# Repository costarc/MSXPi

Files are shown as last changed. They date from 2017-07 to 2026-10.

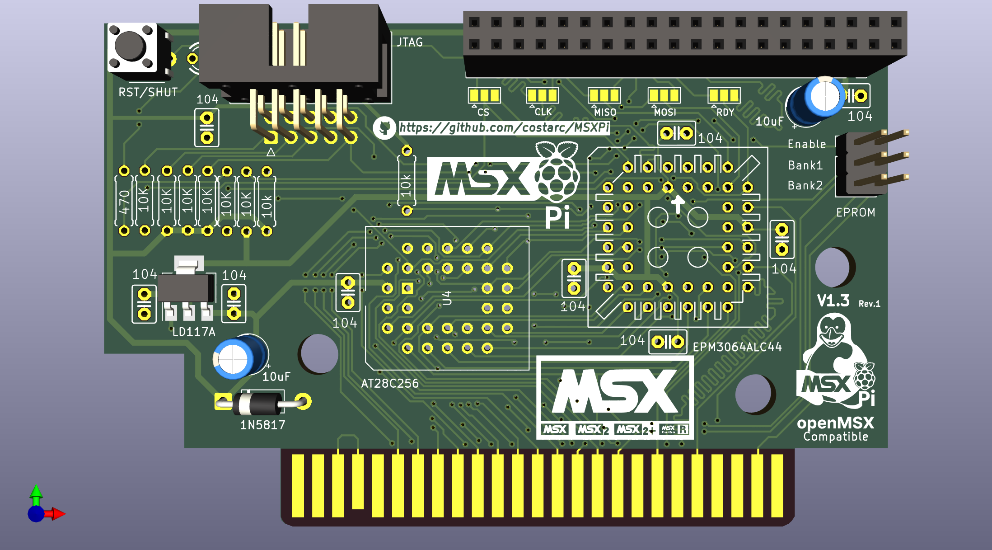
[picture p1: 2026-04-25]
hardware/Schematic/MSXPi.png

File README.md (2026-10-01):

# MSXPi

MSXPi is a hardware interface and software solution that lets MSX computers
control and use Raspberry Pi resources. The interface exposes I/O ports that
the MSX reads and writes, and the data appears on the Raspberry Pi side, where
a Python program (the *msxpi-server*) acts on it. Through it the MSX can reach
network drives, the internet, disk images, ROM archives, ChatGPT, an IRC
server, TCP/IP (via UNAPI) and the Raspberry Pi itself. A Raspberry Pi Zero W
or Zero 2 W is the recommended companion board.

MSXPi also exists as a virtual device for **openMSX**: the emulated MSX gets
the same commands and the same server, with no hardware at all. See
[Quick Start 2 - openMSX](#quick-start-2---openmsx-no-hardware-needed).

Version 1.6 is the current release. What changed is in
[Release_Notes](Release_Notes); how to use everything is in the
[documents](documents) folder.

**Version 1.6 breaks software compatibility with previous ROMs and servers.**
Upgrade the whole set together: ROM, msxpi-server, the client commands (`.COM`
files) and, on real hardware, the CPLD firmware. A v1.6 ROM on older CPLD
firmware still works, using the slower polled transfers. To stay on an older
ROM, use the server from the matching `release/vX.Y` branch.

**About the DOS.** MSXPi's own ROM contains **MSX-DOS 1 (1.03) only**. It does not
contain Nextor or MSX-DOS 2. MSXPi *coexists* with them: Nextor or MSX-DOS 2 come
from another disk interface in the same MSX (for example a MegaFlashROM SCC+ SD),
and MSXPi's commands, BASIC extension and UNAPI work alongside them. The
EEPROM holds two ROMs, picked with the bank jumper: MSX-DOS 1 (**BANK2**) or
the BIOS only - `CALL MSXPI` and UNAPI, no disk system (**BANK1**) - for use
next to Nextor / MSX-DOS 2.

Contents

1. [How the pieces fit together](#how-the-pieces-fit-together)
2. [Quick Start 1 - Real hardware](#quick-start-1---real-hardware-msxpi-interface--raspberry-pi)
3. [Quick Start 2 - openMSX](#quick-start-2---openmsx-no-hardware-needed)
4. [Using MSXPi: the p commands](#using-msxpi-the-p-commands)
5. [Bugs and known limitations](#bugs-and-known-limitations)
6. [Repository structure](#repository-structure)

How the pieces fit together
===========================

    Real hardware:
    MSX  <-- I/O ports $56 $57 $5A -->  MSXPi interface  <-- GPIO -->  Raspberry Pi
    (p.com, pcopy, msxarch,             (CPLD + EEPROM with            (msxpi-server.py,
     BASIC CALL MSXPI, ROM BIOS)         the MSXPi ROM)                 Python 3)

    openMSX:
    MSX  <-- I/O ports $56 $57 $5A -->  MSXPiDevice      <-- TCP :5000 --> msxpi-server.py
                                        (emulated CPLD)                    (on your PC)

* **MSX side** - the ROMs in the interface's 32 KB EEPROM and the `.COM`
  programs that you copy to your MSX disk or SD card. The EEPROM image,
  `msxpi32k.rom`, holds two 16 KB ROMs:
  * `msxpibios.rom` - MSXPi BIOS, MSX-DOS 1 disk driver, `CALL MSXPI` for
    BASIC, Ethernet UNAPI;
  * `msxpibas.rom` - the same without the disk system: `CALL MSXPI` and
    Ethernet UNAPI only.
* **Interface** - a CPLD decodes ports $56/$57/$5A and shifts bytes to and
  from the Pi; since v1.6 it also holds the Z80 /WAIT line while a byte is in
  flight, so the MSX can move data with INIR/OTIR.
* **Server side** - `msxpi-server.py`, which runs on the Pi (GPIO link) or on
  your PC next to openMSX (TCP socket link). Everything it needs lives in one
  folder, the *MSXPi home directory*: `/home/pi/msxpi`.

Quick Start 1 - Real hardware (MSXPi interface + Raspberry Pi)
==============================================================

You will need:

* An MSXPi interface (built from `hardware/`; assembly notes in
  `documents/MSXPi Assembly Instructions.txt`) with an AT28C256 EEPROM.
* A Raspberry Pi Zero W / Zero 2 W (not a Pico - it cannot run Linux), with
  the 40-pin header on the side that matches your PCB, a micro SD card of 8 GB
  or more, and a PC to prepare it.
* An MSX with a disk or SD interface running MSX-DOS 1, MSX-DOS 2 or Nextor
  (MSXPi itself only has MSX-DOS 1 in its ROM; MSX-DOS 2 / Nextor must come
  from that other interface),
  and a way to copy files from your PC onto that disk. A second disk interface
  (Nextor / MSX-DOS 2) next to MSXPi is the best way to use it.
* Only if the CPLD is not programmed yet: an Altera USB-Blaster and Quartus
  13.0 SP1 on Windows.

Do the steps in order. Each ends with a check, so you know where a problem is.

### Step 1 - Program the CPLD (skip if it is already programmed)

1. Connect the USB-Blaster to the JTAG connector of the interface. The
   interface must be in the MSX slot and the MSX switched on.
2. In Quartus: Tools -> Programmer, mode JTAG, *Add File*, pick the `.pof` for
   your board, tick *Program/Configure* and *Verify*, *Start*.

   | Board | File (in `hardware/CPLD_Project`) |
   |---|---|
   | V1.3 Rev.1 (and boards built for v1.3 to v1.5) | `MSXPi_v1.6.pof` |
   | V1.1 Rev.1, V1.2.1b | `v1.1/MSXPi_v1.6_wait.pof` |
   | v0.8.2 / v1.0 (PCB v0.7 Rev.7) | `v0.8.2/MSXPi_v1.6_polled.pof` |

3. **Check:** in MSX BASIC, `PRINT INP(&H57)` must not print 254 or 255 (that
   means no CPLD answered); `pver` shows the same build ID in readable form later. Older boards need a few extra settings - see
   `hardware/CPLD_Project/LEGACY_BOARDS.md` and `documents/Legacy Support.odt`.

### Step 2 - Write the ROM to the EEPROM with AT28C256.COM

The EEPROM (32 KB) holds `msxpi32k.rom`: two 16 KB ROMs, one per bank. It is
written from the MSX itself, so you need a working MSX with a disk drive and
the interface plugged in. The Raspberry Pi does not need to be attached yet.

| Bank jumper (as on the PCB) | EEPROM half | ROM | The MSX gets |
|---|---|---|---|
| **BANK2** (EEPROM A14 = CPU A15) | lower | `msxpibios.rom` | MSX-DOS 1 from the Pi, `CALL MSXPI`, Ethernet UNAPI |
| **BANK1** (EEPROM A14 = CPU A14) | upper | `msxpibas.rom` | `CALL MSXPI` and Ethernet UNAPI, no disk system and no extra drives |

1. Copy `software/target/at28c256.com` and `software/target/msxpi32k.rom` to
   your MSX disk or SD card. (Both are also on the MSXPi boot disk.)
2. Set the bank jumper to **BANK2**. The EEPROM can only be programmed in
   that position: the chip's write-protection commands only reach the right
   addresses when its A14 follows CPU A15.
3. Boot MSX-DOS (from your disk interface) and list the ROMs the tool can see:

        at28c256 /i

   If the interface already holds a bootable ROM, remove its enable jumper
   (`SLTSL`, `CS12` on some boards) first, otherwise the MSX finds it, boots
   from it and the tool cannot write. Note the slot number of the interface.
4. Write the ROM (2 is the slot number here; use yours):

        at28c256 /s 2 msxpi32k.rom

   Always write the whole 32 KB file in one go: the tool erases the entire
   chip before writing, so writing one 16 KB ROM on its own wipes the other
   bank. The tool write-protects the EEPROM (software data protection) when
   it is done. If your chip fails to program, repeat with `/r`, which writes
   slowly.
5. Switch the MSX off and set the jumpers for how you will use it:

   * **Booting MSX-DOS 1 from a disk image on the Pi:** close `SLTSL`, bank
     jumper on **BANK2**. The Pi must finish booting first, so the first cold
     boot takes a few minutes. Press ESC during boot to go straight to BASIC.
   * **With another disk interface (recommended):** close `SLTSL`, bank
     jumper on **BANK1**, and put MSXPi in a higher slot than the disk
     interface. The MSX boots Nextor / MSX-DOS 2 from the other interface;
     MSXPi adds no drives and uses almost no memory, and `CALL MSXPI` in
     BASIC and the Ethernet UNAPI are available.
   * **MSXPi ROM off:** remove `SLTSL`. MSXPi then works only through the
     `.COM` commands - no `CALL MSXPI` and no ROM UNAPI.

   The EEPROM answers in every page of its slot, so the bank that is not
   selected appears at 8000h. The two ROMs are built to tolerate each other
   there; always write them together, from the same `msxpi32k.rom`.
6. **Check:** in BASIC, `CALL MSXPIVER` prints the ROM version; with BANK1 it
   ends in "(no DOS)".

### Step 3 - Prepare the Raspberry Pi

Install a fresh Raspberry Pi OS Lite and run the MSXPi setup script. (The
old ready-made SD card image is no longer offered.)

1. Write *Raspberry Pi OS Lite (32-bit)* to the SD card with Raspberry Pi
   Imager (https://www.raspberrypi.com/software). In its settings choose user
   name `pi`, enable SSH and enter your WiFi details.
2. Boot the Pi, log in (SSH, or keyboard and HDMI) and run:

        wget https://tinyurl.com/MSXPi-Setup
        chmod 755 MSXPi-Setup
        bash ./MSXPi-Setup

   The script checks the Pi, the network and the clock, installs everything
   below, starts the server, checks that it runs, and reboots (a few minutes).
   It asks which board you have; to skip the question add `--board v1.3`,
   `--board v1.1` or `--board old` (see the table below). `--help` lists the
   other options (WiFi, `--no-reboot`, ...). It is safe to run again: it
   updates the server and repairs what is missing, and never overwrites
   `msxpi.ini`.

What the setup gives you (check it, or do it by hand):

* **Python 3** with the modules `requests`, `fs` and `RPi.GPIO`. `fs` needs
  `pkg_resources`, so a `setuptools` older than version 81 must be present
  (`python3 -m pip install fs "setuptools<81" --break-system-packages` if you do it
  by hand). The packages `unar`, `lhasa`, `unzip`, `mpv`, `alsa-utils` and
  `smbclient` are for unpacking archives, playing audio and reading network
  shares; `iptables` gives the MSX its network; `gcc` builds the native GPIO
  engine. PChess also needs the Python package `chess`
  (`requirements-pchess.txt`); the rest of the server works without it.
* **The MSXPi home directory `/home/pi/msxpi`**, owned by user `pi`. The path is
  built into the server (the environment variable `MSXPI_HOME` overrides it).
  It holds:

  | File | Purpose |
  |---|---|
  | `msxpi-server.py` and the `msxpi_*.py` modules (`msxpi_cmd_*.py`, `msxpi_transport.py`, `msxpi_settings.py`, ...), `mapper_detect.py` | the server and its modules |
  | `native/` | the native GPIO library `libmsxpi_gpio.so`, built on the Pi (without it the server falls back to slower Python GPIO and says so in its log) |
  | `msxpi.ini` | your settings, see below |
  | `disks/msxpiboot.dsk`, `disks/tools.dsk` | drives A: and B: for the MSX-DOS 1 boot mode |
  | `msxpi-monitor`, `msxpi-tcpip-setup.sh`, `update.sh` | helpers |

* **A systemd service** (`msxpi-monitor`) that starts the server at boot. To
  watch it work, run it by hand: `cd /home/pi/msxpi && python3 msxpi-server.py`.
* **msxpi.ini**, copied from the template that matches your PCB
  (`software/Server/Python/src`):

  | Board | Template |
  |---|---|
  | V1.3 (and later) | `msxpi-JumperRight.ini` |
  | V1.1 Rev.0 | `msxpi-JumperRight_PCBV1.1Rev.0.ini` |
  | Older boards | `msxpi-JumperLeft.ini` |

  A board **without** the shutdown push-button needs `var RPI_SHUTDOWN=none`.
  Optional keys: `OPENAIKEY` and `OPENAIMODEL` (ChatGPT), `RAPIDAPIKEY`,
  `FINNHUBKEY`, `TWELVEDATAKEY`, `ALPHAVANTAGEKEY` (stock quotes),
  `WIFISSID`, `WIFIPWD`, `WIFICOUNTRY`. From the MSX you can change any of
  them with `p set NAME value`.

Insert the SD card, plug the Pi into the interface **with its component side
facing you**, and switch the MSX on. The interface LED lights when the server
is running.

### Step 4 - Copy the MSX-side programs

Copy the contents of `software/target` (at least `p.com`, `pcopy.com`,
`pver.com`, `msxarch.com`, `msxarch.ini`, `LOADROM.COM`, `INL.CFG` and the
`.BAS` programs) to your MSX disk or SD card.

**Check:** at the MSX-DOS prompt type

        pver

It prints the board (build ID, CPLD, `/WAIT` yes or no) and the server version.
"Connection error" means the Pi is still booting (the first boot may take three
minutes), the interface is not seated, or the ROM and server versions do not
match. Press CTRL+ESC, wait five seconds, and try again.

### Step 5 - Connect to WiFi and the network

        p set WIFISSID Your Wifi Name
        p set WIFIPWD YourWifiPassword
        p wifi set
        p reboot

`p wifi` alone lists the interfaces and addresses. For TCP/IP programs (UNAPI:
InterNestor Lite, telnet, HGET) the Ethernet driver is in the ROM, and the Pi
builds the network behind it with `msxpi-tcpip-setup.sh` when the server
starts. If the Pi had no default route at boot, run `p netreset`. Then:

        MSR I           (MSX-DOS 1 only - do NOT run RAMHELPR)
        INL I
        HOST GOOGLE.COM

`HOST` printing an address means the whole path works. `p wlanreset` resets the
Pi's WiFi. Details: `software/UNAPI/README.md`.

### Step 6 - Try it

        p dir /home/pi/msxpi
        p run uname -a
        pcopy m:pver.com
        msxarch                     (browse and start ROM games from the network)
        LOADROM game.rom /N
        p chatgpt Tell me a fun fact about MSX

### Updating

* MSX disk (the `.COM` files): run `msxpiupd.bat` (network required).
* Server: run the setup script again, from the Pi or from the MSX:

        p run wget https://tinyurl.com/MSXPi-Setup
        p run chmod 755 MSXPi-Setup
        p run sudo ./MSXPi-Setup

* ROM: the updater downloads it but never writes it - repeat Step 2.

Update all three together. Run `p shut` before you switch the MSX off: the Pi is
powered by the MSX, and an SD card can be corrupted by a sudden power cut.

More detail with pictures: `documents/Quick Start.odt` and the "Hard Way" tutorial
(installing Raspberry Pi OS from scratch; Portuguese version available) in the
`documents` folder.

Quick Start 2 - openMSX (no hardware needed)
============================================

The MSXPi device for openMSX emulates the interface, including the CPLD /WAIT
flow control, and talks over a local TCP socket to the same `msxpi-server.py`
that runs on the Pi. The p commands, BASIC, msxarch, ChatGPT and UNAPI
networking all work as on real hardware, and what you write under openMSX runs
unchanged on the real interface.

### Windows: install everything in one step

1. Download
   [`msxpi-openmsx-install.bat`](https://raw.githubusercontent.com/costarc/MSXPi/master/software/Server/Setup/msxpi-openmsx-install.bat)
   (right-click the link, *Save link as*) and double-click it. It needs no
   administrator rights, and downloads everything from this repository and
   from the MSXPi build of openMSX.
2. It installs Python 3 and the packages the server uses, 7-Zip, Stockfish
   and mpv (with winget), then:
   * `C:\home\pi\msxpi` - the server, `msxpi.ini` and the `disks` folder
   * `C:\home\pi\msxpi\openMSX` - openMSX with the MSXPi device, the
     `MSXPi.xml` extension and `msxpibios.rom`
   * `C:\home\pi\msxpi\start-openmsx.bat` and an **MSXPi** desktop shortcut
3. Double-click the **MSXPi** shortcut. It starts the server in its own window,
   then openMSX as a Panasonic FS-A1WSX with the MSXPi and 4 MB RAM
   extensions. The MSX boots MSX-DOS from the MSXPi boot disk
   (`disks\msxpiboot.dsk`); no floppy image is needed.
4. Go on with [Step 4 - Try it](#step-4---try-it).

Notes:

* **Machine ROMs.** openMSX ships only the free C-BIOS ROMs. The FS-A1WSX
  needs its own system ROMs: put them in
  `%USERPROFILE%\Documents\openMSX\share\systemroms` (or in
  `C:\home\pi\msxpi\openMSX\share\systemroms`).
* **Internet on the MSX.** Run the installer with `-Network` (from a command
  prompt: `msxpi-openmsx-install.bat -Network`). It also installs the TAP
  driver, which asks for administrator rights once, and the launcher then sets
  up the MSX network when needed. See
  [Internet from the MSX in openMSX](#internet-from-the-msx-in-openmsx-windows).
* **Updating.** Run the installer again. It refreshes the server, the ROM and
  the extension, and replaces openMSX when a newer MSXPi build is required. It
  keeps `msxpi.ini` and the disk images.

Steps 1 to 3 below are the manual installation, for Linux and macOS or to set
things up by hand on Windows.

### Step 1 - Install openMSX with the MSXPi device

The official openMSX lives at https://github.com/openMSX/openMSX
(binaries and documentation at https://openmsx.org). The MSXPi device is not in
the official build yet, so download openMSX from the MSXPi fork instead:

* **https://github.com/costarc/openMSX/releases** - take the newest release for
  your operating system; the notes of each release say what it contains. Unpack
  it anywhere. It includes the MSXPi extension (`MSXPi.xml`) and the matching
  `msxpibios.rom`.
* Use the fork release, the `msxpibios.rom`, and the server from the same MSXPi
  version - the device, ROM and server share one protocol.
* If you keep your own openMSX, the two data files are also in this repository:
  `software/openMSX/share/extensions/MSXPi.xml` goes to openMSX's
  `share/extensions`, and `software/target/msxpibios.rom` goes to
  `share/systemroms` (the XML checks its sha1). The `MSXPiDevice` itself is only in
  builds of the fork.
* Two more extensions come from the same build (`software/build`, openMSX
  stage): `MSXPiBasic` - the BIOS-only ROM (`msxpibas.rom`), as on a board with
  the jumper on BANK1 - and `MSXPi32K`, the whole 32 KB EEPROM with the board's
  jumpers as openMSX settings, read at reset:
  `set msxpirom_bank BANK2|BANK1` (default BANK2) and
  `set msxpirom_sltsl ON|OFF` (default ON). `MSXPi32K` needs a fork build with
  EEPROM support in `MSXPiDevice` (branch `feature/msxpi-eeprom-jumpers`).

### Step 2 - Python and the MSXPi home directory

* **Python 3** (3.9 or newer; on Windows from python.org or the Microsoft
  Store, with *Add to PATH*).
* **Python modules:** `python -m pip install requests` is all the server needs
  to start. Some commands need more: `certifi` and `chess` for pchess, `Pillow`
  and `playwright` (then `python -m playwright install chromium`) for
  renderpage.
* **7-Zip** (`7z.exe` on the PATH) for zip, lzh, pma and 7z archives, used by
  msxarch and `pcopy /z`. On Linux/macOS install `p7zip`, `lhasa` and `unar`.
* **The MSXPi home directory.** The server has `/home/pi/msxpi` built in
  (set `MSXPI_HOME` to use another folder). On Linux and macOS create that
  folder. On Windows the path resolves on the *current drive*, so create
  `C:\home\pi\msxpi` and start the server from drive C:. Put in it:
  `msxpi-server.py`, `mapper_detect.py` and every `msxpi_*.py` module (all from
  `software/Server/Python/src`; the server imports them from its own folder), `msxpi.ini` (copy `msxpi-JumperLeft.ini`
  and rename it), and a `disks` folder with `msxpiboot.dsk` and `tools.dsk` from
  `software/target/disks`.
* Add the keys you need to `msxpi.ini` (for example `OPENAIKEY` for ChatGPT).
  Commands that only make sense on a Pi (`wifi`, `reboot`, `shut`, `play`) answer
  "Command not supported on this platform".

### Step 3 - Start the server, then openMSX

        cd C:\home\pi\msxpi           (Linux/macOS: cd /home/pi/msxpi)
        python msxpi-server.py

The server listens on TCP port **5000**. Now prepare a folder that openMSX uses
as disk A:. Call it `FloppyA`, copy `MSXDOS.SYS` and `COMMAND.COM` from
`software/target/disks` into it, and add the MSXPi commands from
`software/target`. Then start openMSX with the extension:

        openmsx -machine Panasonic_FS-A1WSX -ext MSXPi -diska FloppyA

Any MSX2 with 64 KB RAM will do, and Nextor on an SD/IDE image works too.
The fork also has an `MSXPiNoROM` extension (the ports without the ROM), for
trying `BLOAD"MSXPIEXT.BIN",R` the way an interface without an EEPROM is used.

**Optional: a different port.** The device takes the TCP port from the openMSX
setting `msxpiserver_port` (default 5000). Change it in the openMSX console
(F10) and the device reconnects at once:

        set msxpiserver_port 5001

Make the server listen on the same port with the environment variable
`MSXPI_PORT` (for example `set MSXPI_PORT=5001` on Windows before starting it). Use this when port 5000 is taken, or to run two
emulators with two servers.

### Step 4 - Try it

At the MSX-DOS prompt:

        pver
        p dir /
        p set
        msxarch
        p chatgpt Tell me a funny fact about MSX

`pver` reports `/WAIT: yes (burst)` when the device emulates the wait flow
control. "Connection error" means the server is not running, the ports differ,
or the ROM and server versions do not match. Read the log window of the server:
it prints every command it receives.

### Internet from the MSX in openMSX (Windows)

The MSXPi extension carries real network traffic, so InterNestor Lite, telnet,
HGET and the other UNAPI clients work in the emulator exactly as they do on
hardware. The emulated MSX gets its own subnet (192.168.99.0/24) and Windows
NATs it out through whichever interface carries your default route - the same
arrangement the Raspberry Pi uses, and for the same reason: bridging cannot
work over WiFi, because an access point will not forward frames whose source
MAC is not the associated station's.

This works best with an openMSX whose MSXPi device implements the v1.6
hardware /WAIT flow control (openMSX/openMSX#2194). An older build still
works: the ROM probes for wait mode, does not find it, and falls back to the
polled transport - the same path MSXPi has always used under emulation. What
you lose is the v1.6 speedup, not the connection.

**With the Windows installer**, run it with `-Network` instead of steps 1 and
2: it installs the TAP driver, and the MSXPi desktop shortcut sets up the
network (asking for administrator rights) whenever it is missing, including
after a reboot. Then go on with step 3.

#### Step 1: Install the OpenVPN TAP driver

Install OpenVPN (https://openvpn.net/community-downloads/) and keep the "TAP
Virtual Ethernet Adapter" component, or install the standalone tap-windows6
driver on its own. Afterwards an adapter named "OpenVPN TAP-Windows6" appears
in Network Connections - nothing else about OpenVPN is used or needs
configuring.

#### Step 2: Run the setup once, as Administrator

From an elevated PowerShell:

          powershell -ExecutionPolicy Bypass -File software/Server/Setup/msxpi-tcpip-setup.ps1

It reports what it did:

          adapter: OpenVPN TAP-Windows6  [TAP-Windows Adapter V9]
          uplink: Wi-Fi
          OpenVPN TAP-Windows6 up: 192.168.99.1/24 mtu 576
          NAT: 192.168.99.0/24 -> Wi-Fi
          dns: 192.168.1.254

and prints the InterNestor Lite settings to match. Note the "dns:" line - that
is the resolver the MSX should use.

This is NOT persistent across reboots; re-run it after a restart. To undo it
and give the adapter back to OpenVPN, add "-Down".

Windows generally allows only one NAT instance, and Docker Desktop, Hyper-V and
WSL each take one. If something already holds it the script names it and stops
rather than half-configuring.

#### Step 3: Start the server

          python msxpi-server.py

No administrator rights are needed for this part. It should print:

          eth: TAP device OpenVPN TAP-Windows6 up

If it says "TAP unavailable ... falling back to MockLink", something else has
the adapter open - a running OpenVPN session will do that. MockLink answers
every UNAPI call correctly and carries no traffic at all, so the MSX will look
configured and reach nothing.

#### Step 4: On the MSX

Start openMSX with the MSXPi extension, then:

          MSR I              (MSX-DOS 1 only - see below)
          INL I
          HOST GOOGLE.COM

`HOST` printing an address means the whole path works. The Ethernet UNAPI
driver is in msxpibios.rom, so nothing needs installing first: ETHUNAPI will
refuse, because the ROM already registers an ETHERNET implementation.

**Do not run RAMHELPR I.** It installs the UNAPI RAM helper on its own, and
MSR.COM installs the mapper support routines AND a helper - so MSR then finds a
helper already present and aborts, leaving INL to fail with "No mapper support
routines found". A cold boot clears it. Under Nextor or MSX-DOS 2, skip MSR
entirely: the mapper routines are already there.

If `HOST` answers "8: DNS not found" but the link is otherwise up, the resolver
is the problem rather than the network - INL.CFG ships with 1.1.1.1, and some
networks block public resolvers. Use the address the setup script printed:

          INL IP P 192.168.1.254

Using MSXPi: the p commands
===========================

Type `p` with no arguments (or `p /help`) to list them. All work under MSX-DOS 1,
MSX-DOS 2 and Nextor. Paths can be on the Pi, on the network (http, https, ftp,
smb) or on one of the virtual drives set with `p set`: `m:` (your local
server), `r1:` and `r2:` (MSX1 and MSX2 ROMs on msxarchive.nl).

| Command | What it does |
|---|---|
| `p ver`, `pver` | server version; `pver` also shows the board, CPLD build and /WAIT support |
| `p cd`, `p dir` | change and list the current path |
| `p run <cmd>` | run a command on the Pi; use `::` for a pipe |
| `p date` | set the MSX date and time from the Pi |
| `p set [NAME value]` | show or change MSXPi variables (saved in `msxpi.ini`) |
| `p wifi`, `p wifi set` | list interfaces / apply WIFISSID and WIFIPWD |
| `p wlanreset [secs]`, `p netreset [secs]` | reset the Pi's WiFi / rebuild its TCP/IP setup for UNAPI |
| `p music`, `p play`, `p vol` | audio playback and volume on the Pi |
| `p reload A:` (or `B:`) | reload a drive's disk image |
| `p reboot`, `p shut`, `p restart` | reboot / shut down the Pi, restart the server |
| `p chatgpt <question>` | ask ChatGPT (needs OPENAIKEY) |
| `p showpage [/4\|/6\|/8] <url>` | render a web page on the MSX screen |
| `pchess` | chess on an MSX2 (128 KB VRAM), local or over IRC (see `software/Client/src/PCHESS.md`) |
| `nitros` | on-demand NitrOS-9 console on the Pi with the MSXPi interface, or in openMSX on Windows/Linux, with file exchange; see [setup](documents/NITROS-Users-Guide.md) |
| `ssh user@host [port]` | interactive SSH terminal through the MSXPi Raspberry Pi; prompts and passwords appear on the MSX |
| `pcopy` | copy Pi/network file to the MSX drive (`/z` unpacks archives) or an MSX file to the Pi |
| `msxarch` | browse ROM repositories (listed in `MSXARCH.INI`) and start a game |
| `LOADROM name /N` | load a plain ROM or MegaROM from the network |
| `at28c256` | write the interface EEPROM |
| `msxpiupd.bat` | update the MSX-side files |

From BASIC use `CALL MSXPI("1,C000,dir /home/pi/msxpi")` (see `target/API.BAS`).
The full reference, with examples, is in `documents/MSXPi Users and Developers Guide.odt`.

Bugs and known limitations
==========================

* **Upgrade as a set.** A v1.6 ROM, server, `.COM` files and CPLD are meant to
  be used together. Mixed versions usually show up as "Connection error", not as
  a clear refusal.
* **/WAIT bursts need a v1.6 CPLD image and a board that wires /WAIT.** Boards
  built for v0.8.2 and v1.0 (PCB v0.7 Rev.7) have no /WAIT connection and run
  the polled transfers only. At the time of writing, disk writes from the MSX
  also use the polled transfer while reads use bursts.
* **Older boards need settings**: `RPI_SHUTDOWN=none` without the push-button,
  and `GPIO_CS_SETUP_NS=1000` on the v0.8.2 board. On that board the EPROM
  /OE jumper must be on CS1, never CS12, or programs that call EXTBIO (`p`,
  `pcopy`, `pver`) hang the MSX. See `hardware/CPLD_Project/LEGACY_BOARDS.md`.
* **MSXPi only carries MSX-DOS 1.** Nextor and MSX-DOS 2 are not in the MSXPi
  ROM; they run from another disk interface that MSXPi coexists with.
* **Booting MSX-DOS 1 from the Pi is slow and fragile.** It needs the Pi to
  finish booting first and depends on the disk images; use another interface
  with Nextor or MSX-DOS 2 for daily work. Do not delete files on drive A: in
  that mode.
* **A stuck transfer needs CTRL+ESC.** Hold CTRL and press ESC to abort, wait
  about five seconds while the server resynchronises, and retry. ESC alone is
  an ordinary key and never aborts a transfer. If commands keep failing, restart
  the server (`p restart`) or reboot the Pi.
* **msxarch and MegaROMs.** Mappers detected: plain, Konami, Konami SCC, ASCII8
  and ASCII16. Other mappers, ROMs that need more RAM than the MSX has, and some
  titles that rewrite their own bank switching are rejected with a reason or may
  not run. Bank-switch writes are patched by the server, so what runs is not byte-for-byte the original ROM.
* **UNAPI/TCP/IP.** Do not run `RAMHELPR` before `MSR` under MSX-DOS 1 (INL then
  fails with "No mapper support routines found"; a cold boot clears it). If
  `HOST` answers "8: DNS not found" the resolver, not the link, is the problem:
  use `INL IP P <address>`. Under openMSX on Windows the TAP setup script must be
  run again after every reboot, only one Windows NAT instance can exist (Docker
  Desktop, Hyper-V and WSL each take one), and if the server prints "falling back
  to MockLink" the MSX looks configured but reaches nothing.
* **The server on Windows and macOS** runs the commands that make sense there;
  `wifi`, `reboot`, `shut`, `play`/`music` and `vol` are Raspberry Pi only.
* **Hardware compatibility.** Some MSX models have unusual slot or bus
  implementations and may not work; MSX-DOS needs 64 KB RAM. The Pi header must
  face the correct way for your PCB (a Zero WH has its header on the wrong side
  for the standard PCB).
* **ChatGPT and stock commands** need your own API keys in `msxpi.ini`; no key
  ships with MSXPi.
* **Tests.** Server unit tests are in `software/Server/Python/tests`; the
  UNAPI harness is in `software/UNAPI/harness`.
* The PDF copies of the documents in `documents` may be older than the `.odt`
  files.

Report problems at https://github.com/costarc/MSXPi/issues.

Repository structure
====================

Branches:

    master          the most recent code; may change within minutes - expect bugs,
                    and fixes just as fast
    release/vX.Y    one branch per release (v0.8.2, v1.0, v1.1, v1.2.1b, v1.3,
                    v1.4, v1.5, v1.6); use these for a known-good state
    feature/*, fix/*, docs_*
                    short-lived working branches; they appear and disappear, and
                    I recommend you do not use them

Directories:

    MSXPi
    |-- software
    |   |-- asm-common
    |   |   |-- include          BIOS routines for assembly (msxpi_bios.asm, include.asm, ...)
    |   |   `-- transport        generator for the /WAIT burst transfer code
    |   |-- C-common
    |   |   |-- header           msxpi.h - the C BIOS API
    |   |   `-- lib              msxpi-bios.c
    |   |-- ROM/src
    |   |   |-- BIOS             BIOS-only ROM bank (msxpibios.asm); BASIC extension (msxpiext.asm)
    |   |   `-- MSX-DOS          disk driver and MSX-DOS 1 kernel sources
    |   |-- Client/src           p, pcopy, pver, msxarch, pchess, showpage, templates, at28c256
    |   |   `-- loadrom          the LOADROM.COM network patch
    |   |-- ROM-Patcher          ROM patch profiles used by msxarch
    |   |-- Server
    |   |   |-- Python/src       msxpi-server.py and its msxpi_*.py modules, mapper_detect.py,
    |   |   |                    ini templates, native GPIO engine (native/)
    |   |   |-- Python/tests     server unit tests
    |   |   `-- Setup            setup scripts (Pi and Windows), update.sh, msxpi-monitor
    |   |                        and its systemd unit
    |   |-- UNAPI                Ethernet UNAPI: sources, tools, INL, test harness, documentation
    |   |-- openMSX              MSXPiDevice source, extension XML, build files
    |   |-- target               everything you copy to the MSX (.COM, .BAS, ROM, disks)
    |   |-- docs                 mapper, ROM and PChess IRC design notes
    |   `-- make.bat, make.sh    build scripts for the MSX-side programs
    |-- hardware
    |   |-- CPLD_Project         VHDL, Quartus project, .pof images for every board
    |   `-- Schematic            KiCad schematic and PCB, Fabrication, BOM
    `-- documents                Users and Developers Guide, C BIOS Developers Guide,
                                 Quick Start, Legacy Support, tutorials

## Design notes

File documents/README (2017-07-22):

 |===========================================================================|
 |                                                                           |
 | MSXPi Interface                                                           |
 |                                                                           |
 | Version : 0.8.1                                                           |
 |                                                                           |
 | Copyright (c) 2015-2016 Ronivon Candido Costa (ronivon@outlook.com)       |
 |                                                                           |
 | All rights reserved                                                       |
 |                                                                           |
 | Redistribution and use in source and compiled forms, with or without      |
 | modification, are permitted under GPL license.                            |
 |                                                                           |
 |===========================================================================|
 |                                                                           |
 | This file is part of MSXPi Interface project.                             |
 |                                                                           |
 | MSX PI Interface is free software: you can redistribute it and/or modify  |
 | it under the terms of the GNU General Public License as published by      |
 | the Free Software Foundation, either version 3 of the License, or         |
 | (at your option) any later version.                                       |
 |                                                                           |
 | MSX PI Interface is distributed in the hope that it will be useful,       |
 | but WITHOUT ANY WARRANTY; without even the implied warranty of            |
 | MERCHANTABILITY or FITNESS FOR A PARTICULAR PURPOSE.  See the             |
 | GNU General Public License for more details.                              |
 |                                                                           |
 | You should have received a copy of the GNU General Public License         |
 | along with MSX PI Interface.  If not, see <http://www.gnu.org/licenses/>. |
 |===========================================================================|

Raspberry Pi setup

This is the process to setup MSXPi using the custom Raspbian Image
==================================================================

1. Download MSXPi ready-to-go Raspbian Jessie Lite minimal image zip file from:
https://www.dropbox.com/home/MSXPi/msxpi_raspbian.zip

2. Unzip the file.
Under Mac OS or Linux:
unzip msxpi_raspbian.zip

3. Insert / connect a micro-SD Card into the computer (8GB minimum)

4. Identify the device corresponding to the SD card. On Linux it should be /dev/sdb for example.
Make sure you do not use the device corresponding to your computer disk, or you will overwrite it, and loose all your data - for example, your SD card on Linux should never be /dev/sda, and on Mac OS should never be /dev/disk0 or /dev/disk1.

5. Transfer the raspbian image to the SD card.
For example, on Linux:
sudo dd if=msxpi_raspbian.zip of=/dev/sdb

On Mac OS:
sudo dd if=msxpi_raspbian.zip of=/dev/disk2

6. Insert the card on Raspberry Pi and switch it on. MSXPi server process will start automatically during boot.

This is the process to setup MSXPi using the official Raspbian Jessie Lite image
================================================================================

1. Download Raspbian Jessie Lite minimal image zip file from:
https://downloads.raspberrypi.org/raspbian_lite_latest
On this guide, the file downloaded was 2017-07-05-raspbian-jessie-lite.zip

2. Unzip the file.
Under Mac Os or Linux:
unzip 2017-07-05-raspbian-jessie-lite.zip

3. Insert / connect a micro-SD Card into the computer (2GB minimum)

4. Identify the device corresponding to the SD card. On Linux it should be /dev/sdb for example.
Make sure you do not use the device corresponding to your computer disk, or you will overwrite it, and loose all your data - for example, your SD card on Linux should never be /dev/sda, and on Mac OS should never be /dev/disk0 or /dev/disk1.

5. Transfer the raspbian image to the SD card.
For example, on Linux:
sudo dd if=2017-07-05-raspbian-jessie-lite.img of=/dev/sdb

On Mac OS:
sudo dd if=2017-07-05-raspbian-jessie-lite.img of=/dev/disk2

Recommended Raspberry distribution: Raspbian Lite
Do no enable Windows (graphical user interface) for better performance.

6. Insert the card on Raspberry Pi and switch it on. Logon using the default Raspbian credentials:
User: pi
Password: raspberry

7. Edit file /home/pi/msxpi-setup.sh
Change the “said” and “ask” to your wifi network name, and wifi password respectively.

8. run msxpi-setup.sh
sudo /home/pi/msxpi-setup.sh

9. Reboot Raspberry Pi. 
MSXPi server process will start automatically during boot.

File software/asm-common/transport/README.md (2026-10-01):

# Shared MSX payload engine

`payload.z80` is the source of truth for the C and ASM file/disk payload loops.
Run `python3 software/asm-common/transport/generate.py` after editing it. Generated files
are checked in; `--check` and both client build scripts reject stale output.
The C build uses an SDCC ABI-0 stack adapter, while ASM callers pass DE=buffer,
BC=count and HL=running 16-bit checksum. IX/IY and alternate registers survive.
Zero bytes perform no I/O. Carry on return reports cancellation; successful
bytes alone update the pointer/count/checksum. Public BIOS APIs are unchanged.

There is one receive loop: request a transfer, then wait for status zero. openMSX
emulates the CPLD at port level, so the MSX side has no emulator path. Checksum
folding, headers, index checking, retries and disk commit decisions remain in
the protocol layer. The disk driver stages each sector in a private 512-byte driver buffer,
then uses LDIR or the DOS XFER helper to copy the entire sector across RAM slot
boundaries. The kernel's shared SECBUF is never used as scratch, since another
disk kernel may retain filesystem metadata there. BASIC/early boot retain RDSLT/WRSLT when XFER is unavailable. Failed
receive sectors are never copied to the caller. The old SEND_P1 workarea byte
is reserved; its offset is unchanged. PCOPY uses 8192-byte blocks in both
directions, so comparisons no longer mix block size with transfer direction.

Polling is intentionally still used for file/disk payloads. UNAPI ETH_END
leaves /WAIT off, and the existing link claim/disk busy guard prevents network
transactions from interleaving. The payload kernel does not acquire the link
itself: callers must hold it over the entire command/response, not each block.
The abort key is CTRL+ESC, read straight from the key matrix (ESC row 7 bit 2,
CTRL row 6 bit 1). ESC alone is an ordinary key, so programs such as vi over
SSH can use it, and the BIOS key buffer is never touched. CTRL+STOP is not used
because the BIOS already acts on it. The key is sampled at most 256 completed
bytes apart and during busy polling. The shared helper preserves PPI upper
bits, keyboard row selection and IFF state.
The existing C header-byte primitives are unchanged.

The DOS ROM uses three pre-existing alignment holes for generated TX, wait,
and CTRL+ESC code. Their DEFS expressions enforce capacity; GETSLT/GETWRK and the
UNAPI placement assertions remain active. The full ROM fits without moving
these entry points or removing features. Standalone ASM clients include the
same code contiguously. Assembly was checked with zmac and sjasmplus.

Networking has a specialized bounded, keyboard-free TX checksum loop. It
keeps the sum in E and calls readiness directly instead of the single-byte
wrapper. Its protocol/checksum differs from the file protocol, so it does not
call the foreground payload kernel. Existing UNAPI /WAIT receive bursts now
use the native Pi engine when enabled; READY stays high for the entire burst,
including across the 256-byte boundaries used by ordinary payload calls. A
GPIO backend unable to hold READY now fails instead of silently substituting
unsafe per-byte transfers.

No CPLD register, wire protocol, or openMSX device change is introduced. A fresh
Quartus 13.0sp1 build of the current CPLD used 46/64 macrocells. Its timing
constraints are incomplete; a successful fit is not proof of a new timing
margin. General file/disk INIR/OTIR bursts and CPLD prefetch/mailbox changes are
not enabled by this revision. Their need should be decided from hardware
measurements of this common software bottleneck removal.

## Verification

The tests below live in `software/Tests/`, which is **not part of the release
branch** - it is carried on the development branches (`performance` and the
feature branches cut from it). Check one of those out to run them.

- `python3 software/Tests/test_payload_z80.py`: executes assembled SDCC output
  with libz80ex. RX/TX and ABI checks cover hardware/TCP status, lengths
  0/1/255/256/257/512/8192, checksum overflow, register preservation, IFF on/off,
  delayed readiness and CTRL+ESC both busy and ready (ESC alone must not abort). Network TX tests cover frame
  sizes through 1514, checksum, bounded timeout and absence of keyboard scans.
- `python3 software/Tests/test_native_gpio.py`: protocol framing/retries,
  native failure behavior, burst selection and wrapper boundaries.
- `cc -std=c11 -O2 -Wall -Wextra -Werror -fsanitize=undefined software/Tests/native_gpio_test.c -o /tmp/msxpi-native-test`
  followed by `/tmp/msxpi-native-test`: GPIO edge/byte model including continuous
  READY bursts and a timeout after partial completion.
- `python3 software/Tests/test_pcopy_receive.py`: rejects failed receive data
  before a disk write.
- `python3 software/Server/Python/src/test_msxpi_eth.py`: shuttle regression suite.
- `software/Tests/pcopy_emulator.py`: full copy/upload against isolated served
  disks. See its `--direction` and `--fault` options; use an MSXPi-enabled openMSX.

The Linux pcopy, p and templatc clients build. The unchanged msxarch.c source
has malformed literals and triggers an SDCC internal compiler error; this
revision does not repair that separate application. Windows SDCC 4.0 and Linux
SDCC 4.2 ABI-0 PCOPY builds were both exercised in openMSX.

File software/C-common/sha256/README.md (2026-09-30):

# SHA-256 for MSX (Z80)

Standalone SHA-256 for SDCC / Fusion-C programs on MSX. The block function
is hand-written Z80 assembly; it is the one PChess uses for its IRC position
digests (`Client/src/pchess_sha.c`), about 7x faster than SDCC's C.

| file | |
|---|---|
| `sha256.h` | API: `sha256_init/update/final`, one-shot `sha256()`, `sha256_hex()` |
| `sha256.c` | implementation; Z80 assembly under SDCC, portable C elsewhere |
| `sha256t.c` | test program: FIPS 180-2 vectors, a streamed message, timing |

```c
#include "sha256.h"
uint8_t d[32]; char hex[65];
sha256("abc", 3, d);
sha256_hex(d, hex);          /* ba7816bf... */
```

Messages of any length (the length counter is 64-bit); `sha256_update()`
takes up to 65535 bytes per call and can be called any number of times.
Not reentrant: one hash at a time, never from an interrupt handler.

On a 3.58 MHz Z80 a 64-byte block takes about 0.2 s (a message under 56
bytes is one block). Size: about 1 KB of code plus 300 bytes of tables and
work areas.

## Build the test

From `software`, as for any client program, but with this directory:

```bat
sdcc --code-loc 0x106 --data-loc 0 -mz80 --no-std-crt0 --opt-code-size fusion.lib ^
  -L ..\..\..\MSX\MSX-C\WorkingFolder\fusion-c\lib ^
  ..\..\..\MSX\MSX-C\WorkingFolder\fusion-c\include\crt0_msxdos.rel C-common\sha256\sha256t.c
hex2bin -e com sha256t.ihx
```

`SHA256T` prints PASS for each vector and the time for ten one-block
hashes. On a PC, `gcc sha256t.c -o sha256t` runs the same checks against
the C version.

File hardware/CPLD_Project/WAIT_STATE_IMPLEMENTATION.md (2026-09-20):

# MSXPi CPLD v1.6 — /WAIT flow control: implementation report

Implements `WAIT_STATE_SPEC.md`. Date: 2026-08-30.
Toolchain: Quartus II 13.0sp1 (`EPM3064ALC44-10`), GHDL for simulation.

**Status: VALIDATED ON REAL HARDWARE in legacy mode.** An earlier revision of
this work failed on hardware; the cause and fix are recorded below because the
lesson generalises.

> ### The bug that cost a hardware cycle - root cause
> `wait_mode` was written as a plain asynchronous set/reset pair, which Quartus
> infers as a **latch with its enable tied to GND**. That cell has no guaranteed
> power-up state on MAX3000A, and a VHDL `:= '0'` initialiser does nothing about
> it - it only fools the simulator. The device powered up **already in WAIT
> mode**, so every `IN ($5A)` fired an extra transfer carrying `$00`, the byte
> stream desynchronised permanently, and `/WAIT` could stall the Z80 during boot.
>
> The differential testbench passed because GHDL honours the initialiser. Zero-
> delay RTL simulation cannot model the power-up state of an unclocked cell, so
> equivalence proved from an assumed initial state proved nothing about silicon.
>
> **Fix:** the mode bit is clocked by the port-write strobe, so it is an
> ordinary register and the device's power-on reset clears it. The check is
> mechanical: `wait_mode` must NOT appear in the *User-Specified and Inferred
> Latches* table of `MSXPi.map.rpt`. `started` uses the same construct but is
> self-correcting - its clear is `spi_en = '0'`, true whenever the bus is idle.

### Hardware result (2026-08-30)

Both v1.6 images were flashed to the real interface and exercised against
`msxpi-server.py` on the Pi:

| Image | Result |
|---|---|
| `alternative/MSXPi_v16_shifter_only.pof` | **PASS** — `p run cat msxpi-server.py`, **142 KB transferred, no errors** |
| `MSXPi_v16.pof` | **PASS** — same test, no errors |

That closes **spec acceptance criterion 3** (backward compatibility: every
existing binary works unchanged with the mode register never written) and proves
the sentinel shift register matches `SPI_ByteTransfer()` on silicon.

**Still open: criteria 4 and 5.** WAIT mode itself has never been enabled on
hardware — nothing has written `$57`. Do not enable it until the Pi-side SPI is
rewritten; see §6, which is a correctness constraint, not a performance one.

---

## 1. Answers to the three questions

**Does it fit?** Yes, comfortably. The /WAIT feature costs **+1 macrocell** when
bolted onto the untouched v1.3 SPI engine (47 → 48 of 64).

**Can the engine be re-written more cheaply, e.g. as a bit shifter?** Yes, and
it is worth doing. Replacing the three-state FSM and the 3-bit `bitcount` with a
single *sentinel shift register* makes the whole design — /WAIT included —
**smaller than v1.3 was**: 45 macrocells against 47, with registers down from 24
to 20 and shareable expanders down from 33 to 13. That is the version shipped as
`MSXPi.vhd`.

**What does it take without redesigning the interface?** Nothing on the PCB, no
new pins, no change to the Pi-side protocol, and no change to any existing MSX
binary. `WAIT_n` is already on PIN_37 and routed to J1 pin 7. The one thing that
changed outside the VHDL is a single Quartus setting (see §3).

---

## 2. Fitter resource report (spec deliverable RC-1)

All rows are real `quartus_sh --flow compile` runs on `EPM3064ALC44-10`.

| Build | Macrocells | Registers | P-terms | Shareable exp. | Fitter |
|---|---|---|---|---|---|
| v1.3 baseline | 47 / 64 (73 %) | 24 | 190 | 33 / 64 | OK |
| v1.6 shipped — shifter + /WAIT, mode bit registered | 46 / 64 (72 %) | 21 | — | — | OK |
| v1.6 shifter only, /WAIT removed (diagnostic) | 44 / 64 (69 %) | 20 | — | — | OK |
| the earlier revision shifter engine + /WAIT (latched mode bit — BROKEN) | 45 / 64 (70 %) | 20 | 157 | 13 / 64 | OK |
| v1.6 shipped + BUSDIR fix for `$57` (§7) | 44 / 64 (69 %) | 20 | — | — | OK |

Pins are unchanged at 30 / 34 in every build. So the shipped v1.6 leaves **19
free macrocells**, against 17 for v1.3 — there is *more* headroom after this
change than before it, which is what pays for the timeout counter in §6 should
you decide to fit the clock wire.

### Where the saving comes from

v1.3 tracks transfer progress with three separate things: a one-hot
`spi_state` (3 registers), a `bitcount` up-counter (3 registers plus an adder
and its expander chain), and the `D_buff_pi` receive register (8).

v1.6 folds all three into one 10-bit register. It is loaded with a single `'1'`
at bit 0 when a transfer starts, and MISO shifts in underneath it. Because every
received bit stays *below* the sentinel and every bit above it is still zero,
the sentinel is always the highest set bit — so both phase tests are free of any
counter:

```
pi_sr(9 downto 1) = 0   ->  nothing received yet, this edge is E1 (the load)
pi_sr(9)          = '1' ->  all eight bits are in, byte complete
pi_sr(7 downto 0)       ->  the received byte
```

14 storage elements become 10, the adder and its expanders disappear, and the
edge map seen by `msxpi-server.py` is bit-for-bit the same.

---

## 3. The one non-VHDL change: `MAX7000_OPTIMIZATION_TECHNIQUE`

`MSXPi.qsf` moves from `BALANCED` to `AREA`.

This is not cosmetic — without it the shifter design **fails to place**, with
`Error (163103): Can't pack LABs`. It is not a capacity problem: the failing run
still reports only 43 of 64 macrocells. It is LAB fan-in. `EPM3064A` has 4 LABs
sharing a limited PIA, and the shifter concentrates a wide decode cone into
fewer, busier cells. `AREA` costs 2 macrocells (43 attempted → 45 placed) and
places cleanly.

Checked and rejected: `AUTO FIT` (still fails), removing the stale `MAX_LABS 20`
assignment (still fails), narrowing the `started` clear term (still fails). The
v1.3 baseline fits at 47 under `AREA` just as it does under `BALANCED`, so the
setting change costs nothing if you ever rebuild v1.3 from this .qsf.

---

## 4. Software-side note: the `$57` mode register (spec deliverable)

| Operation | Effect |
|---|---|
| `OUT ($57),$01` | /WAIT flow control **ON** |
| `OUT ($57),$00` | /WAIT flow control **OFF** |
| `OUT ($57),`anything else | ignored (reserved) |
| `OUT ($56),$FF` | existing reset — **also forces the mode OFF** (FR-5) |
| `IN ($57)` | `$0E` when off, `$8E` when on |

**Version numbering.** The CPLD firmware jumps 1.3 -> 1.6, skipping 1.4 and 1.5,
so that it tracks the BIOS/release version rather than running on its own
sequence. Neither 1.4 nor 1.5 was released. `MSXPIVer` is unaffected: it stays
`"1110"` because it identifies the hardware generation, not the release.

`$57` bit layout:

| Bits | Meaning |
|---|---|
| 7 | `wait_mode` read-back (not required by the spec; lets the driver confirm the write landed) |
| 6 | **RESERVED — must stay `0`.** BC-2 guard, see below |
| 5–4 | free for future use |
| 3–0 | `MSXPIVer`, now `1110` (was `1101`) |

**Why bit 6 is a guard and not spare space.** `msxpi_bios.asm:97` detects openMSX
by testing `$57` against `$FE`, so the port must never read `$FE` or `$FF`
(**BC-2**). `MSXPIVer` is already `1110`, so with the mode bit at 7, allocating
bits 6..4 and setting them all would produce exactly `1111_1110` = `$FE` and
break interface detection in the field. Holding bit 6 at `0` caps the port at
`$BF` for ever, whatever bits 5..0 are later used for.

**`pver.com` needs a one-line change.** `DESCHWVER` uses the *whole* byte as an
index into `iftable`, so any high bit set walks off the end of the table. It
should mask the version field first (`and $0F`) before indexing. Note it is
already imperfect at `$0E`: `iftable` has 15 entries (0–14) and index 14 is
`ifukn`, so v1.6 currently prints *"Could not identify"* — a v1.6 string wants
adding at the same time.

Power-up state is OFF, and the mode is cleared by the existing reset, so the
driver must re-enable it after every `resetMSXPI`.

With the mode ON, a plain `IN ($5A)` *both* starts the SPI transfer and stalls
the Z80 until the byte has landed, so a block read becomes:

```
        ld      a,$01
        out     ($57),a         ; enable hardware flow control
        ld      hl,buffer
        ld      bc,$0000 + DATA_PORT1   ; B = count, C = $5A
        inir                    ; 21 T-states/byte, no polling at all
        xor     a
        out     ($57),a         ; back to legacy behaviour
```

`OTIR` works the same way on the write side. Note that `INIR` uses `B` as the
counter, so a block is at most 256 bytes per instruction.

Two behaviours worth knowing about:

- A read of `$5A` in WAIT mode when the Pi is **not** ready (`SPI_RDY` low)
  neither stalls nor starts a transfer. It returns the stale buffer, exactly as
  a legacy read would, and the existing checksum/retry layer catches it. This
  is deliberate — see §5.
- A read-started transfer sends `$00` on MOSI (the shift register is empty after
  the previous byte), which matches what `PIREADBYTE` already does with its
  `xor a / out ($56),a`. The server discards that byte anyway.

---

## 5. Safety — and one place the spec is self-contradictory

The spec is right that §5 is the critical risk, but **SR-1 as written cannot be
implemented.** It asks for release "after a bounded number of `SPI_SCLK` edges
… regardless of Pi state". A counter clocked by `SPI_SCLK` cannot count when
`SPI_SCLK` stops, and the Pi stopping is the only failure that matters. An
edge-counted timeout would protect against nothing, and it cannot satisfy
acceptance criterion 5.

What was implemented instead is a **clock-free release**, which came out of
reading the PCB rather than the RTL:

> `SPI_RDY` (U2 pin 39) has **R8, 10K to GND** — a pull-*down*.

So `SPI_RDY` is a term in the `/WAIT` equation itself:

```vhdl
wait_assert <= wait_mode and SPI_RDY and spi_en and (SPI_en_s or (not started));
WAIT_n      <= '0' when wait_assert = '1' else 'Z';
```

The moment the Pi stops driving `RPI_READY`, R8 takes the line low and `/WAIT`
releases combinationally in ~24 ns, with no clock involved at all. That covers
every case where the GPIO is released:

| Failure | Covered? | Why |
|---|---|---|
| Ctrl-C on `msxpi-server.py` | **Yes** | `except KeyboardInterrupt: GPIO.cleanup()` at line 4055 releases the pad |
| Clean exit / restart | **Yes** | same cleanup path |
| Pi rebooted, powered off, unplugged, never booted | **Yes** | pad is an input, R8 wins |
| Pi alive but slow | **Yes** — no hang | stall is bounded by the Pi's byte time, see §6 |
| **`kill -9`** | **No** | no cleanup runs, the pad keeps its last level, `SPI_RDY` stays high and `SCLK` never ticks again |

That last row is demonstrated, not assumed — phase 6 of the testbench models it
and confirms `/WAIT` is still asserted 200 µs later. On hardware that is a hung
MSX needing a power cycle.

Closing it needs a real clock, and the board is one wire away from having one:

> `CLOCK` (the 3.58 MHz bus clock) is present on **J1 pin 42** and is currently
> routed nowhere — it is a single-pad net. CPLD pins **1, 2, 43 and 44**
> (`GCLR/`, `OE2/GCLK2`, `GCLK1`, `OE1`) are all unconnected.

A bodge from **J1.42 → U2.43 (GCLK1)** gives a free-running global clock. A
6-bit counter on it is 64 × 279 ns = **17.9 µs**, which lands just under SR-3's
20 µs ceiling, and the 19 spare macrocells cover it. That is the only way to
satisfy SR-1's intent and acceptance criterion 5 in full. It is a PCB change, so
it is flagged here rather than done — **BC-5** says not to.

For SR-4's bench escape hatch, `/WAIT` runs U2.37 → J1.7 with nothing else on
the net, so cutting that trace (or fitting a 0 Ω link in it) isolates the signal
without touching anything else.

---

## 6. The thing that decides whether this is worth enabling

§1 of the spec already says the Pi-side SPI is the real bottleneck. Now that
`/WAIT` exists, that stops being a performance argument and becomes a
**correctness** one, because the stall length *is* the Pi's byte time:

| Pi-side SPI | Stall per byte | vs SR-3's ~20 µs |
|---|---|---|
| current `SPI_ByteTransfer()` (Python bit-bang, `sleep(10 µs)` per tick) | 200–600 µs | **10–30× over** |
| rewritten in C / hardware SPI peripheral | ~10–20 µs | within budget |

A 200–600 µs stall freezes the Z80 completely — no interrupt service, and no
`/RFSH` cycles for machines whose DRAM refresh depends on them. That is what
SR-3 is protecting, and it is why **the Pi-side rewrite is a prerequisite for
enabling this mode, not a follow-up to it.** The CPLD half is done and costs
nothing while the mode register stays off.

---

## 7. The spec's open questions

**Q1 — is 8 `SPI_SCLK` edges the right timeout?** Neither 8 edges nor an
FSM-state timeout works, for the reason in §5: no `SCLK`, no count. Replaced by
the `SPI_RDY` gate, which needs no clock, plus the clock-wire recommendation for
the one case it cannot cover.

**Q2 — should `BUSDIR_n` be asserted for reads of `$57`?** Yes, it is a real
latent bug on expanded slots, and it is free — 44 macrocells with the fix
against 45 without, because "A is one of `$56`/`$57`/`$5A`" decodes more cheaply
than the same set with `$57` carved out. Left **off by default** so BC-1 holds
literally; the one-line change is in `MSXPi.vhd`, commented, next to the current
assignment. It needs its own hardware regression pass because it changes legacy
behaviour.

**Q3 — is the `D_buff_msx` latch intentional?** Intentional and necessary; keep
it. `D` is only valid while the write cycle is on the bus, and there is no clock
at that instant to register it with — the CPLD's only clock arrives later, from
the Pi. It is also what makes a `/WAIT`-stretched `OTIR` write safe: the Z80
holds `D` for the whole stretched cycle, so the E1 edge samples a stable value
no matter how long the stall ran. Converting it to a registered capture would
mean clocking it on `SPI_SCLK`, which is exactly what the E1 edge already does.

---

## 8. Verification performed

`./sim.sh` elaborates v1.6 and `MSXPi_v13_reference.vhd` **side by side** off one
set of stimulus, with a Pi model that reproduces `SPI_ByteTransfer()` exactly
(RDY high → spin on CS → tick → 8 bit clocks → tick → RDY low).

```
PHASE 1  legacy mode is cycle-identical to v1.3      9662 samples of
         D, BUSDIR_n, SPI_CS, WAIT_n compared        0 mismatches
         4 bytes received + 4 sent, both engines agree
         read of $5A does not start a transfer (BC-1)
PHASE 2  WAIT mode: $57 reads $1E; 4 INIR-style reads return correct
         data after a real stall; OTIR write reaches the Pi
PHASE 3  FR-5: reset clears the mode, $57 back to $0E, legacy restored
PHASE 4  SR-2: Pi gone -> /WAIT never asserts and no stale transfer armed
PHASE 5  soak: 32 INIR reads + 32 OTIR writes, all verified
PHASE 6  residual risk: kill -9 -> confirms /WAIT stays stuck (see §5)
ALL TESTS PASSED
```

Timing, from the fitted design (`EPM3064ALC44-10`, -10 speed grade):

| Path | Delay |
|---|---|
| `IORQ_n` → `WAIT_n` | 35.0 ns |
| `RD_n` → `WAIT_n` | 24.0 ns |
| `A[]` → `WAIT_n` | 35.1 ns |
| `SPI_SCLK` → `WAIT_n` (release) | 23.9 ns |

**SR-5**: the Z80 samples `/WAIT` on the falling edge of TW, ~1.5 T-states
(≈419 ns at 3.58 MHz) after `/IORQ` falls. 35 ns against 419 ns is better than
10× margin even after bus-buffer delay. The negative slacks in
`MSXPi.sta.summary` are against TimeQuest's default fictitious clock — there is
no `.sdc` in this project and the v1.3 baseline reports the same (−13.2 ns
against −16.2 ns), so it is not a regression.

### Two real bugs the differential test caught

Both would have shipped without it, and neither shows up in a single-DUT
testbench.

1. **A race between `RESET` and `spi_en`.** Adding any logic to the `spi_en`
   path made it settle one gate later than `RESET`. At the end of a reset write
   `RESET` falls first, which opens the FSM's async-set guard for a few
   nanoseconds and fires a spurious transfer. Fixed by keeping `spi_en` as one
   flat expression at the same depth as `RESET` and moving the anti-retrigger
   guard into the FSM condition. The comment in `MSXPi.vhd` says so, because the
   constraint is invisible otherwise and the next edit will re-break it.

2. **A desynchronising stale transfer.** A WAIT-mode read issued while the Pi
   was absent still armed a transfer nobody clocked; when the server came back
   it serviced that stale transfer and the byte stream was permanently one byte
   out of step. Fixed by gating the read-trigger on `SPI_RDY` (SR-2 applied to
   the transfer start, not just to the stall).

---

## 9. Files

| File | What it is |
|---|---|
| `MSXPi.vhd` | v1.6 — shifter engine + /WAIT. **The one in `MSXPi.qsf`.** |
| `MSXPi_package.vhd` | `MSXPIVer = "1110"`, plus `WAITMODE_ON`/`WAITMODE_OFF` |
| `MSXPi.qsf` | unchanged except `MAX7000_OPTIMIZATION_TECHNIQUE AREA` (§3) |
| `MSXPi_v16.pof` | new programming file, from the verified build |
| `MSXPi.pof` | **untouched v1.3 image**, deliberately left in place |
| `tb_MSXPi.vhd` | differential testbench, 6 phases |
| `MSXPi_v13_reference.vhd` | v1.3 frozen as the equivalence reference (sim only, not in the .qsf) |
| `sim.sh` | runs the whole suite; `--wave` also opens gtkwave |
| `alternative/MSXPi_v16_shifter_only.vhd` + `.pof` | shifter engine with **all** /WAIT logic removed - the diagnostic build, 44/64 |

`MSXPi.pof` was **not** overwritten. Flash `MSXPi_v16.pof` when you want v1.6;
the known-good v1.3 image stays available under its original name so the two
cannot be confused at the programmer.

### Which variant to flash

`MSXPi_v16.pof` is the deliverable. `alternative/MSXPi_v16_shifter_only.pof` is
kept because it is the build that isolated the power-up bug: same SPI engine,
**all** /WAIT logic physically removed, so it can never drive `/WAIT`. If a
future change to the /WAIT path misbehaves, flashing it splits the problem in
one step. Both are validated on real hardware.

A third variant existed during development - /WAIT bolted onto the untouched
v1.3 SPI engine - and has been removed. Once the mode bit became a proper
register it no longer placed on EPM3064A under any fitter setting, and the
shifter engine is now hardware-proven, so it had no remaining purpose.

---

## 10. Suggested hardware bring-up order

1. Flash `MSXPi_v16.pof`, **write nothing to `$57`**, and confirm `pdir`,
   `ploadr`, MSX-DOS boot and the Nextor driver all behave exactly as before
   (spec acceptance 3). This is the whole backward-compatibility claim, and it
   is the test that matters most — the mode register being off means nothing
   else in this change can be reached.
2. Confirm `IN ($57)` returns `$0E`.
3. Only then a small `.COM` that enables the mode, does one short `INIR`, and
   disables it again. Expect it to be *slower* than polling until the Pi-side
   SPI is rewritten, and expect the machine to feel unresponsive during the
   burst — that is §6, not a bug.
4. Do not run acceptance test 5 (`kill` the server mid-transfer) as `kill -9`
   until the clock wire in §5 is fitted; it will hang the MSX. `Ctrl-C` is the
   case that is covered, and is the one worth testing.

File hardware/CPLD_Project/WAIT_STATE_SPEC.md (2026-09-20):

# MSXPi CPLD — Hardware Flow Control via /WAIT

**Specification for a separate work stream.**
Target firmware: MSXPi CPLD v1.6 (`MSXPIVer = "1110"`)
Baseline: v1.3 (`MSXPIVer = "1101"`), `hardware/CPLD_Project/MSXPi.vhd`
Date: 2026-08-30

---

## 1. Purpose

Today every byte moved between the MSX and the Raspberry Pi costs the Z80 a
**software** handshake: `CHKPIRDY` polls `CONTROL_PORT1` bit 0 in a loop before
each byte. Measured from the source, that is **~330 T-states (~92 µs at
3.58 MHz) per byte**, on top of whatever the Pi itself takes.

This change makes the CPLD assert the MSX bus `/WAIT` signal so the **hardware**
performs the handshake. The Z80 then transfers bytes with block I/O
(`inir` / `otir`, 21 T-states/byte) and the CPU is stalled by hardware exactly
as long as the Pi needs, with no polling instructions at all.

### Why this is needed

The consumer is a new UNAPI networking driver (Ethernet UNAPI + InterNestor
Lite). InterNestor Lite runs **from the 50/60 Hz timer interrupt hook** and
calls the Ethernet driver on every interrupt. Two hard consequences:

1. The transfer loop must be short and bounded — there is ~59,600 T-states per
   interrupt slot, shared with the BIOS ISR.
2. `CHKPIRDY` currently scans the **ESC key on every byte** (`out ($AA),a` /
   `in a,($A9)` — the PPI keyboard row-select register). Doing that 60×/second
   from inside an ISR corrupts the BIOS keyboard scan. The new driver cannot
   use the existing primitives, and hardware /WAIT is what lets it stop needing
   them.

### What this change does NOT fix — read before starting

The Z80's 92 µs/byte is **not currently the dominant cost**. The Pi-side
bit-banged SPI in `msxpi-server.py` (`SPI_ByteTransfer`) is a Python loop with a
`time.sleep(0.00001)` per clock tick and a `while GPIO.input(SPI_CS): pass`
spin — realistically **200–600 µs per byte**.

So /WAIT alone yields perhaps **10–30 %**. Its full value is only realised once
the Pi-side SPI is rewritten in C or moved to the hardware SPI peripheral. The
two changes are complementary and the Pi-side one should be scheduled first or
in parallel. **Do not benchmark this change against the current Python
server and conclude it failed.**

---

## 2. Current design (baseline v1.3)

| Item | Value |
|---|---|
| Device | `EPM3064ALC44-10` (MAX3000A, **64 macrocells**, PLCC44) |
| I/O ports | `CTRLPORT1` = `$56`, `CTRLPORT2` = `$57`, `DATAPORT1` = `$5A` |
| `WAIT_n` | **PIN_37, routed, currently `'Z'` (never driven)** |
| Clocking | FSM clocked on `rising_edge(SPI_SCLK)` — SCLK is an **input from the Pi** |

Behaviour:
- Read `$56` → `"0000000" & SPI_RDY_s` (bit 0 = busy/ready)
- Read `$57` → `"0000" & MSXPIVer` (`$0D` today). Write to `$57` is **ignored**
- Read/write `$5A` → data byte; a write to `$56` or `$5A` starts an SPI transfer
- Write `$FF` to `$56` → asynchronous `RESET`
- `BUSDIR_n` asserted only for reads of `$56`/`$5A`

---

## 3. Functional requirements

**FR-1 — /WAIT assertion.** When the MSX performs an I/O read of `$5A` (or a
write to `$5A`/`$56` that starts a transfer) while the interface is not ready to
complete it, the CPLD shall drive `WAIT_n` low, and release it (return to `'Z'`)
as soon as the data is available / the transfer has been accepted.

**FR-2 — Tri-state when inactive.** `WAIT_n` shall be driven low only while
actively stalling, and be high-impedance at all other times. It must never be
driven high — `/WAIT` is an open-collector-style shared bus signal.

**FR-3 — Mode bit, default OFF.** /WAIT assertion shall be **disabled at
power-up** and enabled only by an explicit host action (see FR-4). In the
disabled state the device shall be **bit-for-bit behaviourally identical to
v1.3**.

**FR-4 — Enable/disable interface.** A write to `CTRLPORT2` (`$57`) shall set
the mode register:
- `D = $01` → /WAIT mode ON
- `D = $00` → /WAIT mode OFF
- other values → reserved, treat as no-op

Port `$57` is currently write-ignored by the CPLD and **no existing software
writes to it** (verified across the whole `software/` tree — every reference is
an `IN`/read for version detection). This makes it the safe choice.

**FR-5 — Reset clears the mode.** The existing `RESET` condition (write `$FF` to
`$56`) shall clear the mode register to OFF. This is deliberate: it gives any
legacy program a way to restore known-good behaviour, and gives the new driver a
fail-safe. The driver is expected to re-enable after each reset.

**FR-6 — Version bump.** `MSXPIVer` shall change from `"1101"` to `"1110"`, so
software can feature-detect /WAIT support by reading `$57`.

---

## 4. Backward-compatibility requirements — MANDATORY

Existing binaries in the field must keep working with no recompilation:
the ROM BIOS (`msxpibios.rom`), the MSX-DOS driver (`msxpidos.rom`), the Nextor
driver, and all `.COM` tools.

**BC-1 — Default-off is absolute.** With the mode register OFF the device must
behave exactly as v1.3: same port decode, same `SPI_RDY_s` semantics, same
reset, same `BUSDIR_n`, `WAIT_n` never driven.

**BC-2 — `$57` must stay readable and below `$FE`.** `msxpi_bios.asm:97` reads
`$57` and compares against `$FE` to distinguish real hardware from openMSX
(which returns `$FE`). The new value `"1110"` reads as `$0E` — compliant. Never
let `$57` return `$FE` or `$FF`.

**BC-3 — `CTRLPORT1` bit 0 semantics unchanged.** Legacy software polls it. It
must keep meaning the same thing in both modes, so a program that polls *and*
has /WAIT enabled simply finds the flag already settled.

**BC-4 — Reset behaviour unchanged.** Write `$FF` to `$56` must continue to
reset the SPI FSM and clear the data buffer, in both modes.

**BC-5 — No new pins, no PCB change.** `WAIT_n` is already on PIN_37 and routed.
The change must fit the existing PCB v1.1/v1.2 hardware.

---

## 5. Safety requirements — the critical risk

**There is no free-running clock on this CPLD.** The only clock is `SPI_SCLK`,
an input driven by the Pi. If the CPLD asserts `WAIT_n` and the Pi then stops
clocking — crash, process kill, SD-card stall, `Ctrl-C` on the server — there is
**no clock edge left to time out on, and the MSX hangs permanently** with no
recovery short of a power cycle.

This is the single most important thing to get right.

**SR-1 — Bounded assertion.** `WAIT_n` shall be released after a bounded number
of `SPI_SCLK` edges (suggest 8–16, i.e. one byte period) regardless of Pi state.
On timeout, release `/WAIT` and let the read return whatever is in the buffer;
the software layer's existing checksum/retry logic will catch the bad byte.

**SR-2 — Assert only during a Pi-active window.** Only assert `/WAIT` when a
transfer has actually been started and `SPI_CS` is active, i.e. when the Pi is
committed to clocking. Never assert while merely idle-waiting for the Pi to
become ready — that is the unbounded case.

**SR-3 — Maximum stall duration.** Total `/WAIT` assertion for any single I/O
cycle must stay under **~20 µs**. Longer stalls disturb VDP access timing and
interrupt latency. Note this interacts with §1: if the Pi needs 200–600 µs per
byte, /WAIT **cannot** cover the whole wait, which is another reason the
Pi-side SPI speed-up is a prerequisite for the full benefit.

**SR-4 — Independent escape hatch.** Provide at least one recovery path that
does not depend on the Pi: the FR-5 reset, and ideally a hardware option
(depopulated resistor or jumper on the PIN_37 net) so a bricked bus can be
recovered on the bench.

**SR-5 — Z80 /WAIT timing.** `WAIT_n` must be valid before the falling edge of
T2 of the I/O machine cycle to be sampled. Note the Z80 already inserts one
automatic wait state in I/O cycles. Verify against the MSX bus timing spec, not
just simulation.

---

## 6. Resource constraints

**RC-1 — Must fit `EPM3064ALC44-10`: 64 macrocells.** This is the binding
constraint and the main reason this is a separate work stream. The v1.3 design
already uses a meaningful share. Adding an FSM, a mode register, and a timeout
counter may not fit. **Report actual pre- and post-change macrocell utilisation
from the Quartus fitter as part of the deliverable.**

**RC-2 — If it does not fit**, options in order of preference:
1. Shrink the timeout counter (3 bits is enough for an 8-edge timeout)
2. Share/reuse the existing `bitcount` counter for timeout duty
3. Migrate to `EPM7128` (used in earlier revisions per the project history) —
   but this is a PCB/BOM change and needs your approval first

**RC-3 — Toolchain.** Quartus II (same version used for v1.3). Existing files:
`MSXPi.qpf`, `MSXPi.qsf`, `MSXPi.vhd`, `MSXPi_package.vhd`, plus the testbench
`tb_MSXPi.vhd` and `sim.sh` (GHDL).

---

## 7. Acceptance criteria

1. **Fitter**: compiles clean for `EPM3064ALC44-10`, 0 errors; macrocell usage
   reported.
2. **Simulation**: `tb_MSXPi.vhd` extended to cover — legacy mode is
   cycle-identical to v1.3; /WAIT asserts and releases correctly in WAIT mode;
   the SR-1 timeout fires when `SPI_SCLK` stops; reset clears the mode.
3. **Regression on real hardware**: with the mode register never written (i.e.
   every existing binary), the MSX boots and all current MSXPi software works
   unchanged — `pdir`, `ploadr`, MSX-DOS boot, Nextor driver.
4. **New path on real hardware**: a small test program enables WAIT mode, runs
   an `inir` burst read, and gets correct data; timing measured against the
   legacy polled loop.
5. **Recovery verified**: kill `msxpi-server.py` mid-transfer with WAIT mode
   enabled — the MSX must not hang.

---

## 8. Deliverables

- Updated `MSXPi.vhd` / `MSXPi_package.vhd`
- Updated `tb_MSXPi.vhd` with the new cases
- New `.pof`
- Fitter resource report (before/after)
- Short note documenting the `$57` mode register for the software side

---

## 9. Open questions for the implementer

1. Is 8 `SPI_SCLK` edges the right timeout, or should it be tied to the FSM
   state instead of an edge count?
2. `BUSDIR_n` is currently **not** asserted for reads of `$57`
   (`is_ctrl_or_data` excludes `CTRLPORT2`) — a latent bug on expanded slots.
   Worth fixing in the same pass?
3. `D_buff_msx <= D when (...)` infers a latch. Intentional, or should it become
   a proper registered capture while the design is being touched?

---

## 10. Context

Consumer of this change: MSXPi UNAPI networking (Ethernet UNAPI + InterNestor
Lite). Test machine: **Canon V-25 (MSX2)** with MegaFlashROM SCC+SD 512 KB
mapper. This CPLD work is a **prerequisite for good performance but not for
first function** — the UNAPI work proceeds in parallel against the legacy
polled transport.

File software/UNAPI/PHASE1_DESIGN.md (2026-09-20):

# MSXPi Ethernet UNAPI — Phase 1 Design

Branch: `unapi-ethernet` (off `MSXPiv1.6`)
Date: 2026-08-30
Baseline: CPLD v1.6 (`MSXPIVer "1110"`), BIOS v1.6, post-`498316e`

**Goal:** implement the 12-routine **Ethernet UNAPI** on MSXPi, and run
**InterNestor Lite** on top of it to supply the full 30-routine TCP/IP UNAPI —
so that stock UNAPI applications (telnet, HGET, SNTP, MSXHUB) work on a
Canon V-25 with an MSXPi.

---

## 1. Transport baseline — what v1.6 actually gives us

### 1.1 CPLD semantics (read from `MSXPi.vhd`, not assumed)

| Condition | Behaviour |
|---|---|
| `OUT ($57),$01` | `wait_mode` = 1 |
| `OUT ($57),$00`, or `OUT ($56),$FF` (reset) | `wait_mode` = 0 |
| `IN ($57)` | `$0E` mode off, **`$8E` mode on** (bit 7 = mode read-back) |
| `wait_mode=0` | identical to v1.3 — `WAIT_n` never driven |
| `wait_mode=1`, `IN ($5A)`, `SPI_RDY=1` | **starts a transfer AND stalls the Z80** until the byte completes |
| `wait_mode=1`, `IN ($5A)`, `SPI_RDY=0` | no transfer, no stall — returns the stale buffer |

`spi_en <= ... or (wait_mode='1' and readoper='1' and is_data='1' and SPI_RDY='1')`

The `SPI_RDY` gate is the safety property that makes this usable: with no Pi
present, a burst read degrades to reading stale bytes instead of hanging the bus.

### 1.2 The fast path exists and is unused

`grep` across the whole `software/` tree: **nothing writes `$57`, and there is
no `INIR`/`OTIR` anywhere.** The v1.6 speed-up (~80%) came from tightening
`CHKPIRDY`'s poll loop and the Pi-side `/dev/gpiomem` fast GPIO path — all in
**legacy mode**.

So the hardware `/WAIT` burst path has **no consumer yet**. This driver will be
the first, and it inherits the fast path with no legacy-compatibility burden.

### 1.3 Per-byte cost

| Path | Z80 cost/byte |
|---|---|
| `PIREADBYTE` (legacy, current) | ~240 T-states (~67 µs) — was ~330 T |
| `INIR` with hardware `/WAIT` | 21 T-states + however long the Pi stalls us |

**The Pi is still the dominant term and its current value is unmeasured.** The
profiler added in v1.6 (`MSXPI_PROFILE=1`) exists precisely to answer this.
See §6 — this number gates the MTU decision and nothing else in this document
depends on it.

### 1.4 Doc nit found while reading

`MSXPi.vhd` D_out process: one comment line says *"$0E disabled, $1E enabled"*,
the later block correctly says *"Reads $0E with the mode off, $8E with it on."*
The code (`wait_mode & '0' & "00" & MSXPIVer`) gives **$8E**. The `$1E` line is
stale. Harmless, but it will mislead whoever writes the detection code.

---

## 2. BLOCKING ISSUE — MSXPi is a single shared channel

**This is the one thing that must be decided before any code is written.**

InterNestor Lite runs from the **50/60 Hz timer interrupt hook** and calls
`ETH_IN_STATUS` (and often `ETH_GET_FRAME`) on *every* interrupt.

Meanwhile, on this setup MSXPi is also the **disk**: the boot disk and Drive A:
are served by `msxpi-server.py` over the same ports `$56`/`$57`/`$5A`.

So the moment INL is resident:

> A foreground MSX-DOS/Nextor disk read is part-way through a `SENDDATA` /
> `RECVDATA_ONEBLOCK` block transfer. The timer interrupt fires. Our ISR issues
> its own `IN ($5A)`. **Both streams desynchronise permanently.**

Verified: there is **no guard of any kind** in `msxpi_bios.asm` or
`msxpi-driver.mac` — no semaphore, no in-use flag, no `DI` around block
transfers. Nothing today needs one, because nothing else ever touched the port.

It gets worse in WAIT mode: our ISR would also flip `$57`, changing the transfer
semantics underneath a foreground routine that assumes legacy polling.

### 2.0.1 A second, independent failure: the per-byte device check

`PIREADBYTE` decides *what kind of device it is talking to* on *every byte*:

```
in   a,(CONTROL_PORT2)   ; $57
cp   $FE                 ; openMSX returns $FE
jr   c,PIREADBYTE_SUCC   ; below $FE -> physical MSXPi
```

While our driver holds wait mode on, `$57` reads `$8E`. Trace both devices:

| device | `$57`, wait mode on | stock code concludes | result |
|---|---|---|---|
| real MSXPi v1.6 | `$8E` | `$8E < $FE` -> physical | **correct** - same branch as `$0E` |
| openMSX | `$8E` | `$8E < $FE` -> physical | **wrong** - skips the "wait for state 2" loop |

So a leaked wait mode is harmless to legacy code on real hardware, because
`$0E` and `$8E` both select the same branch - but in emulation it makes stock
routines read stale bytes. That is the same class of bug as the `ETH_WAIT_DATA`
defect fixed in Phase 5b, where accepting `$56 = 0` from openMSX returned the
`$FF` "no data ready" filler as if it were real data.

Two consequences:

1. Wait mode being per-transaction is not just tidiness, it is load-bearing -
   and `ETH_END` must be on every exit path, including error paths.
2. It is a second, independent reason Option A matters: even with a correct
   driver, disk I/O running *during* one of our transactions would misdetect
   the device in emulation. The byte-stream desync above and this device
   misdetection are separate failures with the same root cause.

### 2.1 Options

**Option A — shared in-use flag (recommended).**
A single byte in a fixed RAM location. The existing block routines
(`SENDDATA`, `RECVDATA_ONEBLOCK`, `PerformHandshake`, `SendCommandToMSXPi`) set
it on entry and clear it on exit. Our ISR does a `DI`-protected
test-and-set; if the flag is already set it **returns "no frames available"
immediately and tries again on the next interrupt.**

- Cost: a small, surgical change to shared BIOS code, and a coordinated release
  (ROM and driver must ship together — see the existing rule that ROM and
  bitstream are flashed separately).
- Missing a poll for one or two 60 Hz ticks is harmless: TCP retransmits, and
  frames sit in the Pi's buffer meanwhile.
- Cheap, correct, and the ISR never blocks the foreground.

**Option B — ISR skips while any I/O is in flight**, detected by reading
`$56`/`SPI_RDY` state. Rejected: not atomic, and it cannot distinguish "Pi busy
with someone else's byte" from "Pi busy with mine".

**Option C — foreground `DI` around block transfers.** Rejected: a 512-byte
block with interrupts off is ~34 ms at the current rate, which would break the
50/60 Hz clock, key repeat, and INL's own timers.

**Option D — do not use MSXPi as the disk while networking.** Boot and run from
the MegaFlashROM SCC+SD instead, leaving MSXPi exclusively for the network. No
code change at all. Viable as a **first-milestone workaround**, and it makes the
early phases much simpler, but it is not a shippable end state.

### 2.2 Decision — AGREED 2026-08-30

**Build against Option D, ship Option A.** Phases 2–6 run with the disk on the
MegaFlashROM SCC+SD so no shared-channel work blocks the UNAPI development;
Option A (the shared in-use flag in the block routines, plus the `DI`-protected
test-and-set in the ISR) is added as a discrete task before release. The openMSX
harness must be able to model both configurations.

Consequences for the phases that follow:

- **Phase 2 harness** builds the openMSX config as `Canon_V-25` +
  `MegaFlashROM_SCC+_SD` (disk/mapper) + `MSXPi` (network only). Item O4 is
  therefore on the critical path for Phase 2, not a nice-to-have.
- **Phase 5a** still implements the re-entrancy flag and `DI`-guarded critical
  sections — those protect the driver against *itself* (a client-initiated
  `ETH_SEND_FRAME` interleaving with the ISR's `ETH_IN_STATUS`) and are needed
  regardless of Option D.
- **Option A becomes a Phase 8**, after hardware acceptance: touch `SENDDATA`,
  `RECVDATA_ONEBLOCK`, `PerformHandshake` and `SendCommandToMSXPi` to set/clear
  the flag, then ship ROM and driver together as one coordinated release.
- Until Phase 8 lands, **running the disk over MSXPi while INL is resident is
  unsupported** and must be called out in the installer and the docs.

---

## 3. Wire protocol

### 3.1 Two tiers

The existing block protocol (`READY`/`READY_ACK` handshake, 4-byte header,
checksum, status handshake) costs **13 overhead bytes per block**. That is fine
for a 1514-byte frame and absurd for a 1-byte "any frames?" poll that INL issues
60 times a second.

**Tier 1 — fast ops.** No handshake, no checksum. One command byte out, a fixed
short reply in. Used for `ETH_IN_STATUS` and all the trivial routines.

**Tier 2 — bulk ops.** Frame in/out. Uses the burst path (§3.3) with a checksum,
because a corrupted frame is worse than a slow one.

### 3.2 Fast-op envelope

```
MSX -> Pi : [OP:1] [ARG:1]
Pi  -> MSX: [RC:1] [B0:1] [B1:1] [B2:1] [B3:1]      ; fixed 5 bytes, always
```

Fixed-length replies mean no length negotiation and no framing ambiguity after
an aborted transfer. Opcodes live in a private range that cannot collide with
the existing ASCII command set (which is 9 printable bytes — see `CMDSIZE`), so
the server can dispatch on the first byte being non-printable.

`ETH_IN_STATUS` maps to exactly one fast op:

```
RC = 0 -> no frame            RC = 1 -> frame available
B0,B1  = frame length (LE)    B2,B3  = bytes 12-13 of the frame (ether-type)
```

which is precisely the register set Ethernet UNAPI's `ETH_IN_STATUS` must
return in `A`, `BC`, `HL`. One round trip, ~6 byte times.

### 3.3 Bulk-op envelope, and the RaSCSI trick

`ETH_GET_FRAME` returns the frame **prefixed by the status of the next one**:

```
MSX -> Pi : [OP_GET_FRAME] [MAXLEN_LO] [MAXLEN_HI]
Pi  -> MSX: [LEN_LO] [LEN_HI] [FLAGS] [ ...frame... ] [CHKSUM]
                                  ^ bit 0: another frame is already queued
```

This is lifted directly from PiSCSI's `SCSIDaynaPort::Read` (`[len:2][flags:4]`,
flag `0x10` = more data pending). It means INL's *next* `ETH_IN_STATUS` is
answerable from a value we already hold — no round trip at all. Given INL polls
every interrupt, this is the single highest-value optimisation in the design.

### 3.4 Burst mode — a Pi-side requirement

`WAIT_n` is gated on `SPI_RDY`, and `SPI_RDY` is the Pi's `RPI_READY` GPIO,
which `SPI_ByteTransfer()` currently raises **per byte** and drops again at the
end of each byte.

> During that inter-byte gap `SPI_RDY=0`, so an `INIR` read would **not** start
> a transfer, would **not** stall, and would silently return a stale byte.

Therefore: **the Pi must hold `RPI_READY` high for the duration of a burst.**
Phase 3 must add a burst-aware transfer function that raises RDY once, clocks N
bytes, then drops it. Without this, `INIR` cannot be used at all — this is a
hard dependency, not an optimisation.

---

## 4. Driver structure

### 4.1 RAM implementation, not ROM

`msxpibios.rom`'s page-1 half has ~1.1 KB free. The driver is ~2–3 KB. So it
ships as a **`.COM` installer** that allocates a mapper segment, copies the
driver in, hooks `EXTBIO`, and installs the RAM helper — the `unapi-ram.asm`
model from the UNAPI spec repo.

The mapper comes from the MegaFlashROM SCC+SD (512 KB) on real hardware and from
`Ram2Mb` in openMSX.

### 4.2 ISR-safe transport primitives (Phase 5a)

The driver must **not** call `CHKPIRDY`/`PIREADBYTE`/`PIWRITEBYTE`. Even after
the v1.6 tightening, `CHKPIRDY` still does `ld a,7 / out ($AA),a / in a,($A9)`
— it writes the **PPI keyboard row-select register** — and it is called twice
per byte. Doing that 60 times a second from inside the timer ISR corrupts the
BIOS keyboard scan, which is exactly what a telnet client depends on.

New primitives, private to the driver:

- **No keyboard access.** Ever.
- **Bounded.** A spin counter, not an infinite poll. On timeout: return
  "no frames"; never hang.
- **`DI`-guarded critical sections** around any multi-byte exchange.
- **Re-entrancy flag** so a client-initiated `ETH_SEND_FRAME` and the ISR's
  `ETH_IN_STATUS` cannot interleave.
- **Wait mode is set and cleared inside the critical section**, never left on
  across a return — so the foreground world always finds the device in legacy
  mode. (Also makes Option A in §2 cheaper.)

### 4.3 Buffers

Ethernet UNAPI forbids implementations from *requiring* page-1 (`$4000-$7FFF`)
buffers, and permits refusing them. Our driver lives in a mapper segment, so
this is satisfied naturally. `ETH_GET_FRAME` with `HL=0` must discard the frame
without copying — used by INL to drop frames it doesn't want.

---

## 5. Frame policy

**MTU clamp.** Set the Pi-side TAP interface MTU low (start at **576**) so TCP
negotiates a small MSS and typical frames stay short. Revisit once §6 is
measured. Ethernet UNAPI requires accepting sends of 16–1514 bytes; we honour
that, we just arrange for the network not to produce large ones.

**Filters.** `ETH_FILTERS` configured for **unicast + broadcast only**. No
promiscuous, no multicast. Broadcast noise is the main risk to a thin link;
PiSCSI's proxy-ARP / isolated-subnet modes (`os_integration/proxyarp`) are the
fallback if a busy LAN proves too chatty.

**Padding.** Pad short frames to **128 bytes**, not the spec's 64. PiSCSI found
several real drivers break below 128 (their issues #619, #1098) and accepted a
broken checksum to do it. We generate the CRC in software anyway (TAP hands up
frames without FCS — see `CTapDriver::Crc32`), so we can pad and checksum
correctly.

---

## 6. What must be measured before Phase 5

One number, from hardware, ~5 minutes:

```
MSXPI_PROFILE=1 python3 msxpi-server.py
```

then a transfer, and read the `[prof]` line: **µs/byte**, and the
`spinning on CS` share.

It decides:
- whether `/WAIT` stalls fit the ~20 µs SR-3 budget, or whether the Pi must get
  faster before burst mode is safe to enable;
- the MTU clamp value;
- whether a full frame fits inside one 60 Hz interrupt slot (~59,600 T-states).

Nothing in Phases 2–4 depends on it.

---

## 7. Decisions taken

| # | Decision |
|---|---|
| D1 | Ethernet UNAPI (12 routines) + InterNestor Lite, not a TCP/IP UNAPI offload |
| D2 | RAM implementation via `.COM` installer, not ROM-resident |
| D3 | Two-tier wire protocol: fixed-length fast ops, checksummed bulk ops |
| D4 | Next-frame status folded into the current frame read (PiSCSI pattern) |
| D5 | Driver gets private ISR-safe primitives; stock `CHKPIRDY` is off-limits |
| D6 | Wait mode enabled per-transaction, never left on |
| D7 | MTU clamped at 576 initially; unicast+broadcast filters only |

## 8. Open items

| # | Item | Owner |
|---|---|---|
| O1 | §2 shared-channel decision — RESOLVED: Option D now, Option A as Phase 8 | done |
| O2 | Profiler µs/byte measurement | you, 5 min |
| O3 | Canon V-25 cartridge-slot mapper routing check (V-8/V-9 only routed page 2) | you, 5 min |
| O4 | openMSX config with `MSXPi` **and** `MegaFlashROM_SCC+_SD` together | Phase 2 |
| O5 | Stale `$1E` comment in `MSXPi.vhd` | trivial |

---

## 9. Interrupts are disabled on return from every UNAPI call

Not a defect in this driver, in RAMHELPR, or in UNAPI - it is the MSX platform
contract, and it is worth writing down because it is invisible until it bites.

The RAM helper's inter-segment call reaches a segment-resident implementation
through the BIOS:

```
CALLRAM__1:
        call    GET_P1__1
        ld      a,iyl
        call    PUT_P1__1
        call    CALSLT          ; <-- BIOS $001C
        pop     af
        call    PUT_P1__1
        ret
```

`CALSLT` (like `RDSLT` and `WRSLT`) disables interrupts and does not re-enable
them. So **every call into a RAM-segment UNAPI implementation returns with
interrupts disabled**, on every MSX, for every implementation - Konamiman's
examples included. Re-enabling is the caller's job.

Observed as: ETHBENCH reported zero elapsed jiffies for thousands of
transactions that were demonstrably working, because JIFFY had stopped being
updated. A control delay loop in the same program, run moments earlier, read
~37 jiffies. Adding an `ei` after each call made the timings appear.

### Why it matters for InterNestor Lite

INL runs from the timer interrupt. A foreground client that leaves interrupts
off between UNAPI calls stops that interrupt firing, so:

1. INL never processes incoming frames,
2. so `TCP_RCV` never returns data,
3. so the client keeps polling,
4. so interrupts stay off.

A deadlock, presenting as "the network hangs", with neither component looking
broken. Stock clients avoid it by re-enabling interrupts, which is why they work
in the field - but it must be verified rather than assumed, with a real client,
early in Phase 6.

### What this driver does about it

Nothing, deliberately. It has no interrupt dependence: every spin is bounded,
there are no timers, and `ETH_LOCK` no longer uses `di` (see the note there for
why the obvious `ld a,i` idiom is worse than useless). It behaves identically
whether interrupts are on or off, so the only correct place to fix this is the
caller.

Our own test programs do re-enable interrupts around their loops - see
ETHBENCH's `RUN_PASS` - which is what a well-behaved foreground client has to
do anyway.

---

# The driver moves into the ROM (2026-08-31)

## Why

InterNestor Lite's RAM-segment path is a dead end. Four defects turned up on
real hardware in code no field implementation exercises: `_UN_RAMCALL` fetched
only when the segment IS `$FF`, the implementation name read through `CALL_MAP`
instead of `RD_MAP`, `INL S` reporting "not installed" while `UCOUNT` proves
TCP/IP registers, and `INL I` hanging outright. Two are patched in `inl/`; the
other two are not understood. Forcing our transport to the bounded polled path
with `ETHUNAPI P` changed nothing, so the transport was exonerated and the
fault is entirely in INL.

A ROM implementation reports **segment `$FF`**, which puts every stock client -
InterNestor Lite included - on the `CALSLT` path that ObsoNET and every other
field implementation use. No INL patches, no RAM helper dependency, and no
installer to run.

The `.COM` installer stays as the option for people who cannot reflash.

## Where it lives

`target/msxpibios.rom` is built from `ROM/src/MSX-DOS/msxpi-driver.mac`, **not**
from `ROM/src/BIOS/msxpibios.asm` - that trap has cost time before. The driver
is assembled separately by sjasm and `INCBIN`'d into the free tail at a fixed
`UNAPI_ORG`, with `ASSERT`s on both sides: MSXPi code must not reach
`UNAPI_ORG`, and the image must end below `8000H`. Growth in either direction
is a build error rather than a corrupt ROM.

Two assemblers, because neither can do the whole job: zmac builds the ROM, and
sjasm builds the driver - the same sources also produce the RAM variant, and
they are sjasm syntax throughout. The driver calls the kernel's `GETSLT` and
`GETWRK` by hardcoded address (the two assemblers cannot share a symbol table);
`msxpi-driver.mac` `ASSERT`s both against the real labels.

## Fitting it

The free tail was 1,100 bytes and the driver was 1,240. What closed the gap:

| | bytes |
|---|---|
| a dead `DS 128` in `msxpi_bios.asm` (`heap_top`, never referenced) | 128 |
| `ChoiceStr` - "1 - Choice A" etc., and `CHOICE` returns HL=0 | 47 |
| `DSKIORDMSG` - "DSKIO READ ERROR", never printed | 19 |
| `DOS_INI`/`DOS_DRV`/`DOS_FMT` - protocol strings never sent | 36 |
| `ETH_TX_BLOCK` - dead: every send goes through `ETH_TX_SUM` | 58 |
| `ETH_TX`'s mode branch - both arms were literally identical | 17 |
| `ETH_RX`'s two arms merged; they differ only in the middle step | 13 |
| `ETH_WAIT_DATA`'s two polled loops merged into one | 23 |

That is 341 bytes against a 158-byte shortfall, and the diagnostic routine 128
survived. 38 bytes are still free below `8000H`.

## State

The ROM cannot write to itself, so every mutable byte moved into the disk
driver work area - `MYSIZE` grew from 9 to 45 and `GETWRK` hands out the
pointer. Offsets 0..7 stay with the disk driver (`DSKIO_SECTINFO` 0..4,
`MSXPI_GETSTASH` 5..7); ours start at 8. `asm-common/include/unapi_wrk.inc`
holds the layout and is included by **both** assemblers.

**Both builds use it**, reached through `IX`. The RAM build could have kept
absolute addresses, but then `ethtrans.asm` and `ethops.asm` would have needed
two versions of every state access, and they would have drifted. MSX-UNAPI 2.3
makes this legal: `IX`/`IY` "must not be used for input parameters" and are
corrupted on return, precisely so inter-slot and inter-segment calls can use
them. `UNAPI_ENTRY` sets `IX` once and every routine reads through it.

## Initialisation

From `INIENV`, not `INIHRD`. By the time the kernel calls `INIENV` it has
allocated the `MYSIZE` work area and stored it in `SLTWRK` (so `GETWRK` works)
and initialised the EXTBIO hook - either in this diskrom or in whichever one
started the disk system first, so `HOKVLD` needs no checking. The hook becomes
`RST 30h` + slot + address + `RET`, exactly five bytes, and the hook it
displaces is kept in the work area. Installing twice would chain the hook to
itself, so `INIENV` recognises its own handler and returns.

## The transport is probed lazily, and that matters

The `.COM` installer probes at install time. The ROM **cannot**: `INIENV` runs
during disk-system initialisation, when on real hardware the Pi is usually
still booting. A probe there would fail and pin the driver to the slow polled
backend for the rest of the session. So `INIENV` writes `MODE_UNKNOWN` and the
first UNAPI call runs `ETH_DETECT` - by which time the machine has booted off
the Pi and the link is known good.

That first transaction is still slower than every later one, because the other
end builds its Ethernet shuttle lazily when the first opcode arrives. With the
fixed 17 ms per-byte budget it **timed out**, and then the reply landed in a
queue nobody was reading: every later transaction read the previous one's
answer. Not a lost call - permanent desync. It showed up as ETHTEST printing
the probe's own `ETH` signature as the MAC address:

```
MAC:   455448010002      <- 'E' 'T' 'H' 01, then the real reply starting
Net:   00
```

Caught in emulation only because a cold `__pycache__` made the server's first
`import msxpi_eth` slow enough; with the bytecode cached it passed. The fix is
`(ix+o_ETH_TMO)`, the per-byte budget in units of 256 iterations: the work area
starts zeroed, which the wait loops read as the **longest** budget (~0.5 s), and
`ETH_DETECT` drops it to the normal value once the link has answered once.

The underlying hazard is older and still there: a reply that arrives after we
have given up on it poisons the next transaction, and `ETH_RESYNC` cannot
retrieve bytes already buffered on the other side. `ETH_MAXFAIL` limits the
damage; a bounded drain in `ETH_RESYNC` would be the real fix if this recurs.

## What the tests now prove

`unapi_discovery` runs `ETHTEST` from a **cold boot with nothing installed** -
no `RAMHELPR`, no `ETHUNAPI` - and gets `Found: 01`, `Seg: FF`, the real MAC
over the wire and `Net: 01`. `ETHTEST` and `ETHBENCH` both learned the `CALSLT`
path and now treat the RAM helper as optional, needed only for a mapped
segment.

`unapi_install` pins the opposite: with the ROM driver present, `ETHUNAPI.COM`
must refuse, because installing anyway would register a second implementation
of the same API.

## What INL does now

`INL I` **completes** on the ROM path:

```
Searching Ethernet UNAPI implementation... OK
Found MSXPi Ethernet UNAPI v0.1 at slot 1
InterNestor Lite has been installed. Have fun! (^^)/
```

Against the RAM implementation it hung right after the "Found" line. That was
defect (4), and going ROM fixed it - which is the whole justification for this
change. `wsl_inl` now asserts it rather than merely running it.

Defect (3) survives, and is now more interesting than it was. `INL S` still
reports "InterNestor Lite is not installed" immediately after a successful
`INL I`. Two explanations are ruled out:

* **Not the RAM-segment path.** It behaves identically with the driver in ROM.
* **Not the separate mapper card.** The standing theory was that INL's
  residency check compares against `RAMAD1`, and the harness adds `ram2mb` to a
  Canon V-25, putting the mapper in a different slot from page-1 RAM. Tested
  with `MACHINE=Philips_NMS_8245 HW=msxpi128` - 128K in the main slot, no
  `ram2mb`, mapper and page-1 RAM in the same slot - and `INL S` still says not
  installed. The theory is dead; do not spend time on it again.

`UCOUNT` proves the TCP/IP UNAPI does register, so INL itself is working and it
is specifically INL's own status command that is confused. Whatever marker
`INL S` looks for is not being left by `INL I` in this environment. It is not
blocking: nothing depends on `INL S` except a human wanting reassurance.

Still unproven: everything on real hardware, and anything that carries a real
frame. Nothing network-facing has yet moved a single one - TapLink's reader
thread, the CRC generation, frame padding and the queue policy are all still
unexecuted.

---

# Validated on real hardware (2026-09-04)

Canon V-25, MegaFlashROM SCC+SD in slot 1 running Nextor, MSXPi in slot 2,
`msxpibios.rom` sha1 `3616e00a`.

| test | result |
|---|---|
| `ETHTEST` from a cold boot, nothing installed | `Found: 01`, `Seg: FF`, `Rst: ok`, `Mode: 01`, real MAC, `Net: 01`, `P57: 0E` |
| `INL I` | installs; `UCOUNT` reports ETHERNET `01` and TCP/IP `01` |
| `ETHBENCH` | `ok=0800` on **every** line, `W-3by` included |
| `ETHTEST` again, with INL resident | correct MAC and `Net: 01` |
| `TESTRAM` | 512KB mapper passes |

Three of those are firsts.

**`W-3by` is no longer intermittent.** That 3-byte `/WAIT` transaction used to
return `0800` in one run out of three, and it is the shape of `ETH_IN_STATUS`,
which InterNestor Lite calls sixty times a second - the most exposed case in
the whole design. It is now clean. The likely reasons are that detection proves
`/WAIT` with a real probe transaction before selecting it, and that the Pi
holds `RPI_READY` across the inter-byte gap.

**Re-entrancy holds against a real interrupt-driven client.** `ETHTEST` run
while INL is resident still gets correct answers, so foreground UNAPI calls and
INL's timer-ISR polling of `ETH_IN_STATUS` coexist. That is what `ETH_LOCK` and
the ISR-safe transport core were written for, and until now it had never been
exercised by an actual ISR consumer - not on hardware, not in emulation.

## What the `INL I` hang actually was

`INL.CFG` line endings. LF only, where MSX text files need CRLF.

Not the driver, not the transport, and not the RAM-vs-ROM segment path - all
three had been suspected and all three were wrong. After installing, INL feeds
`INL.CFG` back through its own command parser one line at a time; with no CR it
never finds a line boundary, reports *"Cannot execute this command from a
configuration file"*, and then loops printing its banner. On DOS 1 that shows
as a visible loop; on Nextor it presents as a hang.

Three-way A/B in emulation settles it: LF-only stops at "Found ... at slot N";
no file at all installs cleanly; CRLF installs **and applies the static IP**.

`UNAPI/build.sh` now converts the file at copy time rather than trusting the
copy in the repo, because git's line-ending handling can rewrite it on
checkout. `wsl_inl` asserts both that the install completed and that every
config line was accepted - "has been installed" alone would not catch a config
file that was silently skipped.

## Still unproven

Anything that carries a real frame. The MAC coming back as `024D53585069` is
`msxpi_eth`'s built-in default, which means the Pi is running `MockLink`: it
answers every opcode perfectly and moves no traffic, so the whole suite passes
while nothing is connected. `TapLink`'s reader thread, the CRC generation,
frame padding and the queue policy remain unexecuted.

---

# It works (2026-09-05)

```
64 bytes from 192.168.99.2: icmp_seq=1 ttl=64 time=59.6 ms
64 bytes from 192.168.99.2: icmp_seq=2 ttl=64 time=40.2 ms
```

Canon V-25, MegaFlashROM SCC+SD in slot 1 running Nextor, MSXPi in slot 2,
`msxpibios.rom` sha1 `cba6355e`, **stock** InterNestor Lite. ARP resolved by
INL itself, ICMP echo answered.

## The last bug was ours, and it was one instruction

Both of InterNestor Lite's send sites do this:

```asm
	ld	d,1
	ethnet	ETH_SEND_FRAME
```

`D=1` is asynchronous mode. `FN_SEND_FRAME` opened by rejecting it:

```asm
            ld      a,d
            or      a
            jr      z,.sync
            ld      a,5                     ; async not supported
            ret
```

So every reply INL ever composed was refused at the final instruction. It
received frames correctly, parsed them correctly, decided to reply, and we said
no — which is exactly why every layer underneath looked perfect while nothing
came back.

The fix sends synchronously whatever `D` says and returns 0. That is safe
rather than a fudge: asynchronous mode only guarantees that transmission has
*started*, so completing it first is a stronger guarantee than the caller asked
for, and a caller polling `ETH_OUT_STATUS` gets `2`, "finished successfully".

## Two things hid it, both self-inflicted

**`ETH_OUT_STATUS` was lying by omission.** The async and bad-length paths
return early without recording anything in `o_ETH_LASTSEND`, so routine 10
reported `0` — "nothing sent since reset" — when the truth was "an attempt was
refused and not recorded". That reading sent the investigation into INL's
source for several cycles. A diagnostic that cannot distinguish "never called"
from "called and rejected" is worse than no diagnostic.

**`software/build` had `buildBIOS="no"`**, so the entire ROM block was skipped
and `ROM/src/MSX-DOS/ethrom.bin` sat at a four-day-old build while driver
changes appeared to be deployed. Any driver fix has to reach the ROM, and with
that flag off it silently never does.

## And one long-standing mystery closed

`INL S` reporting "not installed" was **caused by the RAM-implementation
patch**, not by this driver or the machine. Stock INL - built by reversing
`inl/inl-2.3-ram-implementation.patch`, vendored as `bin/INLSTOCK.COM` -
reports "installed and ACTIVE". Two explanations had already been ruled out for
that defect; the real one was self-inflicted, which is the point of running
stock software when the whole design goal was that stock software should work.

## What is still unproven

DNS, TCP and telnet. And NAT: the uplink-detection fix is in the repo but not
deployed to the Pi, so nothing routes off-subnet yet. On-link traffic works.

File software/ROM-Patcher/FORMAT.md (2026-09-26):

# MSXPi ROM patch package, version 1

This is the handoff contract between game analysis and the patching application.
The producer supplies a directory containing `profile.json` and referenced
binary assets. Assembly sources and evidence/tests should accompany it.
JSON numbers are decimal integers; binary strings are hexadecimal without `0x`.
Offsets always refer to **file bytes**, never CPU addresses, unless explicitly
identified as runtime symbols. Duplicate JSON keys are invalid.

## Processing order

1. Validate format/version, input size/hash, and asset hashes.
2. Allocate `output.size` bytes initialized to `output.fill`.
3. Copy the non-overlapping `layout` ranges into the output.
4. Apply non-overlapping `patches`, verifying every expected byte.
5. Merge music overrides into defaults, validate IDs/names/modes/capacity,
   and populate the declared zero-filled music configuration regions.
6. Write a new ROM and deterministic build manifest. Never modify the input.

File size limit: 16 MiB. Asset paths resolve inside the profile directory;
paths escaping it are rejected, including symlinks resolving outside it.
No shell commands, Python code, assembler invocation, expression evaluation,
or arbitrary callbacks are part of the consumer format.

## Required fields

| Field | Meaning |
|---|---|
| `format` | Exact string `msxpi-rom-patch` |
| `version` | Integer `1`; incompatible future versions must be rejected |
| `id` | Nonempty, versioned package identity |
| `source.size`, `source.sha256` | Exact original ROM size and SHA-256 |
| `output.size`, `output.fill`, `output.mapper` | Output allocation, fill byte, mapper description |
| `requirements` | Human-readable runtime prerequisites |
| `assets` | Object of asset names mapped to `{file, sha256}` |
| `layout` | Array of `{source, offset, size, destination}` copies |
| `patches` | Array of `{offset, expected, replace, reason}` operations |
| `music` | Configuration ABI and output offsets, described below |
| `sounds` | Game IDs keyed by stable strings, mapped to `{raw_ids, description}` |
| `defaults` | Complete default music configuration |
| `symbols` | Optional diagnostic object: label to runtime CPU address |

`layout.source` is `input` or an asset name. The name `input` is reserved.
Source/destination ranges must fit their buffers. Unassigned output areas keep
the fill byte. Patches use equal, nonempty byte lengths, so ROM layout cannot
shift accidentally. Put insertions and bank rearrangements in the layout.

Original ROM version differences are expressed as separate profiles in v1.
Do not use fuzzy matching or silently apply a nearby game's patch locations.

## Music ABI `msxpi-music-v1`

`music` has these fields:

| Field | Region written by the patcher |
|---|---|
| `abi` | Exact string `msxpi-music-v1` |
| `map_offset` | 256 bytes: raw game sound ID to track index |
| `modes_offset` | 256 bytes: index 0 unused; 0 = play, 1 = loop |
| `options_offset` | Two bytes: exit enabled (0/1), silence grace frames (0..255) |
| `names_offset` | Packed ASCII filename list |
| `names_capacity` | Reserved list size; unused bytes zero-filled |
| `names_encoding` | Optional `ascii` (default) or `escape-32` |

These regions must be disjoint, zero-filled after layout/patch application,
and must not overlap byte patches. They can lie in a payload asset. The profile
producer ensures the bootstrap copies them to the RAM addresses expected by
the payload; the generic patcher does not infer runtime memory mapping.

Track indices are one-based, at most 255. Zero means retain original audio.
The Nth filename is track N. Each filename ends in NUL and an extra NUL marks
the end of the list. With no tracks, the list is exactly two NULs before padding.
Filenames cannot be empty, exceed 127 ASCII bytes, contain nonprintable bytes,
or have surrounding whitespace.

`escape-32` stores filename byte `32` hex (ASCII `2`) as `02` hex. The producer's
adapter must restore it before using the list. NUL/double-NUL delimiters do not
change. This prevents the current server's bank-switch scanner from rewriting
filenames such as `x2ab.mp3` as Z80 instructions. It is unambiguous because byte
`02` is forbidden in input filenames. ID/mode tables are not encoded; profiles
with many track indices must separately validate their scanner compatibility.
The supplied Goonies profile has at most 30 indices, none equal to opcode `32`.

`sounds` keys represent the analysis task's stable identifiers; they need not
be numeric. Each record lists unique `raw_ids` in 0..255. An adapter for a game
with wider or structured identifiers must normalize them to this byte-sized
event space. Every raw ID must belong to at most one record.

`defaults` and user configuration contain:

```json
{
  "tracks": {"theme": {"filename": "theme.mp3", "mode": "loop"}},
  "sounds": {"stage": "theme", "victory": null},
  "exit_enabled": true,
  "gap_frames": 120
}
```

The keys of the effective `sounds` object must exactly match the profile's
sound definitions. A value names a defined track or is `null` for native audio.
User files may be partial: tracks and sound mappings merge by key, while exit
and grace settings replace their defaults. A track entry replaces that entire
entry and must include both `filename` and `mode`.

Indices are allocated in profile sound-definition order, deduplicating equal
`(filename, mode)` pairs. Unreferenced tracks are validated but not stored.
Different modes for the same file are distinct tracks. Reordering JSON object
members may change binary track indices, but not the configured behavior.

## Supplied Z80 runtime calling contract

`profiles/goonies/src/runtime.asm` is the reusable single-player implementation.
`game.asm` supplies its adapter and executes `service` with interrupts disabled
from a safe foreground point, not from an interrupt handler. The adapter owns
register preservation and native-game state compatibility at its hooks.

- `desired_music`: return A = track index, or zero for silence/native audio.
- `music_id`: map raw ID in A through the 256-byte table; A = result, carry set
  for a nonzero result. Preserves HL. This runtime uses page-aligned tables.
- `service`: manage single current/desired track, one owned decimal PID, the
  silence grace, and bounded command/reply transport. May clobber main registers;
  the supplied transport can use shadow registers, hence foreground DI context.
- `stop_music`: stop only the saved PID and consume the reply. The caller must
  ensure the PID is nonempty. A valid reply is `Ok` with optional line ending.
- `link_failed`: terminal native-audio fallback flag for this session. Do not
  mute native channels or attempt routine service commands when set.
- `pid`: 11-byte buffer, at most 10 decimal digits plus NUL. Muting is allowed
  only after successful parsing and when `link_failed` is zero.

The adapter must leave original sequencing intact for fallback. The Goonies
adapter hooks channel-volume output to mute mapped melodies only after external
playback succeeds, retaining sound effects and original state progression.
It examines channel IDs in A/B/C order; this priority is game-specific.

Exit is also adapter-specific. Goonies polls Ctrl+Shift+F5, stops its PID,
clears the original lower-bank and bootstrap `AB` headers in mapper RAM,
removes the timer hook, and jumps to BIOS reset. This is not a generic reset
algorithm for every mapper or cartridge.

## Analysis-package acceptance checklist

- Original hash and expected bytes verified against the actual input revision.
- Mapper conversion, bank visibility, RAM/stack reservations, and hook side
  effects reviewed against the game and supported loader.
- Sound IDs, aliases, effects, silence, and event priority documented with
  evidence. Unidentified IDs must not be given invented event names.
- Playback, sustained silence, transitions, failure fallback, effects, and exit
  checked in an emulator at normal speed; live MSXPi transport checked separately.
- No original ROM or MP3 included in the distributable package.
- Asset built from accompanying sources; profile hashes updated with it.

The build manifest records input/output hashes, profile identity/fingerprint,
effective music settings, assigned track indices, symbols, and requirements.
It is written to `builds/<output name>.json` beside the profile, never next to
the ROM. It contains no timestamp, so identical input/profile/configuration gives
identical ROM bytes and manifest content.

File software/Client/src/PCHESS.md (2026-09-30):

# PChess

PChess uses SCREEN 5 and Fusion-C on any MSX2 (64 KB VRAM is enough). Pieces are
graphical silhouettes. By default the MSXPi server validates all moves using
the optional `chess` Python package. With `LINK: TCPIP` (below) PChess runs
without the MSXPi server on any TCP/IP UNAPI network card and checks the
rules itself.

Pieces and glyphs are cached in off-screen VRAM at startup. Refresh uses
Fusion-C's assembly HMMM VDP blitter; only changed squares and characters
are copied. The board/panel is not cleared during moves or network polls.
A normal-speed Panasonic OpenMSX cursor test measured completion within
34 emulated milliseconds (VRAM polling at 1 ms intervals).

Install `Server/Python/src/requirements-pchess.txt` with the server's Python.
Rules include check, mate, stalemate, castling, en passant and underpromotion.
Claimable draws are automatically accepted.

The AI opponent (`2`) is Stockfish when it is installed on the server
(`sudo apt install stockfish`; the setup script does this). msxpi.ini:

```text
var PCHESSENGINE=        # Stockfish path; empty = find it (PATH, /usr/games)
var PCHESSELO=800        # approximate playing strength
var PCHESSMOVETIME=1     # seconds of thinking per move
```

Stockfish's rating limit starts at about 1320; below that PChess uses its
weakest skill level with a shallow search, so low ratings such as the 800
default are approximate. Without Stockfish, or if it fails, a much weaker
built-in two-ply search plays. Stockfish and python-chess are GPL-3.0; they
run as separate programs on the server and the MSX executable links neither.

Build from `software` with:

```bat
make.bat pchess
```

This produces `target\pchess.com` and copies it to the configured FloppyA
directory. Use Panasonic_FS-A1WSX, MSXPi, ram4mb, and mount
`C:/Users/roniv/Dev/MSX/MSXPi/FloppyA` using `diska`. Inside MSX-DOS, switch
to **C:**, then run `PCHESS`.

Files A-H are labelled above the board and ranks 1-8 to its left; they
follow the board when it is rotated. The PSG beeps twice when the opponent
offers a draw, plays a rising tune when you win and a falling one when you
lose (in local two-player any win plays the rising tune).

Controls:

- `1`: local two-player; `2`: play white against the server AI.
- `4 ONLINE`: connect to IRC and join #msxpi; `5`: announce availability.
- `6`, nickname, Return: privately invite an opponent; `7`: accept an invite.
- `8 PLAYERS`: list players who seeked or invited you in the last ten
  minutes (up to seven, newest first); Up/Down and Return invite one.
- Once matched (lobby, room or AI), the panel shows your colour (`AS
  WHITE`/`AS BLACK`; PChess1: `YOU ARE WHITE` and `VS <nick>`), and the
  lobby/room status reads e.g. `YOU ARE BLACK - chp1 MOVES`. Black sees
  the board rotated, with its own pieces at the bottom; the cursor moves as
  shown on screen and typed moves (`e7e5`) are unchanged. `ROTATE BOARD`
  in the ESC menu turns the board over at any time, in any mode.
- While online (after `3` ROOM or `4` ONLINE), keys `1`-`4` first ask
  `LEAVE ONLINE GAME? Y/N`: any key but `Y` keeps the current game.
- Arrows or joystick port 1 move the cursor. Space, Return or joystick A
  selects source/destination. Cursor promotions choose a queen.
  Direction events are rate-limited to one per eight jiffies (133–160 ms)
  to suppress rapid repeats; the first direction is immediate.
- Type UCI (`e2e4`, `a7a8n`) or SAN (`Nf3`, `O-O`) and press Return.
- Backspace edits notation.
- Escape opens the menu: Up/Down pick a row. On `AI LEVEL`, Left/Right
  choose 1-8 and Return saves it (`pchess level N` sets PCHESSELO in
  msxpi.ini: 600, 800, 1000, 1350, 1600, 1900, 2200, 2500). `ROOMS`
  (Left/Right, Return saves `PCHESSROOMS`) picks where `3 ROOM` meets:
  `RELAY` (default) or `IRC`. `LINK` (Left/Right, Return applies) switches
  between `MSXPI` (default at every start) and `TCPIP`. `EXIT` returns to
  DOS; Escape resumes the game.
- `OFFER DRAW` (ESC menu): in local play the game is drawn at once. The AI
  accepts unless it is ahead by more than half a pawn (Stockfish's
  evaluation, or material without Stockfish), otherwise the status reads
  `AI DECLINES THE DRAW`. Online (room or lobby) you offer on your move;
  the opponent sees `OPPONENT OFFERS DRAW - ESC MENU` and accepts with
  `OFFER DRAW`, or declines by moving. `RESIGN` asks `RESIGN? Y/N`; in
  local play the side to move resigns. Both ask Y/N first.

IRC settings and the public-discovery/private-game protocol are documented
in `documents/PCHESS-IRC.md`. Both servers must use the same IRC network.
Games are in memory; reconnect/resume, clocks and Lichess integration are
not implemented. An IRC connection failure is displayed on the status line.

ROOM mode (`3`) by default uses a small HTTP relay built into the MSXPi server. Choosing
`3` starts it on `PCHESSLISTEN:PCHESSPORT` (msxpi.ini, default `0.0.0.0:5080`,
reachable from the LAN); choosing any other mode stops it. `PCHESSRELAY`
selects the relay both players share: leave it empty on the hosting MSXPi,
and set it to `http://HOST_IP:5080` on the other one. Both players enter the
same room name; the first to join is white. The relay is plain HTTP for
trusted networks. `python msxpi_pchess.py --listen 0.0.0.0 --port 5080`
still runs a standalone relay on a third machine.

With `ROOMS: IRC` (msxpi.ini `var PCHESSROOMS=irc`) a room is instead the IRC
channel `#pchess-<room>` on the lobby's network (IRC settings as for `4`), so
MSXPi players and TCP/IP players can share it. The player whose nick sorts
first plays white; the invitation is accepted automatically. A third player
sees `ROOM BUSY - GAME IN PROGRESS`. Entering the same room again after a game
starts a rematch.

## TCP/IP link (no MSXPi server)

`LINK: TCPIP` in the ESC menu sends everything over a TCP/IP UNAPI
implementation instead of the MSXPi server: InterNestor Lite over the MSXPi
Ethernet driver, or a network cartridge (GR8NET, ObsoNET, DenYoNet...). The
choice lasts until PChess exits; every start is `LINK: MSXPI`. Install the
TCP/IP stack first:

```text
MSX-DOS 1 with a memory mapper:   MSR I      then  INL I
Nextor / MSX-DOS 2:               RAMHELPR I then  INL I
```

If none is found the status line reads `NO TCP/IP UNAPI - RUN INL I`. On this
link:

- `1 LOCAL` is played on the MSX; its rules (`pchess_rules.c`) match
  python-chess, including threefold repetition and the fifty-move rule.
- `3 ROOM` always uses IRC rooms (`#pchess-<room>`), and `4 ONLINE` joins
  `#msxpi`: the same protocol as an MSXPi server, so both kinds of player
  meet. Plain TCP only (no TLS), so the IRC server must accept port 6667.
- `2 AI` needs the MSXPi server: `AI NEEDS MSXPI - ESC MENU LINK`.

`PCHESS.INI` in the current directory sets the IRC server and nick:

```text
IRCADDR=irc.libera.chat
IRCPORT=6667
IRCNICK=myname
```

Without it the defaults are those shown, and a random `pchXXXX` nick.
Moves carry the protocol's sha256 position digest, computed in Z80 assembly
(about 0.4 s a move); the connection is polled once a second.

Tests: `test_pchess.py` and `test_pchess_irc.py` under `Server/Python/tests`.
`Client/tests/pchess_rules_test.py` builds `pchess_rules.c` and the C
SHA-256 with gcc in WSL and plays random games against python-chess.
`Client/tests/pchess_tcpip_openmsx.py` runs PCHESS.COM on TCP/IP in openMSX
(`HW=msxpi`: MSX-DOS 1, `MSR I`, `INL I`; `HW=nextor`: MegaFlashROM SCC+ SD,
`RAMHELPR I`, `INL I`) through the Windows TAP, and plays LOCAL, ROOM and
ONLINE games against the MSXPi server's own IRC client.
Run `pchess_dual.py --irc` with Windows Python for two OpenMSX instances,
two MSXPi servers on ports 5041/5042 and a local IRC fixture on 5081.
The harness switches each DOS session to C:, sends e4/e5 and checks both
boards. Test logs/screenshots are in a fresh `work/pchess-dual-*` directory.
Only processes created by that harness are terminated during cleanup.

## PChess1 (MSX1)

`pchess1.c` is the MSX1 (TMS9918, 16 KB VRAM) version with the same server
protocol, modes and controls, including the ESC menu's ROOMS and LINK rows:
the TCP/IP link code (`pchess_rules.c`, `pchess_sha.c`, `pchess_tcp.c`) is
shared with pchess.c. On an MSX1 the TCP/IP stack needs a memory mapper
(`MSR I`, then `INL I`). It uses SCREEN 2 as a tile screen: the same
256 characters are loaded into all three pattern/colour banks, so refreshes
only write name-table bytes. Squares are 16x16 (the pchess pieces scaled to
two thirds) and text uses the BIOS 8x8 font, copied from SCREEN 1 at start.
Because SCREEN 2 allows two colours per 8 pixels, pieces have no outline,
and the cursor (red) and selection (green) are hardware sprites.

Build with `make.bat pchess1`; it produces `target\pchess1.com`.

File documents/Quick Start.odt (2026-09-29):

MSXPi Quick Start Guide

Version 1.6

Real hardware (MSXPi interface + Raspberry Pi) and openMSX. Everything else is in the Users and Developers Guide.

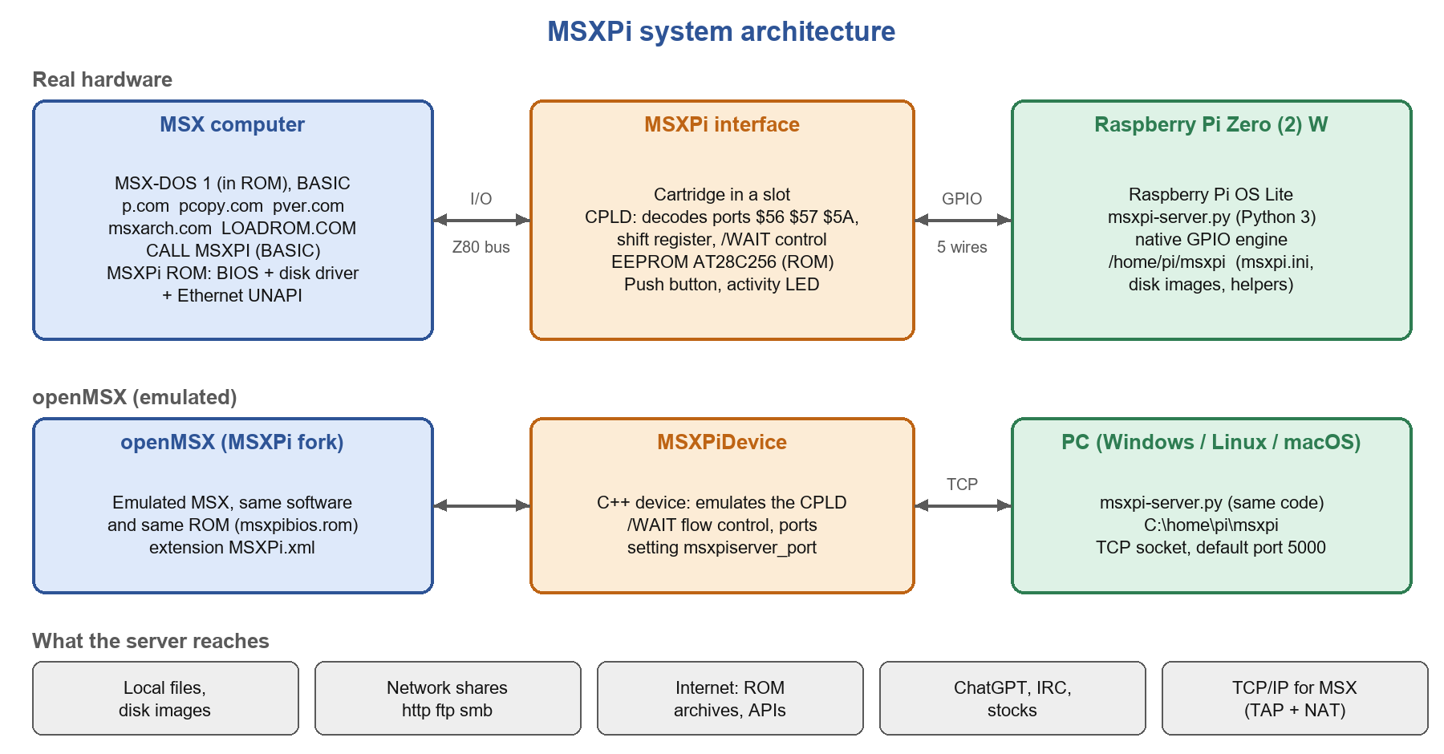
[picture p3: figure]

Figure 1: What you are setting up

Read this first: Version 1.6 breaks compatibility with earlier ROMs and servers. Upgrade the ROM, the msxpi-server, the client commands (.COM files) and, on real hardware, the CPLD firmware together. A v1.6 ROM on older CPLD firmware still works, only slower.

Pick your path: Part 1 for a real MSX with an MSXPi interface, Part 2 for openMSX with no hardware. Each step ends with a check - do not go on until the check passes.

Commands typed on the MSX are shown as C:\> lines or in a grey box; the same commands work on hardware and in openMSX.

# Part 1 - Real hardware

## What you need

- The MSXPi interface with an AT28C256 EEPROM. Build notes: documents/MSXPi Assembly Instructions.txt.
- A Raspberry Pi Zero W or Zero 2 W (a Pico does not work) with its 40-pin header on the side that matches your PCB, and a micro SD card of 8 GB or more.
- An MSX with a disk or SD interface (MSX-DOS 1, MSX-DOS 2 or Nextor) and a way to copy files to it from a PC. MSXPi's own ROM contains MSX-DOS 1 only: Nextor or MSX-DOS 2 must come from that other disk interface, which MSXPi coexists with - the best setup.
- Only if the CPLD is not programmed yet: an Altera USB-Blaster and Quartus 13.0 SP1 on Windows.
- The files in this repository: software/target (programs and ROM), hardware/CPLD_Project (firmware).

## Step 1 - Program the CPLD (only if new or older than v1.6)

1. Plug the interface into the MSX, connect the USB-Blaster to the JTAG connector, switch the MSX on.
2. In Quartus: Tools, Programmer, mode JTAG, Add File, choose the .pof for your board, tick Program/Configure and Verify, Start.

Board | File in hardware/CPLD_Project
V1.3 Rev.1 (built for v1.3 to v1.5) | MSXPi_v1.6.pof
V1.1 Rev.1, V1.2.1b | v1.1/MSXPi_v1.6_wait.pof
v0.8.2 / v1.0 (PCB v0.7 Rev.7) | v0.8.2/MSXPi_v1.6_polled.pof

Check: in BASIC, PRINT INP(&H57) must not print 254 or 255 (no CPLD answered); pver shows the same build ID in readable form later. Older boards need extra settings later (see the Legacy Support document).

## Step 2 - Write the ROM to the EEPROM

1. Copy at28c256.com and msxpibios.rom from software/target to an MSX disk. The interface must be plugged in; the Pi is not needed yet.
2. If the interface already boots a ROM, remove its enable jumper (SLTSL) first.
3. Boot MSX-DOS and list the slots: at28c256 /i. Write down the slot of the interface.
4. Write the ROM (slot 2 in this example): at28c256 /s 2 msxpibios.rom. Add /r to write slowly if your chip fails. The chip is write-protected afterwards.
5. Power off and set the jumpers. With another disk interface (recommended): remove SLTSL. To boot MSX-DOS 1 from a disk image on the Pi: close SLTSL and select the bank with the MSXPi ROM.

Check: with the enable jumper closed, CALL MSXPIVER in BASIC prints the version.

## Step 3 - Prepare the Raspberry Pi

Write "Raspberry Pi OS Lite (32-bit)" with Raspberry Pi Imager (user pi, SSH on, your WiFi entered), boot the Pi, log in and run:

wget https://tinyurl.com/MSXPi-Setup

chmod 755 MSXPi-Setup

bash ./MSXPi-Setup

The script checks the Pi, the network and the clock, installs Python 3 with the modules requests, fs and RPi.GPIO (fs needs pkg_resources, so it also pins setuptools below version 81), the packages for archives, audio and networking, builds the native GPIO engine, creates the MSXPi home directory /home/pi/msxpi (server, msxpi.ini, disk images, helpers), starts the server, checks that it runs, and reboots - a few minutes, not the hour earlier versions could take.

It asks which board you have; skip the question with --board v1.3, --board v1.1 or --board old, and see --help for the rest (WiFi, --no-reboot, ...). It is safe to run again later: it updates the server and repairs what is missing, and never overwrites your msxpi.ini.

In msxpi.ini a board without the shutdown push-button needs var RPI_SHUTDOWN=none. Optional keys: OPENAIKEY (ChatGPT), and the stock quote keys.

Insert the card, plug the Pi into the interface component side facing you, switch the MSX on. The interface LED lights when the server runs.

## Step 4 - Copy the programs to the MSX

Copy everything in software/target (at least p.com, pcopy.com, pver.com, msxarch.com, msxarch.ini, LOADROM.COM, INL.CFG) to your MSX disk or SD card.

pver

Check: pver prints the board, the CPLD build, /WAIT: yes (burst) and the server version. "Connection error"? The Pi may still be booting (first boot: up to three minutes), or the versions do not match. Press ESC, wait five seconds, try again.

## Step 5 - WiFi and network

p set WIFISSID Your Wifi Name

p set WIFIPWD YourWifiPassword

p wifi set

p reboot

Then, for TCP/IP programs (the Ethernet UNAPI is in the ROM; do not run RAMHELPR):

MSR I (MSX-DOS 1 only)

INL I

HOST GOOGLE.COM

Check: HOST prints an address. If not: p netreset. "DNS not found" means the resolver: use INL IP P <address>.

## Step 6 - Have fun

p dir /home/pi/msxpi

pcopy m:pver.com

msxarch

p chatgpt Tell me a fun fact about MSX

Update later with msxpiupd.bat (MSX files), the setup script (server) and at28c256 (ROM). Run `p shut` before switching the MSX off.

# Part 2 - openMSX

## Windows: install in one step

Download software/Server/Setup/msxpi-openmsx-install.bat from https://github.com/costarc/MSXPi and double-click it. It needs no administrator rights and downloads everything it installs:

- Python 3 and the packages the server uses, 7-Zip, Stockfish and mpv (with winget).
- C:\home\pi\msxpi - the server, msxpi.ini and the disks folder.
- C:\home\pi\msxpi\openMSX - openMSX with the MSXPi device, the MSXPi.xml extension and msxpibios.rom.
- start-openmsx.bat and an MSXPi desktop shortcut.

Double-click the MSXPi shortcut. It starts the server in its own window, then openMSX as a Panasonic FS-A1WSX with the MSXPi and 4 MB RAM extensions. The MSX boots MSX-DOS from the MSXPi boot disk - no floppy image is needed. Go on with the check in step 4.

Machine ROMs: openMSX ships only the free C-BIOS ROMs; put the FS-A1WSX system ROMs in Documents\openMSX\share\systemroms. Internet on the MSX: run msxpi-openmsx-install.bat -Network (asks for administrator rights once) - see step 5. Updating: run the installer again; it keeps msxpi.ini and the disk images.

## Manual install - what you need

- openMSX with the MSXPi device. The official openMSX is https://github.com/openMSX/openMSX; the MSXPi device is in the fork - download the newest release for your system from https://github.com/costarc/openMSX/releases (read its release notes).
- Python 3.9 or newer, with python -m pip install requests (pchess also needs certifi and chess; renderpage needs Pillow and playwright).
- 7-Zip on the PATH (zip, lzh, pma, 7z archives).
- The MSXPi home directory: /home/pi/msxpi (on Windows C:\home\pi\msxpi).
- The files from this repository: the server in software/Server/Python/src, the programs in software/target.

## Step 1 - Create the home directory

Put in it: msxpi-server.py, mapper_detect.py and every msxpi_*.py module from software/Server/Python/src, msxpi.ini (copy msxpi-JumperLeft.ini and rename it) and a disks folder with msxpiboot.dsk and tools.dsk. On Windows create C:\home\pi\msxpi and start the server from drive C: - the server path resolves on the current drive (or set MSXPI_HOME to another folder).

## Step 2 - Start the server

cd C:\home\pi\msxpi

python msxpi-server.py

It listens on TCP port 5000 and prints every command it receives. Leave it running.

## Step 3 - Prepare a disk folder

Make a folder FloppyA. Copy MSXDOS.SYS and COMMAND.COM (from software/target/disks) and all the MSXPi programs from software/target into it.

## Step 4 - Start openMSX

openmsx -machine Panasonic_FS-A1WSX -ext MSXPi -diska FloppyA

Check: at the DOS prompt type pver. It should show /WAIT: yes (burst) and the server version. "Connection error": the server is not running, the ports differ, or the versions do not match.

Optional - another TCP port: in the openMSX console (F10) type set msxpiserver_port 5001 and start the server with the environment variable MSXPI_PORT=5001 to match. Default: 5000.

## Step 5 - Network in the emulator (optional)

With the Windows installer: run it with -Network. It installs the TAP driver, and the MSXPi shortcut sets up the network whenever it is missing (asking for administrator rights). Then on the MSX INL I and HOST GOOGLE.COM.

By hand on Windows: install the OpenVPN TAP driver, run powershell -ExecutionPolicy Bypass -File msxpi-tcpip-setup.ps1 as Administrator (again after every reboot), start the server, then on the MSX MSR I (MSX-DOS 1 only), INL I, HOST GOOGLE.COM. If the server prints "falling back to MockLink", something else has the adapter open.

# Cheat sheet

Command | Does
pver | Board, CPLD, /WAIT and server version
p dir [path] | List Pi, network or r1: r2: m: locations
p cd [path] | Set / show the current path
pcopy src [dest] | Copy Pi/network to MSX (/z unpacks); pcopy a:f /path copies to the Pi
p run cmd | Run a command on the Pi (:: for a pipe)
p set NAME value | Change msxpi.ini variables (WIFISSID, OPENAIKEY, ...)
p wifi [set], p wlanreset, p netreset | WiFi, WiFi reset, rebuild the network for the MSX
p date | Set the MSX clock from the Pi
p reboot / shut / restart | Reboot the Pi / shut it down / restart the server
msxarch | Browse ROM repositories and start a game
LOADROM name /N | Load a ROM from the network
p chatgpt text | Ask ChatGPT (needs OPENAIKEY)
ESC | Abort; wait 5 seconds before the next command

# When something goes wrong

Symptom | Try
"Connection error" from pver or p | Pi still booting (wait 3 min on the first boot); ESC, wait 5 s, retry; run the server by hand and read its messages; check that ROM, server and .COM files are all v1.6
pver: Board: no MSXPi found | CPLD not programmed, or the interface is not seated; check PRINT INP(&H57)
pver: /WAIT: no (polled) | Older CPLD firmware or a board without /WAIT: works, but slower
Pi reboots by itself (older boards) | Add var RPI_SHUTDOWN=none to msxpi.ini
INL: No mapper support routines found | RAMHELPR was run before MSR: cold boot, then MSR and INL only
HOST: DNS not found | INL IP P <resolver address>; run p netreset
MSX-DOS 1 does not boot from the Pi | Wait for the Pi to boot; ESC to skip to BASIC; replace msxpiboot.dsk
openMSX: nothing happens | Start msxpi-server.py first; port must match msxpiserver_port; use the fork build of openMSX

More: README.md in the repository, the MSXPi Users and Developers Guide, documents/Legacy Support.odt for older boards, and the Hard Way Raspberry Pi tutorial (English and Portuguese). Issues: https://github.com/costarc/MSXPi/issues

MSXPi v1.6 - Quick Start

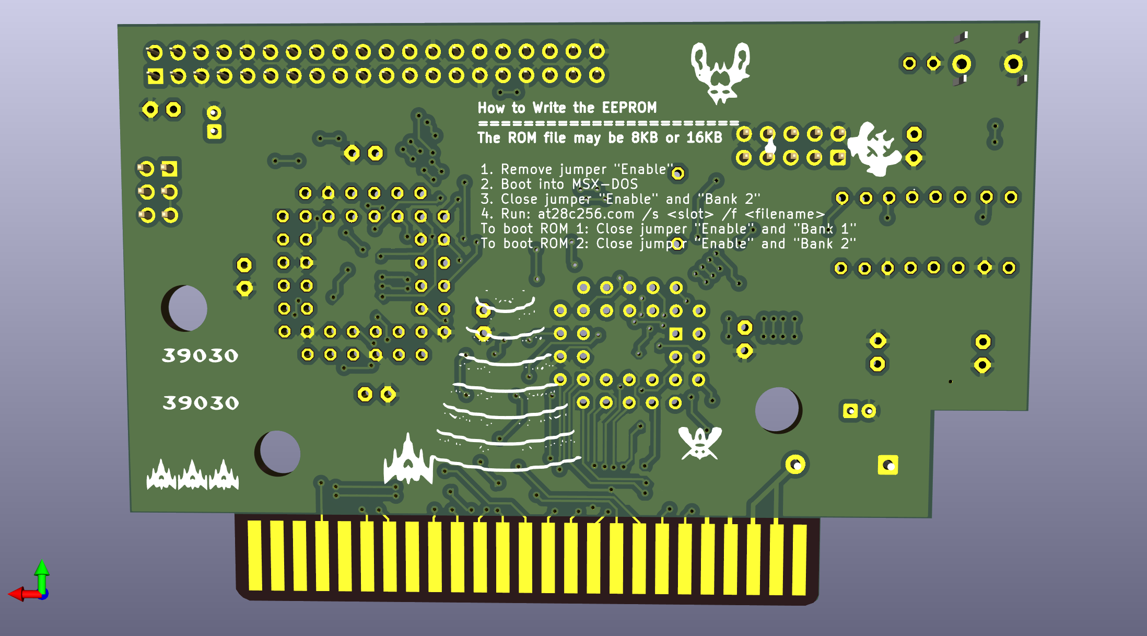
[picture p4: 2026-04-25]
hardware/Schematic/MSXPi_b.png

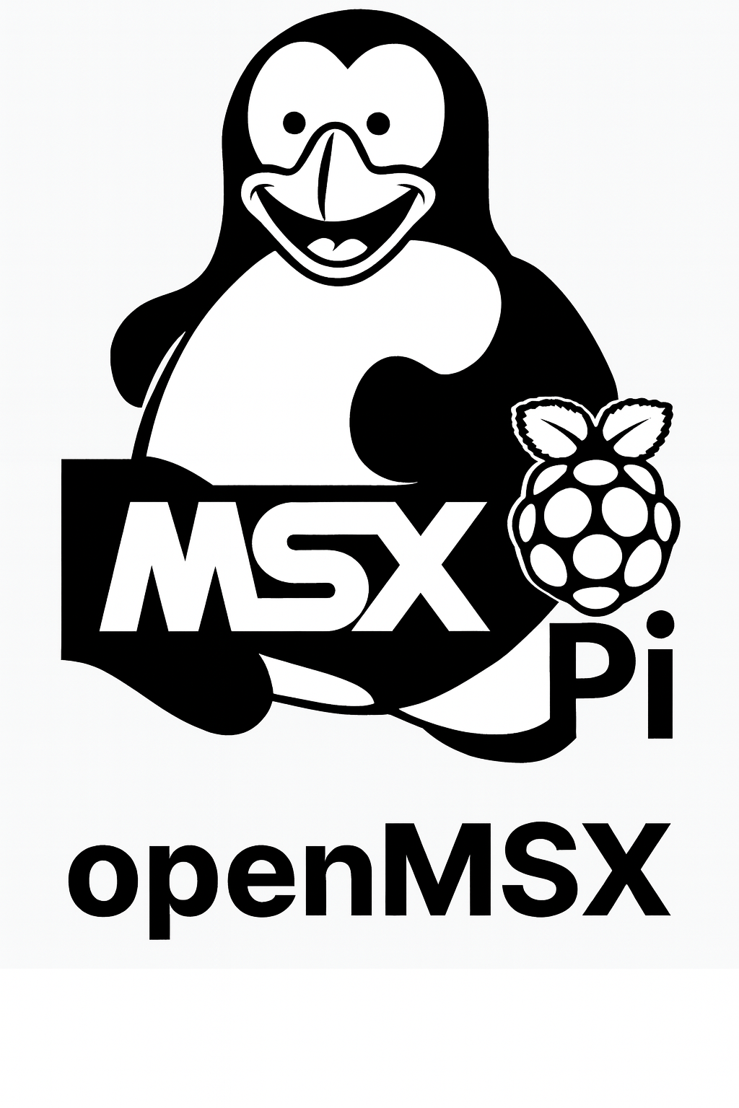
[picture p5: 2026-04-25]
hardware/Schematic/openMSX_Compatible.png

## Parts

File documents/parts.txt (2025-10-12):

Please refer to interactive BOM:
MSXPi\hardware\Schematic\Fabrication\ibom.html

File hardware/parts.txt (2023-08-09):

R1	10k Ohm
R2	10k Ohm
R3	10k Ohm
R4	10k Ohm
R5	10k Ohm
R6	10k Ohm
R7	470 oHM
LED1	3mm, 3.3v
C1,C2,C3,C4,C5,C6,C7,C8 	0.1uF (ceramic capacitor, code 104)
C9	1uF 16v (electrolytic capacitor)
U1	LD117AS33TR 3.3v Voltage Regulator
U2	CPLD Altera EPM3064ALC44-10N
U3	EEPROM AT28C256
J2	JTAG Male connector (10 x PinHead or 90 degree 10xPinHead)
J3	Pin Socket (Female, 2x3 Pins)
J4	Pin Socket (Female, 2x20 Pins)
J5/J6   Momentary push button 6mm x 2 legs (Reset / optional / not Recommended to assemble)

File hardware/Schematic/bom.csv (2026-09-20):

Reference | Value | P/N or Link | Footprint | Qty
C1,C2,C3,C4,C5,C6,C7,C10,C11 | 0.1uF | Multiple sources | Ceramic Capacitor code “104” | 9
C8,C9 | 10uF | https://www.aliexpress.com/item/1005002533909480.html | Capacitor_THT:CP_Radial_D5.0mm_P2.00mm | 2
D5 | 1N5817 | https://www.aliexpress.com/item/1005001552094086.html | Diode_THT:D_DO-41_SOD81_P10.16mm_Horizontal | 1
J2 | JTAG | https://www.aliexpress.com/item/1005005509699672.html | Connector_IDC:IDC-Header_2x05_P2.54mm_Horizontal | 1
J3 | ROM_SWITCH | https://www.aliexpress.com/item/1005006733621288.html | Connector_PinHeader_2.54mm:PinHeader_2x03_P2.54mm_Vertical | 1
J4 | Raspberry Pi GPIO | https://www.aliexpress.com/item/1005008966856219.html | PinSocket_2x20_P2.54mm_Vertical | 1
LED1 | LED3MM | Multiple sources | LED3MM | 1
R1,R2,R3,R4,R8,R9 | 10KOhm | https://www.aliexpress.com/item/32315929780.html | Resistor THT 6mm | 6
R5,R6 | 10kOhm | https://www.aliexpress.com/item/32315929780.html | Resistor THT 6mm | 2
R7 | 470 Ohm | https://www.aliexpress.com/item/32317115890.html | Resistor THT 6mm | 1
SW2 | Shutdown/Reset | https://www.aliexpress.com/item/1005006804318686.html | Tactile Push Button 6x6x5 2Pin | 1
U1 | LD117A | Multiple sources / Recommended Mouser/Digikey | 3v3 Regulator Package_TO_SOT_SMD:SOT-223-3 | 1
U2 | EPM3064ALC44 | Multiple sources / Recommended Mouser/Digikey | CPLD Altera EPM3064ALC44 PLCC Package | 1
 | Socket PLCC-44 DIP | https://www.aliexpress.com/item/1005006107285280.html | Socket for CPLD EPM3064ALC44 DIP
U4 | AT28C256_PLCC32 | https://www.aliexpress.com/item/1005007853008289.html | EEPROM ATMEL AT28C256 PLCC Package | 1
 | Socket PLCC-32 DIP | https://www.aliexpress.com/item/1005006107285280.html | Socket for EEPROM AT28C256 PLCC DIP

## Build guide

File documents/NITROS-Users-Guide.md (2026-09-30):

# NitrOS-9 for MSX User Guide

NitrOS-9 for MSX lets you use an MSX as the keyboard and screen for NitrOS-9, the
6809 operating system running in the XRoar CoCo emulator. The host computer
runs XRoar and the MSXPi server. The server starts XRoar only when you run
`NITROS` on the MSX and closes it when you press ESC, run `msxexit` in the
NitrOS-9 shell, or lose the MSX connection.

The MSX display shows a text shell. This is a terminal session, not a CoCo
graphics display. The guest system disk and a second exchange disk are held
on the host. You can copy files between the guest disk and the MSX through
the host staging directory.

## Choose how to run it

| Setup | What runs where | Needs MSXPi hardware? |
|---|---|---|
| Windows | MSXPi server, XRoar and the virtual MSX in openMSX run on Windows | No |
| Linux | MSXPi server, XRoar and openMSX run on Linux | No |
| Real MSX | MSXPi server and XRoar run on a Raspberry Pi connected to the MSXPi interface | Yes |

The Windows and Linux setups are useful for trying NitrOS-9 for MSX with an
emulated MSX. The virtual MSX uses the MSXPi device supplied with openMSX.
The hardware setup connects an actual MSX keyboard and VDP to the Pi through
the MSXPi board. A PC running Windows or Linux cannot replace that GPIO
connection to a physical MSX.

## Prepare the NitrOS-9 for MSX files

The MSX-DOS client is `NITROS.COM`. The host files are `boot.bin`, `boot.dsk`,
`exchange.dsk`, the `files` staging folder, and `nitros.json`. You can use the
[prebuilt runtime package](../../outputs/nitros-msx-runtime.zip), or build a
new runtime using the [image build instructions](NITROS-build.md). Copy the
runtime files to a new host folder. Keep `boot.dsk` and `exchange.dsk`
writable; NitrOS-9 updates the system disk as it runs.

You also need XRoar and the CoCo ROM files `bas13.rom`, `extbas11.rom` and
`disk11.rom`. These firmware images are not included. Use ROMs you are
entitled to use. NitrOS-9 itself is open source and its upstream project is
linked below.

Edit `nitros.json` for the computer that will run XRoar. Set `xroar` to an
argument list for your XRoar executable, the CoCo ROM folder, and the **full
path** to `boot.bin`. Set `boot_disk`, `exchange_disk`, `exchange_dir` and
`os9` to the actual runtime files and ToolShed `os9` utility. Relative disk
and staging paths are resolved beside `nitros.json`; paths inside the `xroar`
argument list must be absolute. For example, the sample is configured for a
Raspberry Pi. Replace its executable, ROM and boot paths when using Windows or
Linux.

Do not add `boot.dsk` or `exchange.dsk` as XRoar disk images. XRoar boots from
`boot.bin` and the MSXPi server presents both images to the guest over its
DriveWire connection.

## Windows: emulated MSX with openMSX

This setup runs the MSXPi server, openMSX and XRoar on the Windows PC. It is a
software test setup and does not attach to a physical MSXPi board.

1. Install the MSXPi openMSX package from the repository's
   [Windows setup script](../Server/Setup/msxpi-windows-setup.ps1). It installs
   Python, the MSXPi server and the project's MSXPi-enabled openMSX build.
   From PowerShell in the project, run `powershell -ExecutionPolicy Bypass
   -File .\software\Server\Setup\msxpi-windows-setup.ps1`. The setup script
   keeps its server under `C:\home\pi\msxpi` by default. The
   project's current main README has the complete first-time setup and
   network-option steps.
2. Install [XRoar for Windows](https://www.6809.org.uk/xroar/dl/) and ToolShed. Install or copy the three CoCo
   ROM images into a known folder. Extract the NitrOS-9 for MSX runtime files into,
   for example, `C:\home\pi\msxpi\nitros`.
3. Edit `C:\home\pi\msxpi\nitros\nitros.json`. Example values are
   `C:\Apps\XRoar\xroar.exe`, `C:\Apps\CoCoROMs`,
   `C:\home\pi\msxpi\nitros\boot.bin`, and
   `C:\Apps\ToolShed\os9.exe`. In JSON strings, write each backslash twice,
   for example `C:\\Apps\\XRoar\\xroar.exe`.
4. Copy `NITROS.COM` to a DOS drive in the openMSX emulated MSX. Start the
   `start-openmsx.bat` shortcut created by the installer. At the MSX-DOS
   prompt, set the runtime path in the host's `msxpi.ini` by typing
   `p set NITROS_CONFIG C:\home\pi\msxpi\nitros\nitros.json`. Then type
   `NITROS`.

The `C:\Apps\LibreOffice` install is not needed to run NitrOS-9 for MSX; use it to
open or print this guide. XRoar runs without a visible window during the MSX
session. It writes diagnostics to `xroar.log` beside the configured log file.

## Linux: emulated MSX with openMSX

These instructions are for Debian or Ubuntu. Install openMSX, XRoar, Python,
and ToolShed. The [XRoar manual](https://www.6809.org.uk/xroar/doc/xroar.shtml)
lists Linux installation options; on supported apt setups XRoar can be
installed with `sudo apt install xroar`.

1. Install the project's MSXPi openMSX build and configure the virtual MSX
   using the [MSXPi Windows and openMSX instructions](../../README.md#quick-start-2---openmsx-no-hardware-needed)
   or your Linux openMSX package. Put `NITROS.COM` on its DOS disk.
2. Extract the runtime files to a writable folder such as
   `~/msxpi/nitros/`. Install CoCo ROMs in `~/.xroar/roms/`, or use another
   ROM folder in your JSON configuration.
3. Edit `nitros.json`: set the Linux XRoar executable (often `xroar`), ROM
   folder, full path to `boot.bin`, and the path to the `os9` utility.
4. Start the MSXPi server from the MSXPi Python source directory:

   ```sh
   python3 -u msxpi-server.py
   ```

   Keep this process running while using the virtual MSX. In its MSX-DOS
   prompt, type `p set NITROS_CONFIG /home/pi/msxpi/nitros/nitros.json`
   (substitute the actual full Linux path if different); this saves the path
   in the server's `msxpi.ini`. The openMSX MSXPi
   device connects to its TCP server on port 5000 by default. Start openMSX
   with the MSXPi extension and boot its MSX-DOS disk.
5. At the emulated MSX-DOS prompt, type `NITROS`. Press ESC to leave the
   guest and return to MSX-DOS.

## Real MSX hardware: Raspberry Pi

For a physical MSX, the Raspberry Pi must be connected to the MSX through a
compatible MSXPi interface. Use a Raspberry Pi Zero W or Zero 2 W with a
40-pin header that matches the board. The Pi provides the MSXPi server, XRoar,
the disk images and the files staging folder. The existing MSXPi setup guide
in the [main README](../../README.md#quick-start-1---real-hardware-msxpi-interface--raspberry-pi)
covers Raspberry Pi OS, board programming, ROM installation, jumper settings
and initial hardware checks. Complete those steps before installing the
NitrOS-9 for MSX files below.

1. Install Raspberry Pi OS and the MSXPi software on the Pi. Confirm the
   MSXPi interface works with the existing `pver` command before adding
   NitrOS-9 for MSX.
2. Install XRoar with Becker-port support, ToolShed's `os9` tools, LWTOOLS
   and `make`. The [NitrOS-9 for MSX image build instructions](NITROS-build.md)
   list the tested versions and build command. CoCo ROM images must be supplied
   separately.
3. Copy `boot.bin`, `boot.dsk`, `exchange.dsk`, `files/` and the sample JSON
   into `/home/pi/msxpi/nitros/`. Edit `nitros.json` with the paths on the Pi.
   The default example uses `/home/pi/msxpi/nitros/` and
   `/home/pi/roms/coco/`.
4. Install the new `msxpi_nitros.py` module with the updated MSXPi server. In
   the MSX-DOS prompt, type `p set NITROS_CONFIG
   /home/pi/msxpi/nitros/nitros.json`. This stores the runtime path in the
   server's `msxpi.ini`; no service environment change or restart is needed.
   The setup and update scripts in this branch already include the new module.
5. Copy `NITROS.COM` to an MSX-DOS disk or Nextor volume. Insert the MSXPi
   interface and start the Pi. After the MSXPi ready indicator is active, run
   `NITROS` on the physical MSX.

XRoar starts only after the MSX sends the `nitros start` command. It listens
for the DriveWire connection on the Pi's loopback interface, so the Becker
port is not exposed to the LAN. Keep the Pi running while NitrOS-9 is open.

## Using the console

At the MSX-DOS prompt, run:

```text
A> NITROS
```

The shell prompt appears on the MSX screen. Type NitrOS-9 commands as usual.
The shell echoes typed characters and handles line editing. The MSX keyboard
sends ordinary text and Enter to the guest. Press **ESC** to close XRoar and
return to MSX-DOS. Ctrl-C goes to NitrOS-9; it does not close the emulator.

To exit from inside NitrOS-9, type:

```text
OS9: msxexit
```

Use `msxexit` rather than `ex`: `ex` exits the current shell and the NitrOS-9
startup normally opens another one. If the MSX resets or loses its link,
XRoar exits after the 15-second console lease expires. Run `NITROS stop` from
MSX-DOS to recover a session that has stopped responding.

## Move files between the MSX and NitrOS-9

There are two steps in each direction: PCOPY moves a file between the MSX and
the host staging folder; a NITROS subcommand copies it between that folder
and the guest exchange disk. The examples use MSX 8.3 filenames and
`/home/pi/msxpi/nitros/files` as the host staging folder. Change the host path
to match `exchange_dir` in your `nitros.json`.

**MSX to NitrOS-9:**

```text
A> PCOPY A:HELLO.TXT /home/pi/msxpi/nitros/files/HELLO.TXT
A> NITROS put HELLO.TXT HELLO.TXT
A> NITROS
OS9: dir /x1
OS9: copy /x1/HELLO.TXT /x1/HELLO.BAK
OS9: msxexit
A> NITROS get HELLO.BAK HELLO.BAK
A> PCOPY /home/pi/msxpi/nitros/files/HELLO.BAK A:HELLO.BAK
```

**Host to NitrOS-9:** put the file in the configured `files` folder, exit
NitrOS-9 if it is running, then type `NITROS put HOSTNAME GUESTNAME`. Inside
the shell, guest files live on `/x1`. Copy them to `/dd` if you want them on
the persistent boot disk.

`NITROS list` shows files on the exchange disk. If the listing is long, use
the next `NITROS list N` command printed at the end. Exports refuse to
overwrite a file already in the host staging folder; remove or rename that
file before copying a replacement. The bridge locks the images while XRoar
is running and releases them when the session ends, so do file transfers
while NitrOS-9 is stopped.

## Troubleshooting

| Symptom | What to check |
|---|---|
| `NITROS` says MSXPi connection error | Start the MSXPi server, check `p set NITROS_CONFIG` and verify that the emulator's MSXPi device is connected or the physical MSXPi ready indicator is active. |
| XRoar reports a missing ROM | Check all three CoCo ROMs and the `-rompath` in `nitros.json`. |
| NitrOS-9 stops while opening a disk | Check the disk paths and write permissions; close any other process that has mounted the disk images. |
| XRoar will not start on Linux | Check the `xroar` command and Becker-port support. Confirm the configured `-run` path points to `boot.bin`. |
| ESC was not pressed and the MSX restarted | Wait for the 15-second lease to close XRoar, then launch `NITROS` again. |
| Copy says the guest disk is busy | Exit NitrOS-9 completely with `msxexit` or ESC, then repeat the host file transfer. |

## Build the guest images from source

See [NITROS-build.md](NITROS-build.md) for the pinned NitrOS-9 checkout,
image creation command and runtime layout. The historical
[NitrOS-9 SourceForge releases](https://sourceforge.net/projects/nitros9/files/releases/)
are useful project archives; the tested disk recipe builds from the current
NitrOS-9 source instead.

## References

- [MSXPi project and real-hardware/openMSX setup](../../README.md)
- [MSXPi Windows setup script](../Server/Setup/msxpi-windows-setup.ps1)
- [XRoar Windows and Linux downloads](https://www.6809.org.uk/xroar/dl/)
- [XRoar manual](https://www.6809.org.uk/xroar/doc/xroar.shtml)
- [NitrOS-9 project](https://github.com/nitros9project/nitros9)
- [NitrOS-9 historical releases](https://sourceforge.net/projects/nitros9/files/releases/)

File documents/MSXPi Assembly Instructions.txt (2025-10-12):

1. Solder LD117A voltage converter
2. Short/solder SMD jumpers CS,CLK,MISO,MOSI,RDY
3. Solder all resistors
4. Solder CPLD socket, EEPROM, RPI Deader, JTAG connector
5. Solder ceramic capacitors (104) and Electrolitic capacitors
6. Solder all remaining parts (headers, push button, led, diode)
7. Connect a USB-Blaster to the MSXPi JTAG connector and to a PC USB to program the CPLD:
 - Recommended to use Quartus Version 13.0 SP1
 - Open Quartus
 - Select tools -> Programmer
 - Mode should be selected already: JTAG
 - Make sure you see the USB-Blaster in the "Hardware Setup..." before proceeding
 - Click "Add File" from the left vertical menu/buttons
 - Browse tp the folder where MSXPi.pof is (should be: \hardware\CPLD_Project\MSXPi.pof) and select it
 - Tick the boxes "Program/Configure" and "Verify"
 - Click "Start" from the left Menu/Buttons.
 - Progress should move to 100% and Successful.
8. Check CPLD programming from MSX Basic:
  print inp(&h56)
  This should return the firmware version - If it returns 255, the CPLD was not programmed correctly.

Notes:
- step 2: These jumpers allow to use a different set of GPIOs on the Raspberry Pi.
- step 4: It's recommended to use a socket for the EEPROM, but not absolutely necessary. Using an EEPROM helps in case of a need to replace the EEPROM in the future.

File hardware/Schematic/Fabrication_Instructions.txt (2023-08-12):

These instructions are for PCBWAY.COM
The lines with "=>" are the only ones that must be changed - the others are default for PCBWAY.

The defaults will work quite well, but I recommend to change "Edge Connector" option when specifying the details for fabrication - see below.
These instructions will result in the cheapest cost (around USD5 for 5 Units)

=> Length: 99.90mm, Width: 64.50mm
Layers: 2, Thickness: 1.6mm
Material: FR-4
FR4-TG: TG 150-160
Thickness: 1.6
Min Track/Spacing: 6/6mil
Min Hole Size: 0.3mm
Solder Mask: -> choose what you like, but some places charge more for this option.
Silkscreen: White (change this color to something else if you had choose "White Solder Mask")
=> Edge connector: Yes, Bevelling: Yes - 30 Degrees
=> Surface Finish: HASL lead free (you can choose instead gold immersion but will be a lot more expensive)

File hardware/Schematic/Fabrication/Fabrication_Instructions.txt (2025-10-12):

These instructions are for PCBWAY.COM
The lines with "=>" are the only ones that must be changed - the others are default for PCBWAY.

The defaults will work quite well, but I recommend to change "Edge Connector" option when specifying the details for fabrication - see below.
These instructions will result in the cheapest cost (around USD5 for 5 Units)

=> Length: 99.82mm, Width: 64.11mm
==> Quantity: 10 pcs (will cost the same as 5 pcs)
Layers: 2
Material: FR-4
FR4-TG: TG 150-160
Thickness: 1.6
Min Track/Spacing: 6/6mil
Min Hole Size: 0.3mm
Solder Mask: -> choose what you like, but some places charge more for this option.
Silkscreen: White (change this color to something else if you had choose "White Solder Mask")
=> Edge connector: Yes, Bevelling: Yes - 30 Degrees
=> Surface Finish: HASL with lead or HASL without lead (you can choose gold immersion but will be a lot more expensive)

Keep the default for all remaining options.

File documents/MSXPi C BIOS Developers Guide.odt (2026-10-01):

# MSXPi C BIOS – Developer Documentation

This document provides a complete technical overview of the MSXPi C BIOS source code, describing its architecture, available functions, and how each component participates in the MSX↔Raspberry Pi communication protocol. It is intended for developers extending MSXPi, integrating new commands, or maintaining the firmware.

## 1. Overview

The MSXPi BIOS is a low‑level communication layer that allows MSX computers to exchange data with a Raspberry Pi using GPIO‑based serial signalling. It implements:

- A reliable byte‑transfer protocol
- Handshake and block‑transfer mechanisms
- Error detection and recovery (checksums, CTRL+ESC abort)
- Command‑building utilities
- Fast screen output helpers

The BIOS is written in C using Fusion‑C and custom MSX‑DOS crt0, with careful attention to timing, reentrancy, and memory layout.

## 2. Printing Utilities

### void Print(char* text)

Prints a null-terminated string to the screen.

- Basic text output function.

### void PrintNumber(uint16_t value)

Prints a decimal number.

- Converts and outputs the number as ASCII digits.

### void pprintf(char* text, uint16_t value)

Prints a string followed by a decimal number.

- Uses Print() and PrintNumber().
- Useful for debugging numeric return codes.

### void pprints(char* text, char* value)

Prints a string followed by another string.

- Convenience wrapper around Print().

### void FastPrint(char* text)

High‑speed text output routine.

- First character printed via PrintChar() to set cursor position.
- Remaining characters sent directly to VDP port 0x98.
- Much faster than Locate() + Print().

## 3. Low‑Level GPIO Protocol

### 3.1 CHKPIRDY – Check Pi Ready State

uint8_t CHKPIRDY(void)

Core polling loop that determines the Pi’s readiness state.

- Samples CTRL+ESC every 256 passes by reading the key matrix directly (no BIOS call, no key taken from the key buffer; ESC alone does not abort).
- Reads CONTROL_PORT1 to detect protocol states:
  - CHK_STATE_0
  - CHK_STATE_2
- Returns RC_ESCPRESSED if CTRL+ESC is detected.

This function is the timing‑critical heart of the MSXPi protocol.

### 3.2 PIREADBYTE

uint8_t PIREADBYTE(uint8_t* byte)

Reads one byte from the Pi.

- Performs handshake via CHKPIRDY().
- Supports legacy and new protocol versions.
- Returns RC_SUCCESS or error codes.

### 3.3 PIWRITEBYTE

uint8_t PIWRITEBYTE(uint8_t byte)

Writes one byte to the Pi.

- Uses CHKPIRDY() to ensure safe timing.
- Returns RC_SUCCESS if Pi accepted the byte.

## 4. Block‑Transfer Protocol

The MSXPi BIOS implements a robust block‑based data transfer system with checksums and retransmission.

### 4.1 RECVDATA

uint8_t RECVDATA(uint8_t* dest, uint16_t* size, uint16_t* maxbufsize)

Receives an entire multi‑block payload from the Pi.

- Performs initial handshake.
- Receives blocks with:
  - header_rc
  - length
  - block index
  - payload
  - checksum
- Validates checksum and requests retransmission if needed.
- Returns total received size.

### 4.2 RECVDATA_ONEBLOCK

uint8_t RECVDATA_ONEBLOCK(uint8_t* dest, uint16_t* size, uint16_t msx_blocksize)

Receives exactly one block.

- Used by printstdout() and other streaming operations.
- Enforces block index = 0.

### 4.3 SENDDATA2

uint8_t SENDDATA2(uint8_t* src, uint16_t size, uint16_t* maxbufsize)

Sends data from MSX to Pi.

- Mirrors RECVDATA protocol.
- Handles retransmission on checksum mismatch.
- Performs status handshake after each good block.

## 5. Handshake Utilities

### uint8_t PerformHandshake(uint16_t msx_blocksize)

Performs the initial READY/READY_ACK handshake.

- Sends MSX block size.
- Used by both send and receive operations.

## 6. Command Line Processing

### char* GetCmdLineParameters(void)

Reads MSX‑DOS command tail from address 0x80.

- Trims leading spaces.
- Ensures null termination.

### uint8_t SendCommandToMSXPi(const char* cmd, bool appendTail)

Builds and sends a command string to the Pi.

- Combines primary command and DOS tail.
- Stores buffer at fixed address 0x8000 to avoid mapper conflicts.
- Sends via SENDDATA2.

## 7. Error Handling

### uint8_t parseConnError(const uint8_t rc)

Prints human‑readable error messages for protocol return codes.

- Handles checksum errors, handshake failures, buffer overflow, file not found, etc.

## 8. Memory Utilities

### uint16_t get_sp(void)

Returns current stack pointer.

### uint16_t get_max_buffer_size(void)

Computes available buffer space based on heap top and stack.

### uint8_t* get_buffer_ptr(void)

Returns pointer to buffer at heap top.

### char* u16_to_ascii(uint16_t value, char* buf)

Converts a 16‑bit integer to ASCII.

## 9. Streaming Output

### uint8_t printstdout(uint8_t* buffer, uint16_t maxbufsize)

Receives text from Pi and prints it to the MSX screen.

- Uses RECVDATA_ONEBLOCK.
- Prints each block as soon as it arrives.

## 10. Summary of Return Codes

Common return codes used throughout the BIOS:

- RC_SUCCESS – Operation completed
- RC_READY – More blocks follow
- RC_CHKSUM_ERR – Checksum mismatch
- RC_CONNERR – Communication error
- RC_HANDSHAKEERR – Handshake failure
- RC_INVALIDCOMMAND – Command parsing error
- RC_BUFOVFLW – Buffer overflow
- RC_FILENOTFOUND – File not found on Pi
- RC_ESCPRESSED – User aborted with CTRL+ESC

## 11. Developer Notes

- Timing is critical: avoid calling BIOS routines inside interrupt hooks.
- CHKPIRDY’s CTRL+ESC sampling is intentionally sparse for performance.
- The command buffer is placed at 0x8000 to avoid mapper corruption.
- All transfers use checksums for reliability.

## 12. Extending the BIOS

To add new MSXPi commands:

1. Build the command string using SendCommandToMSXPi().
2. Implement the corresponding Python handler.
3. Use SENDDATA2/RECVDATA for binary transfers.
4. Use printstdout for text output.

This documentation should give you a clear and complete understanding of the MSXPi C BIOS architecture and how to use its functions effectively.

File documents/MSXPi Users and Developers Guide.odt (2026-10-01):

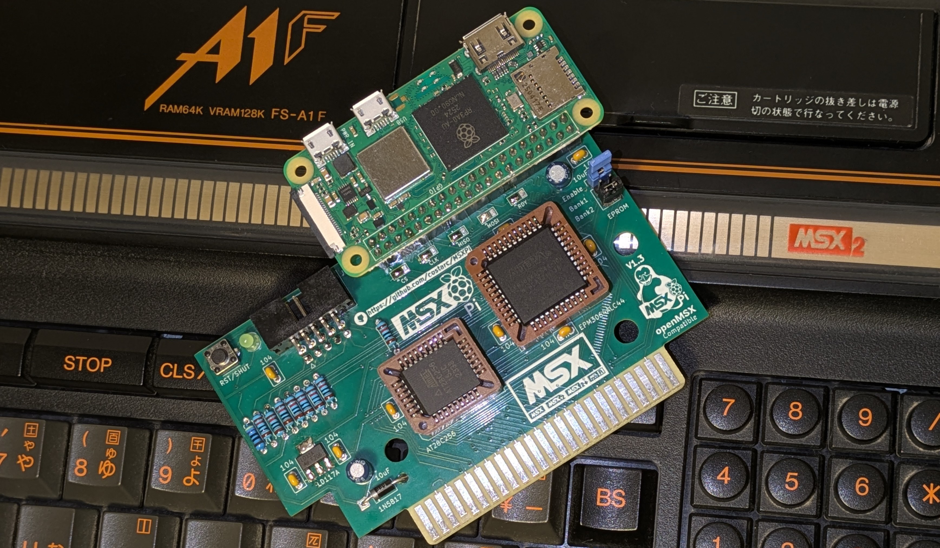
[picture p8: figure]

MSXPi Interface

Version 1.6

User's and Developers Guide

https://github.com/costarc/MSXPi

Copyright (c) 2015-2026 Ronivon Costa.

Software: MIT licence. Hardware: CERN OHL v1.2.

# Introduction

MSXPi is a bridge between a classic MSX computer and a Raspberry Pi. A cartridge (the MSXPi interface) exposes three I/O ports to the MSX; whatever the MSX writes to them is delivered to a Python program, the msxpi-server, and whatever the server answers is read back by the MSX. Through this simple link the MSX gains network drives, the internet, disk images, ROM archives, ChatGPT, IRC, TCP/IP (through the UNAPI standard) and control over the Raspberry Pi itself.

MSXPi is also available as a virtual device in the openMSX emulator. The emulated MSX runs exactly the same ROM and the same programs, and talks to the same msxpi-server over a local TCP socket, so software can be developed and tested without any hardware. Software written under openMSX runs unchanged on a real MSX with MSXPi.

## About this guide

This guide is for two audiences and is organised accordingly:

- Users need chapters 3 (Getting Started) and 4 (Users Guide): how to build or install MSXPi, prepare the Raspberry Pi, use every p command, load ROMs, get the MSX on the network and recover from problems.
- Developers need chapters 2 (Architecture) and 5 to 8 (Developers Guide, BASIC, C, Assembly): how the pieces fit together, the block protocol, and how to write programs in BASIC, C and Assembly and add commands to the server.
- The appendices hold reference tables: return codes, I/O ports, the msxpi.ini variables and the GPIO wiring.

The README in the repository has a shorter step-by-step Quick Start for both real hardware and openMSX; the Release_Notes file lists what changed in each version.

## What's new in version 1.6

Version 1.6 breaks software compatibility with earlier ROMs and servers: upgrade the ROM, the msxpi-server, the client commands and (on real hardware) the CPLD firmware together. The main changes:

- /WAIT flow control. The CPLD holds the Z80 /WAIT line while a byte is in flight, so payloads move with INIR/OTIR instead of polling. Measured on real hardware, 256 KB now takes 51.95 s instead of 1:45. A v1.6 ROM on older firmware falls back to the polled transfers and still works, only slower.
- Ethernet UNAPI in the ROM. InterNestor Lite, telnet, HGET and other UNAPI programs work over the MSXPi link, on the Pi and in openMSX (also on Windows).
- MSX-DOS 2 / Nextor coexistence: fixes to the disk driver (GETDPB, direct sector transfers) so an MSXPi drive works from a Nextor or MSX-DOS 2 system that runs on another interface. The MSXPi ROM itself contains MSX-DOS 1 only.
- msxarch, a network ROM browser and loader for plain ROMs and MegaROMs, with server-side mapper detection; LOADROM /N loads a ROM by name.
- New and improved commands: pver (hardware report), pcopy in both directions, p netreset, p wlanreset, p reload, a fixed p wifi.
- Older boards: the v1.6 CPLD image, ROM and server run on every earlier MSXPi board.
- BASIC extension without an EPROM: MSXPIEXT.BIN builds again and shares the CALL MSXPI handler with the ROM.
- openMSX emulates the CPLD /WAIT control and no longer truncates large transfers.

## What MSXPi is and how it works

MSXPi combines a custom MSX cartridge with a Raspberry Pi Zero class board. The interface exposes I/O ports that the MSX can read and write, and the Raspberry Pi interprets what arrives to provide services such as:

- access to the Pi SD card and to network shares as storage (p dir, pcopy);
- WiFi and TCP/IP for the MSX, and internet access (HTTP, HTTPS, FTP, SMB);
- disk images: the Pi can present disk images as drives A: and B: and boot MSX-DOS 1 from them;
- loading ROM games from archives on the network (msxarch, LOADROM /N);
- ChatGPT, IRC, weather and stock quote clients;
- audio playback on the Pi, and running any shell command on the Pi from MSX-DOS.

## Hardware compatibility and Raspberry Pi models

MSXPi works with most MSX generations (MSX1, MSX2, MSX2+, turbo R), but compatibility is not universal: a few models have unusual slot or bus implementations. MSX-DOS itself needs 64 KB of RAM.

- Raspberry Pi Zero 2 W / Zero W - recommended: small, built-in WiFi, low power, and powered directly from the cartridge slot.
- Raspberry Pi Zero (no W) - compatible, but needs a USB WiFi dongle for networking.
- Raspberry Pi Pico - not supported. A Pico is a microcontroller and cannot run the Linux-based server.

The MSXPi PCB expects the Pi with its 40-pin header on a specific side. A Zero WH has the header on the component side; use it only if your PCB has the socket on the back. See section 3.1.

# Architecture

MSXPi has three parts: the MSX side (ROM plus programs), the interface (CPLD and EEPROM in a cartridge) and the server side (msxpi-server.py). The same server code runs on the Raspberry Pi, where the link is five GPIO wires, and on a PC beside openMSX, where the link is a TCP socket.


Figure 1: System architecture: real hardware (top) and openMSX (bottom)

## The interface and its I/O ports

The CPLD decodes three I/O ports and turns every access into an 8-bit serial transfer with the Pi (SPI-like: CS, CLK, MOSI, MISO plus a ready line). The MSX never sees the wires, only the ports:

Port | Name | Use
$56 | CONTROL_PORT1 | OUT $FF resets the transfer state and clears /WAIT mode. OUT $00 starts a one-byte transfer. IN reads 0 when no transfer is running and the Pi is ready.
$57 | CONTROL_PORT2 | IN returns the CPLD build ID (low 6 bits; $FE/$FF: no interface). OUT $01 switches /WAIT mode on, OUT $00 off. Firmware without the mode register ignores the write, which is how software probes for /WAIT support.
$5A | DATA_PORT1 | OUT: byte to send to the Pi (data or command). IN: byte received from the Pi.

Since v1.6 a byte transfer can also run in /WAIT mode: after OUT to $5A or IN from $5A the CPLD pulls the Z80 /WAIT line low until the byte has been clocked, so a block instruction (INIR, OTIR) can move a whole 256 or 512 byte run at 21 T-states per byte. The Pi keeps its ready line high for the entire run (SPI_BurstOut / SPI_BurstIn); without that, the gap between two bytes would let INIR read a stale byte and desynchronise the stream.

The ROM in the EEPROM (msxpibios.rom, 16 KB at $4000, header "AB") holds the BIOS, the disk driver and the Ethernet UNAPI. The MSXPi PCBs allow the ROM to be disabled with a jumper, in which case the interface is used only through the .COM programs, or replaced by MSXPIEXT.BIN (loaded into RAM from BASIC) when there is no EEPROM.

## Software layers

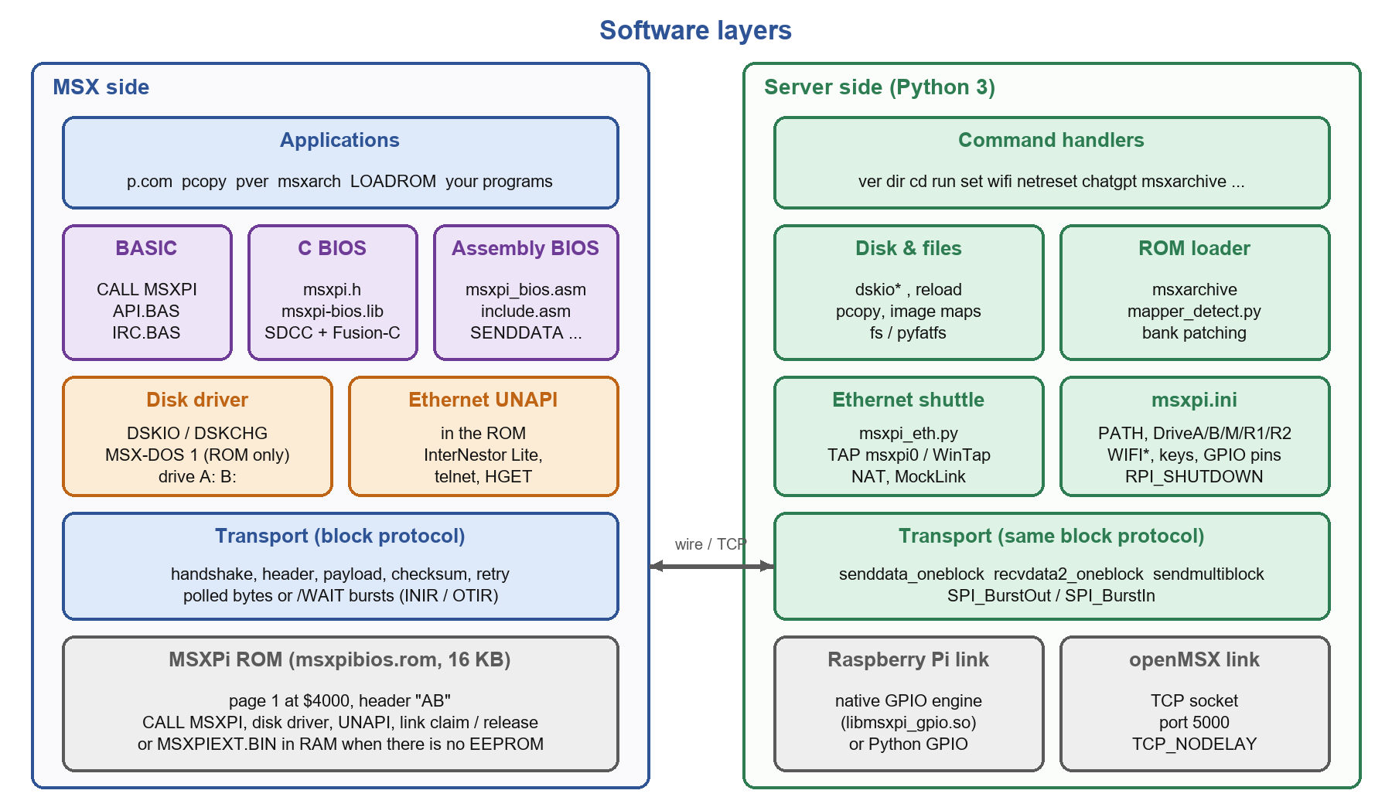
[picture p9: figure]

Figure 2: Software layers on the MSX and on the server

On the MSX every program - a .COM file, a BASIC program, a driver - uses the same transport routines, available in three flavours: CALL MSXPI for BASIC, the C BIOS (msxpi.h, msxpi-bios.lib) and the assembly BIOS (msxpi_bios.asm). They all implement the same block protocol of section 2.3.

On the server, msxpi-server.py is a small main loop; the commands live in the msxpi_cmd_*.py modules beside it. It reads a command and calls the Python function registered under the first word in the COMMANDS table; the function sends its reply with sendmultiblock(). Adding a command to MSXPi therefore means writing one Python function and registering it (section 5.2).

## The block transfer protocol

Everything the MSX and the server say to each other travels in blocks. A block carries one command, one reply, or one chunk of a larger transfer, protected by a checksum:

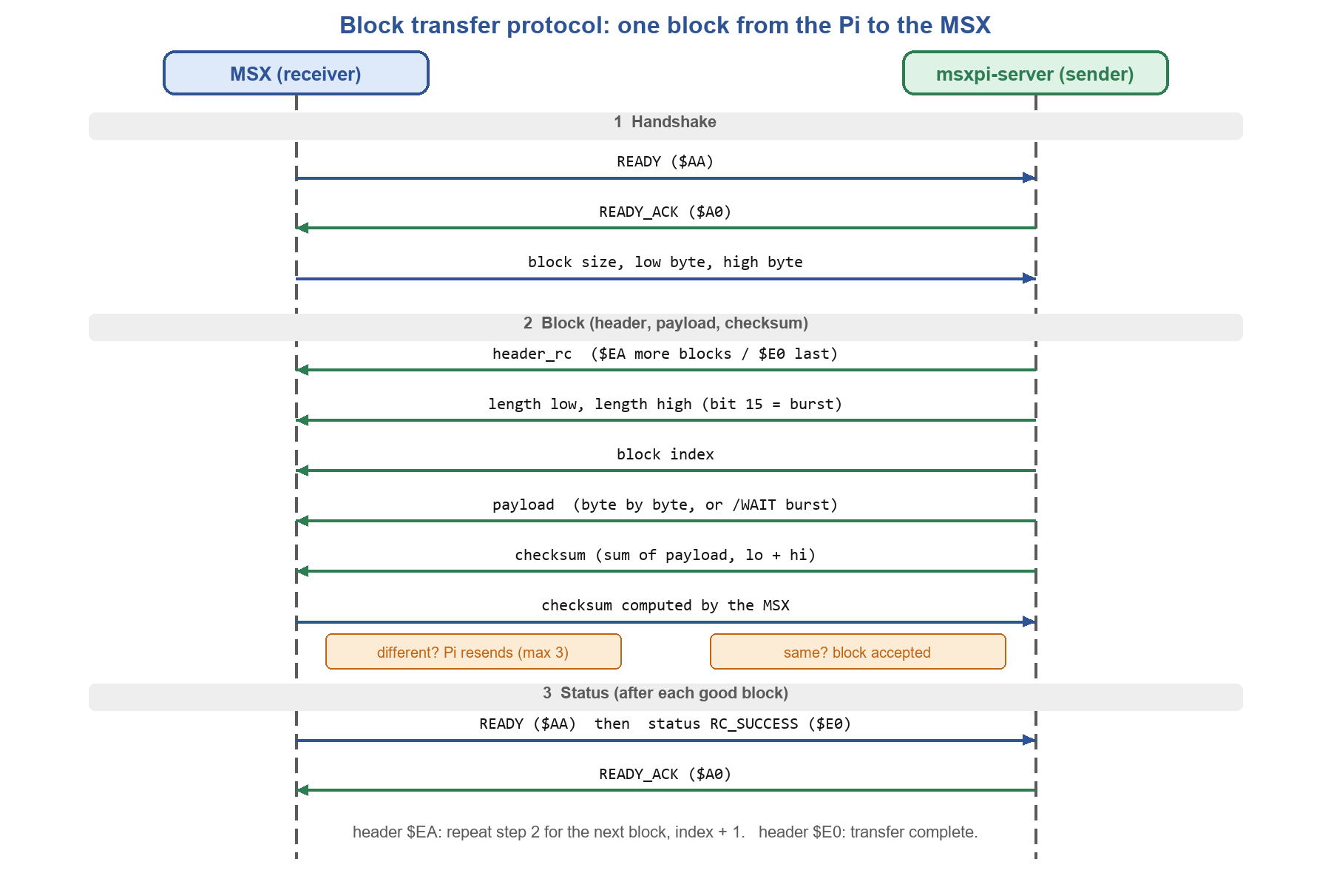
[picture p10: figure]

Figure 3: One block, Pi to MSX. MSX to Pi is symmetrical: the MSX becomes the sender.

Field | Size | Meaning
header_rc | 1 | Return code: $EA RC_READY (more blocks follow), $E0 RC_SUCCESS (last block), or an error code
length | 2 | Payload size, low byte first. Bit 15 set means "payload follows in /WAIT burst mode"
block index | 1 | Sequence number, starting at 0
payload | length | The data. Blocks are at most BLKSIZE (512) bytes on the wire; the receiver announces its maximum in the handshake
checksum | 1 | Sum of all payload bytes, low byte plus high byte of the 16-bit sum

Rules worth knowing:

- The receiver echoes the checksum it computed. If it differs, the sender resends the whole block (header included), up to three times; then the transfer fails with RC_CHKSUM_ERR. A retry never uses /WAIT bursts.
- Burst is negotiated per block: the receiver marks the block size it asks for, the sender marks the length it answers with, and either side can decline. Bursts are used only for whole 256-byte runs (a 512-byte disk sector); anything else goes byte by byte.
- After every good block there is a short status exchange (READY, status, READY_ACK) so both sides agree whether another block follows.
- While waiting for its counterpart, each side polls the keyboard: CTRL+ESC aborts the transfer on the MSX (ESC alone is an ordinary key and never aborts), which makes the server resynchronise (about five seconds).
- Timeouts are generous on the server (180 s per byte wait) because a slow MSX may take a long time to drain a large block.

## Commands and replies

A command is a text block. The first word names the server function, the rest are its parameters; for MSX-DOS programs the parameters are the DOS command line. The server replies with one or more blocks:

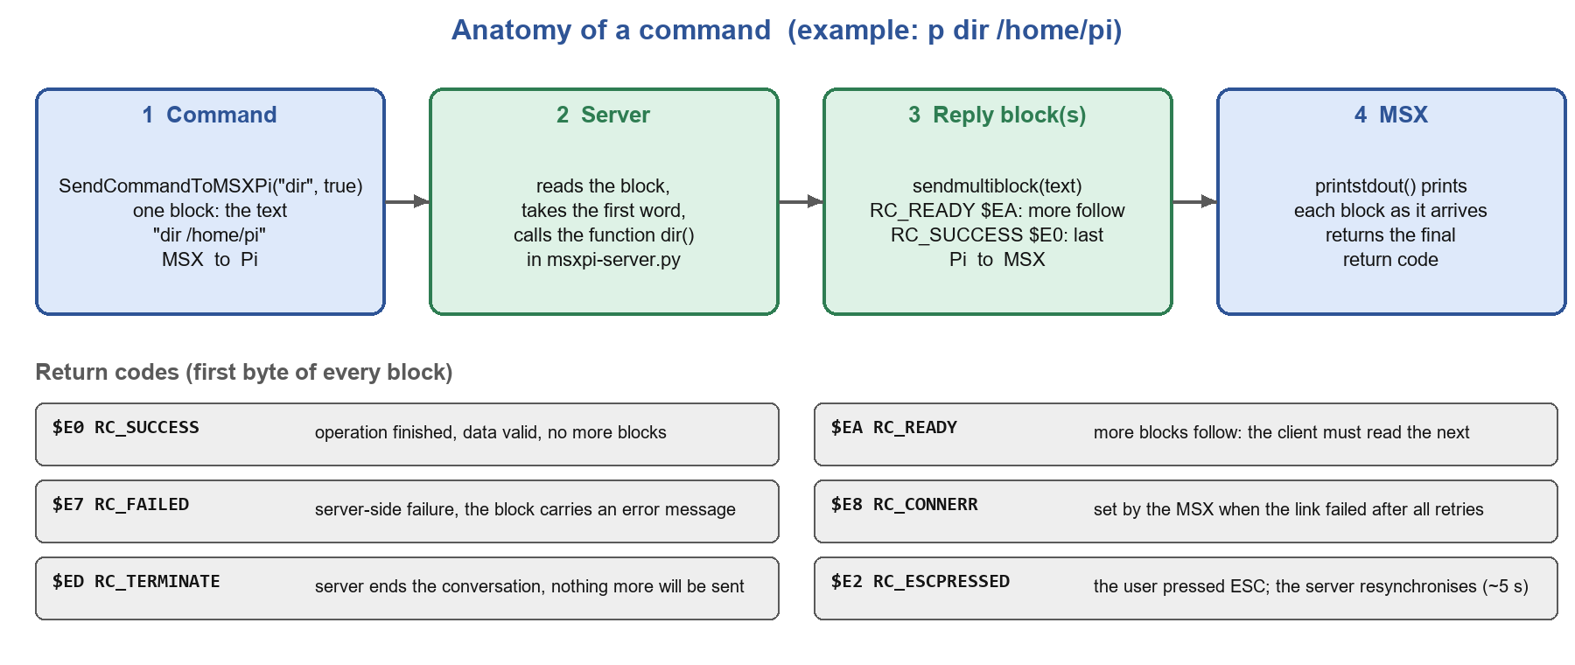
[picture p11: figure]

Figure 4: Life of a command, and the return codes

Every reply block starts with a return code. The MSX must read blocks until it sees a code other than RC_READY; a client that stops early leaves the server waiting to send, and both sides then need the CTRL+ESC recovery. The full table of codes is in Appendix A.

Most commands follow one of four shapes; the block protocol is the same in all of them:

1. Command, wait for the reply, print it - by far the most common: p dir, p ver, p run. This is what CALL MSXPI, printstdout() and PRINTPISTDOUT implement.
2. Command only, no reply needed (rare).
3. Command plus extra parameter blocks, then a reply - for example p set with a long value.
4. A conversation: several commands or blocks in both directions while the server keeps the state. pcopy (init, readblock, writeblock, putclose), msxarch (list, select, header, image blocks) and the disk driver (DSKIO reads and writes) work this way. IRC.BAS keeps its state on the server between separate CALL MSXPI calls.

## Server internals

- Main loop. Waits for a command block, splits it, looks up COMMANDS[cmd.lower()] (an explicit table in msxpi-server.py - only the functions listed there can be called from the MSX) and calls it with the parameter string. If the function returns a string or bytes, the loop sends it as the reply; unknown commands answer "Unknown command"; an exception answers "Pi:Error - ..." and keeps the server alive.
- Transport. On a Raspberry Pi the bytes travel over GPIO (pins CS, SCLK, MOSI, MISO, RPI_READY, set in msxpi.ini). A native C engine (native/libmsxpi_gpio.so, enabled with MSXPI_NATIVE_GPIO=1 and on by default in msxpi-monitor and the systemd unit) clocks the payload; without it the server falls back to Python GPIO and says so in its log. Under openMSX the same routines read and write a TCP socket instead (port 5000, TCP_NODELAY).
- Configuration. msxpi.ini in the MSXPi home directory is read at start-up and rewritten by p set. Paths default to /home/pi/msxpi, which is hard-coded; on Windows it resolves on the current drive (C:\home\pi\msxpi).
- Disk images. DriveA and DriveB point at .dsk files that the server memory-maps, so writes from the MSX persist. p reload A: re-opens an image after it was replaced.
- Ethernet shuttle (msxpi_eth.py): carries UNAPI Ethernet frames between the MSX link and a TAP device (section 2.7).
- Service. On the Pi, msxpi-monitor (a systemd unit) starts, monitors and restarts the server, and runs the TCP/IP setup script in the background.

## Disk access

The ROM contains MSX-DOS 1 only (the 1.03 kernel and its disk driver); Nextor and MSX-DOS 2 are not part of MSXPi and must come from another disk interface. The driver is written so that it also works when Nextor is the system in charge. Drives A: and B: of the MSXPi map to the disk images named by DriveA and DriveB in msxpi.ini (by default msxpiboot.dsk and tools.dsk). Each sector is requested from the server (dskior, dskiow) and moved by /WAIT bursts when both sides negotiated them.

The driver transfers directly to the caller's buffer when that is outside page 1, and through the kernel's XFER routine when it is in page 1, because page 1 is where the driver ROM itself is banked in. A drive mapped with MAPDRV under Nextor (running from the other interface) works the same way; GETDPB clears carry explicitly, which is what Nextor needs to accept the DPB. At the time of writing, disk reads use bursts and writes use the polled path.

## The Ethernet UNAPI

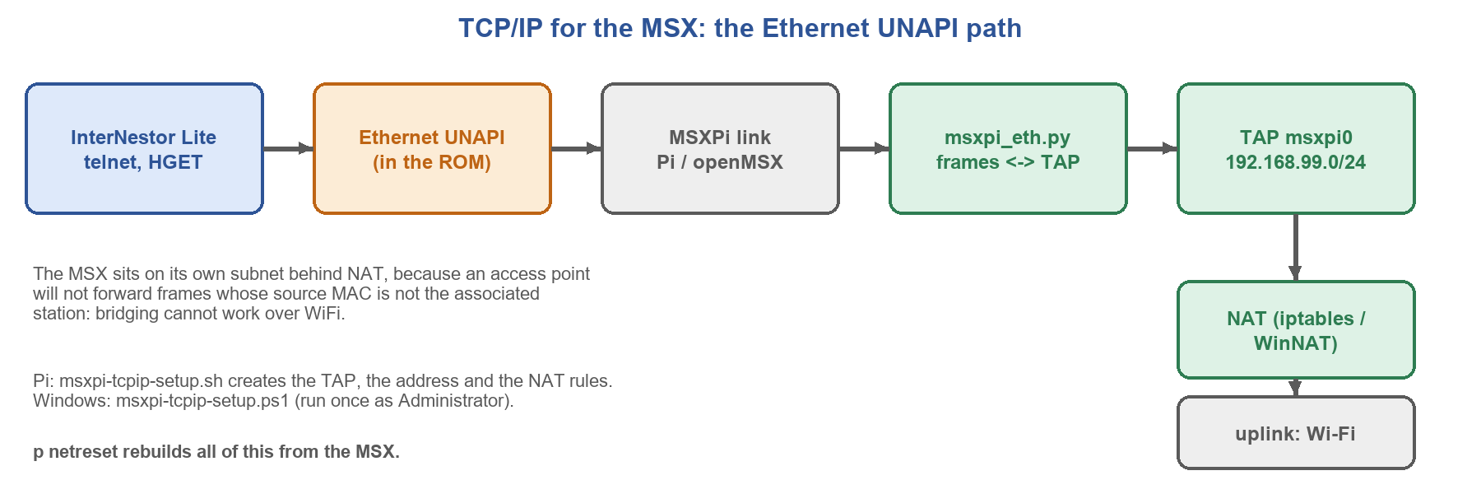
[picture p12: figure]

Figure 5: From an UNAPI program to the internet

The ROM registers an ETHERNET UNAPI implementation, so programs such as InterNestor Lite (INL) need no extra driver: ETHUNAPI.COM refuses to load because the implementation already exists, and RAMHELPR must not be run. Frames travel over the same MSXPi link (using the same /WAIT burst code as the disk driver), and a shared-link guard (msxpi_link_claim / msxpi_link_release) prevents the UNAPI interrupt routine from transmitting in the middle of a command exchange.

On the Pi, msxpi-tcpip-setup.sh creates the TAP device msxpi0, gives it the address 192.168.99.1/24, enables forwarding and installs the NAT rules for whichever interface carries the default route. The MSX is placed on its own subnet behind NAT because WiFi access points do not forward frames whose source MAC is not the associated station, so bridging cannot work. Under openMSX on Windows the same driver reaches a real network through an OpenVPN TAP-Windows adapter, and msxpi-tcpip-setup.ps1 (run once, as Administrator) configures the address and a WinNAT instance. If the TAP is not ready when the first UNAPI call arrives, the server retries and swaps it in later; if it never appears the server falls back to "MockLink", which answers every call but carries no traffic.

## Loading ROMs from the network

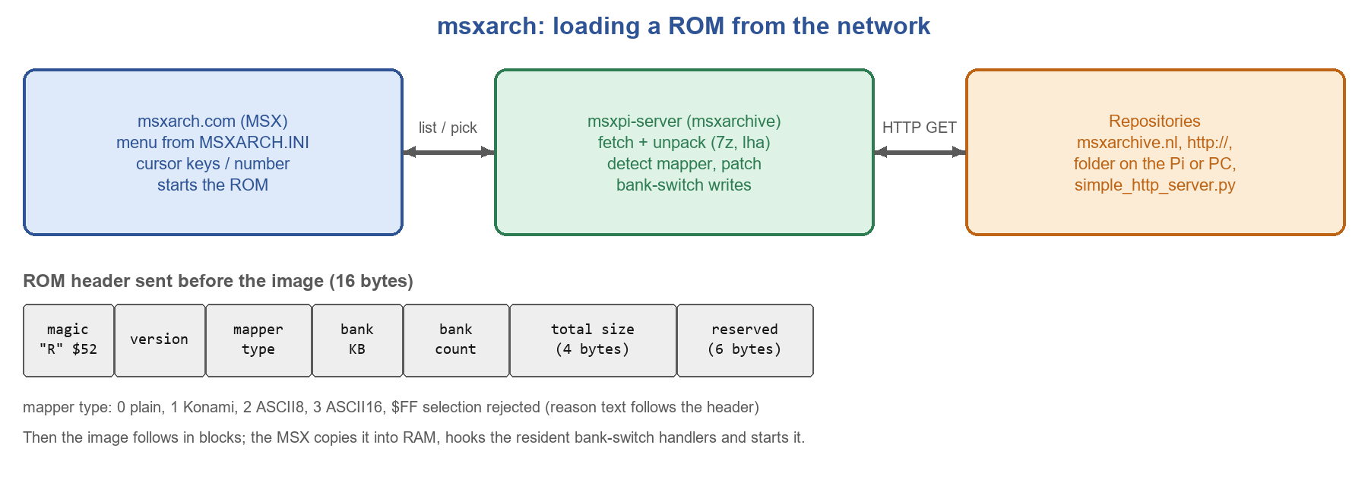
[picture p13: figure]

Figure 6: msxarch and the ROM header

msxarch shows a list of ROMs found in the repositories listed in MSXARCH.INI and starts the one you choose. The server downloads and unpacks the archive (into a clean directory, so ROMs from different downloads never mix), classifies the ROM - plain, Konami, Konami SCC, ASCII8 or ASCII16, using openMSX's softwaredb.xml when available - patches the bank-switch writes to work with the resident handlers, and sends a 16-byte ROM header followed by the image. If the selection cannot be loaded, the header carries mapper type $FF and a reason text, and the MSX shows it and returns to the list. LOADROM.COM (a binary patch of the third-party LOADROM 1.97) does the same for a file name given on the command line: LOADROM name.rom /N.

# Getting Started

MSXPi can be used with or without the EEPROM installed. The most practical setup is to use it together with another interface that runs Nextor or MSX-DOS 2 (for example a MegaFlashROM SCC+ SD), with MSXPi providing the Raspberry Pi control and the network. MSXPi itself has only MSX-DOS 1 built into its ROM: it coexists with Nextor and MSX-DOS 2 but does not provide them. Booting MSX-DOS 1 from a disk image on the Pi is also possible but slower.

Throughout this guide, "P commands" are the programs in software/target (p.com, pcopy.com, pver.com, msxarch.com, LOADROM.COM, at28c256.com, ...). Copy them to your MSX disk or SD card first.

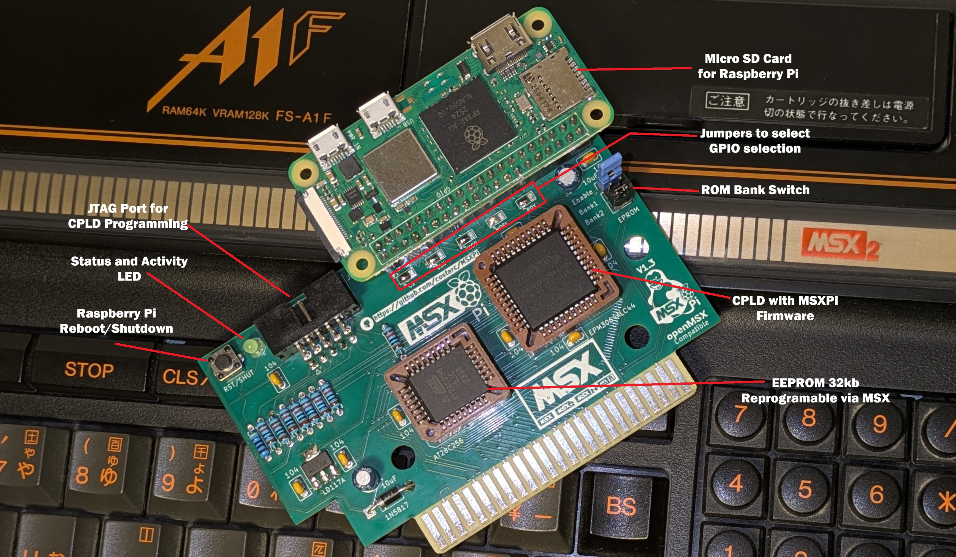
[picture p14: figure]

Figure 7: The main components of the MSXPi interface

- Raspberry Pi Zero (2) W - boots Linux and runs msxpi-server.py.
- Micro SD card - holds the Pi's system and the MSXPi home directory.
- EEPROM AT28C256 - the MSXPi ROM. It is written from MSX-DOS with at28c256.com.
- Jumpers - enable/disable the ROM (SLTSL) and select the 16 KB bank (A14/A15).
- CPLD - decodes the ports and shifts the data. Programmed over the JTAG connector with a USB-Blaster and Quartus on a PC, with the MSX switched on.
- Activity LED - lights when the Pi's server is running.
- Push button - a short press reboots the Pi; holding it for more than three seconds shuts it down.

## Assembling the interface

Assembly order and the CPLD programming steps are in documents/MSXPi Assembly Instructions.txt; in short: solder the voltage regulator, the SMD jumpers CS, CLK, MISO, MOSI and RDY, the resistors, the sockets (CPLD, EEPROM, Pi header, JTAG), the capacitors and the remaining parts. Use a socket for the EEPROM so you can replace it later.

The Raspberry Pi's 40-pin header must be on the side that matches your PCB. The Pi is always plugged in with its component side facing you. A Zero WH has the header soldered on the front and cannot be used on a PCB whose socket is on the front; use a Zero or Zero W and solder a 2x20 header on the back, as shown below.

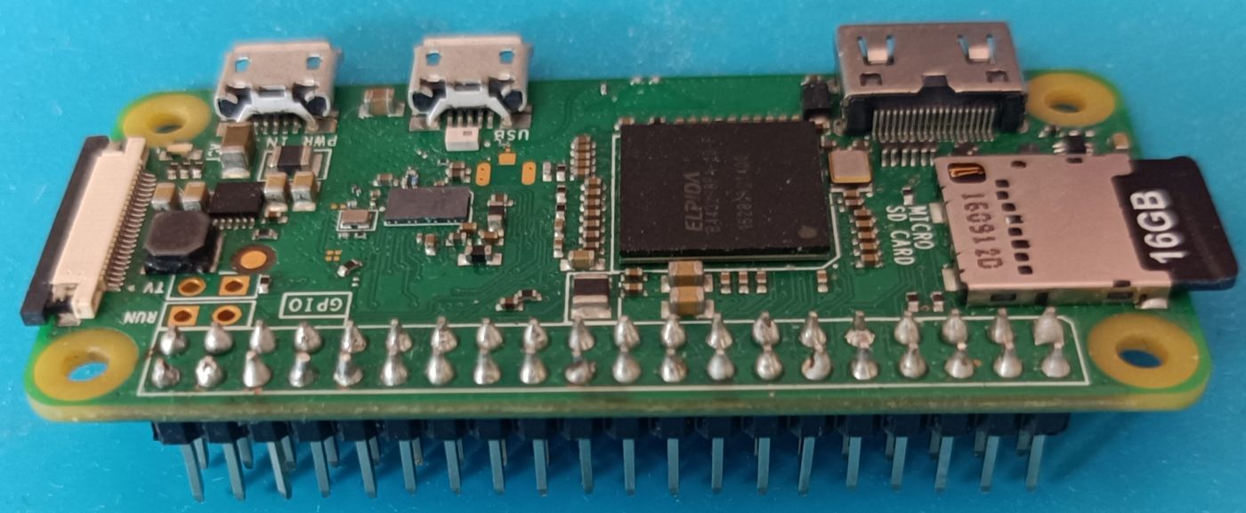
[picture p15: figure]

Figure 8: Soldering the header - top view

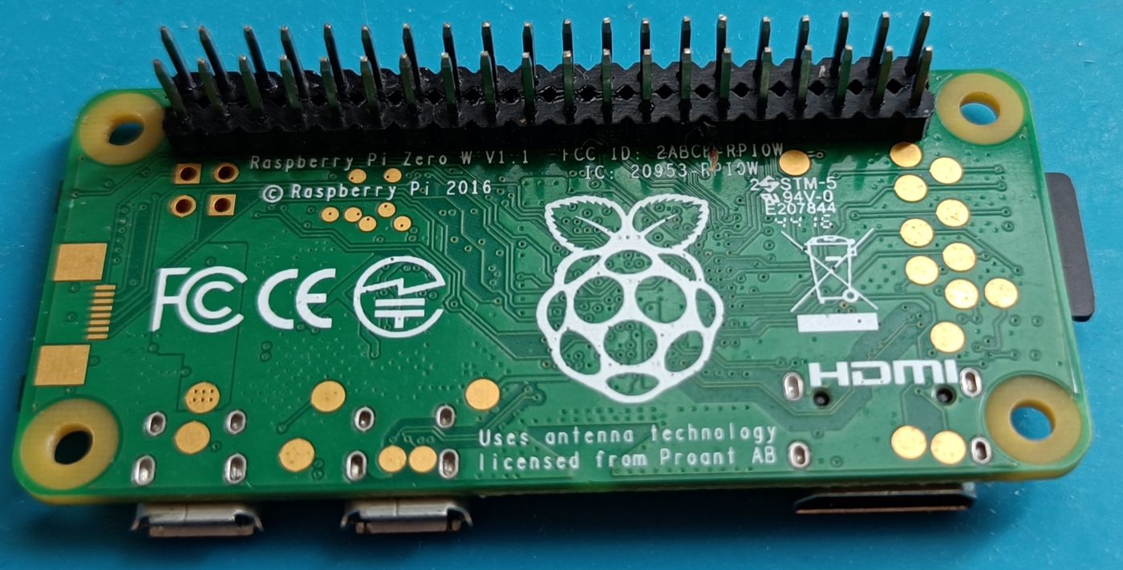
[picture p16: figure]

Figure 9: Soldering the header - bottom view

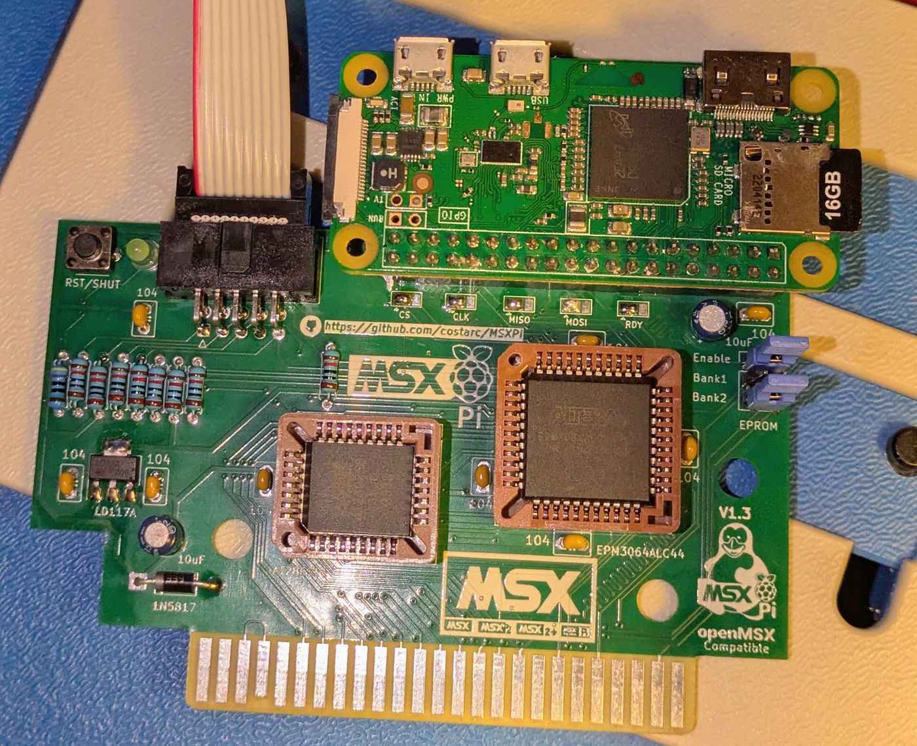
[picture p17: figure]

Figure 10: MSXPi assembled - top view

## Programming the CPLD

Connect a USB-Blaster to the JTAG connector and to the PC, insert the interface in the MSX and switch it on. In Quartus 13.0 SP1: Tools, Programmer, mode JTAG, Hardware Setup shows the USB-Blaster; Add File; tick Program/Configure and Verify; Start. Choose the .pof for your board:

Board | File in hardware/CPLD_Project | Build ID
V1.3 Rev.1 (and boards for v1.3 to v1.5) | MSXPi_v1.6.pof | $0E
V1.1 Rev.1, V1.2.1b | v1.1/MSXPi_v1.6_wait.pof | $14
v0.8.2 / v1.0 (PCB v0.7 Rev.7) | v0.8.2/MSXPi_v1.6_polled.pof | $10

Check with PRINT INP(&H57) in BASIC (not 254/255) or with pver. Older boards need extra settings in msxpi.ini and, for the v0.8.2 board, a specific EPROM jumper setting: see hardware/CPLD_Project/LEGACY_BOARDS.md and documents/Legacy Support.odt.

## Writing the ROM to the EEPROM

1. Copy at28c256.com and msxpibios.rom (from software/target) to a disk of an MSX that has the interface plugged in.
2. If the interface already holds a bootable ROM, remove the enable jumper (SLTSL, or CS12 on older boards) first.
3. List the slots and ROMs: at28c256 /i. Note the slot number of the interface.
4. Write: at28c256 /s 2 msxpibios.rom (2 is the slot). The tool write-protects the EEPROM when it finishes. Add /r to write slowly if the chip fails.
5. Power off, set the jumpers (below) and power on. CALL MSXPIVER in BASIC prints the ROM version.

The EEPROM has 32 KB. Two 16 KB ROMs can live in it and be selected with the A14/A15 bank jumper (merge them into one 32 KB file first). The ROM is 16 KB, one bank.

## Preparing the SD card for the Raspberry Pi

1. Write "Raspberry Pi OS Lite (32-bit)" with Raspberry Pi Imager (CHOOSE OS, Raspberry Pi OS (other), Raspberry Pi OS LITE). In its settings use the user name pi, enable SSH and enter your WiFi.
2. Boot the Pi and log in (SSH, or keyboard and HDMI).
3. Run the setup script: wget https://tinyurl.com/MSXPi-Setup, chmod 755 MSXPi-Setup, bash ./MSXPi-Setup. It installs the Python modules and packages, creates the MSXPi home directory, downloads the server, ini templates and disk images, builds the native GPIO engine, installs the msxpi-monitor service and reboots - a few minutes. It asks which board you have (or pass --board v1.3, v1.1 or old); --help lists the other options. It is safe to run again and never overwrites msxpi.ini. Insert the card in the Pi and plug it into the interface.

The Hard Way tutorial in the documents folder (English and Portuguese) shows the Raspberry Pi OS installation with pictures; the setup script replaces its manual steps. A ready-made SD card image is no longer offered.

## The MSXPi home directory and msxpi.ini

Everything the server needs is in one folder, /home/pi/msxpi (on Windows, C:\home\pi\msxpi). The path is built into the server; the environment variable MSXPI_HOME overrides it:

Item | Purpose
msxpi-server.py, msxpi_*.py (msxpi_cmd_*.py, msxpi_transport.py, msxpi_settings.py, msxpi_eth.py, msxpi_gpio_native.py, ...), mapper_detect.py | The server and its modules
native/libmsxpi_gpio.so | Native GPIO engine, built on the Pi by native/build.sh
msxpi.ini | Your configuration (Appendix B lists every variable)
disks/msxpiboot.dsk, disks/tools.dsk | Drives A: and B: for the MSX-DOS 1 boot mode
msxpi-monitor, msxpi-tcpip-setup.sh, update.sh | Service wrapper, network setup and updater

Create msxpi.ini from the template that matches your PCB (msxpi-JumperLeft.ini, msxpi-JumperRight.ini or msxpi-JumperRight_PCBV1.1Rev.0.ini in software/Server/Python/src). Boards without the shutdown push-button must add var RPI_SHUTDOWN=none. Change values from the MSX with p set NAME value.

## Client software on the MSX

Copy the files from software/target to your MSX disk or SD card: p.com, pcopy.com, pver.com, msxarch.com, msxarch.ini, LOADROM.COM, at28c256.com, INL.CFG, the telnet clients and the BASIC programs (API.BAS, IRC.BAS, WEATHER.BAS, DOLAR.BAS, STOCKS.BAS). The updater msxpiupd.bat does this over the network. Then type pver: it prints the board, the CPLD build and whether /WAIT is available, followed by the server version.

## Booting with MSXPi

### Booting from another interface with Nextor or MSX-DOS 2 (recommended; MSXPi provides no Nextor of its own)

1. Remove the SLTSL (enable) jumper if you do not need the MSXPi ROM, or put MSXPi in a higher slot than the disk interface.
2. Plug MSXPi in with the prepared SD card in the Pi and switch the MSX on. The MSX boots from the disk interface at full speed; the Pi finishes booting in the background.
3. Check with pver. If the MSX seems unresponsive, press CTRL+ESC, wait five seconds and try again.

### Booting MSX-DOS 1 from the MSXPi ROM

1. Make sure the EEPROM holds the current msxpibios.rom.
2. Close the SLTSL jumper and select the bank that holds the MSXPi ROM.
3. Switch on and wait until the MSX-DOS 1.03 banner appears. The Pi must complete its boot first, so the first cold boot takes a few minutes.
4. Drives A: and B: are the disk images of DriveA and DriveB. Do not delete files from drive A: in this mode.

Hold ESC during boot to skip the MSXPi boot and go to BASIC.

## MSXPi under openMSX

The steps are in the README ("Quick Start 2"). In short: download openMSX from the MSXPi fork releases (https://github.com/costarc/openMSX/releases; the upstream project is https://github.com/openMSX/openMSX), install Python 3 with requests, fs and "setuptools<81", and 7-Zip, create the MSXPi home directory with msxpi-server.py, mapper_detect.py and every msxpi_*.py module, start python msxpi-server.py, then openmsx -machine Panasonic_FS-A1WSX -ext MSXPi -diska FloppyA. On Windows msxpi-windows-setup.ps1 does all of it. The optional openMSX setting msxpiserver_port (default 5000) changes the TCP port; start the server with the environment variable MSXPI_PORT set to the same value. Appendix D compares the openMSX device with the CPLD.

# Users Guide

MSXPi can be used as a network and Raspberry Pi companion that coexists with a Nextor or MSX-DOS 2 system provided by another interface (the recommended way; MSXPi's own ROM has only MSX-DOS 1), or as a stand-alone floppy drive that boots MSX-DOS 1.03 from a disk image on the Pi. In both cases the p commands work the same, under MSX-DOS 1, MSX-DOS 2 and Nextor, and CALL MSXPI works in BASIC however the machine was booted.

## Getting around

- CTRL+ESC interrupts a running command. The server then abandons the operation and re-enters command mode; wait about five seconds before the next command.
- pver (or p ver) tells you if MSXPi is alive. From BASIC, CALL MSXPIVER shows the ROM version and CALL MSXPI("1,C000,ver") asks the server.
- Always run `p shut` before switching the MSX off. The Pi is powered by the MSX; a sudden power cut can corrupt its SD card.
- A short press of the push button reboots the Pi; holding it for more than three seconds shuts it down.
- Type p (or p /help) to list the commands, and p /m to see the memory the command can use.

## The p commands

p.com is one program that sends its command line to the server: p dir /home/pi sends the text "dir /home/pi". Any function of the server can therefore be called from the MSX. The built-in help lists these:

Command | Description
p ver | Server version and build
p cd, p dir | Set the current path and list it
p run <command> | Run a command on the Pi
p date | Set the MSX date and time from the Pi
p set | Show or change MSXPi variables
p wifi | Show interfaces and configure WiFi
p wlanreset [secs] | Reset wlan0 and wait for an address
p netreset [secs] (p tcpip) | Rebuild the Pi's TCP/IP setup for the UNAPI
p vol, p play | Volume and audio playback on the Pi
p reload A: | B: | Reload a drive's disk image
p reboot, p shut, p restart | Reboot the Pi, shut it down, restart the server
p chatgpt <text> | Ask ChatGPT

Besides p, these programs come with MSXPi: pver, pcopy, msxarch, LOADROM, at28c256, msxpiupd.bat, the BASIC programs and the UNAPI tools. They are described one by one in the sections below.

### pver

Reports the hardware and the server. Every line fits 29 columns, the width of MSX-DOS 1 in SCREEN 1:

A>pver

Port $57: $0E

Build ID: $0E

Board : v1.3 to v1.6

CPLD : v1.6 /WAIT build

/WAIT : yes (burst)

MSXPi Server Version 1.6 Build 20260919.060

/WAIT: no (polled) means the CPLD firmware or the emulator has no /WAIT mode and the slower polled transfers are used. "Board: no MSXPi found" means no CPLD answered on port $57. "Server: connection error" means the interface is present but the Pi is not answering (still booting, server stopped, or mismatched versions).

### p cd and p dir

p cd sets the path used by p dir and pcopy; alone it displays it. A path can be on the Pi, a network URL (http, https, ftp, smb) or one of the virtual drives kept in msxpi.ini:

Drive | Default | Meaning
m: | ftp://192.168.1.100 | Your local network server
r1: | msxarchive.nl MSX1 ROMs | Internet location
r2: | msxarchive.nl MSX2 ROMs | Internet location

p cd

p cd /home/pi

p cd r1:

p dir

p dir /home/pi/msxpi

p dir http://www.msxarchive.nl/pub/msx

### pcopy

Copies files between the Pi (or the network) and the MSX drive, in either direction:

pcopy <pi file> [drive:][target] Pi -> MSX

pcopy <drive>:<file> <pi file> MSX -> Pi

pcopy /z r1:frogger.zip download, unpack, save the ROM

Examples: pcopy /home/pi/msxpi/msxpi.ini msxpi.ini, pcopy m:pver.com, pcopy b:report.txt /home/pi/report.txt. With /z the file is unpacked (zip, lzh, pma, 7z and others) and the unpacked file is saved. Large files move in 16 KB blocks; a damaged block is retried, a failed upload never destroys the target file, and copying to a drive whose image is on the Pi is done on the Pi side.

### p run

Runs a command on the Pi and prints its output. Commands that ask for input are not supported. Replace a pipe with :::

p run ls -l /etc

p run cat /home/pi/msxpi/msxpi.ini

p run ps -ef :: grep msx

p run wget http://www.msxarchive.nl/pub/msx/games/roms/msx1/frogger.zip

### p set

Shows or changes the variables kept in /home/pi/msxpi/msxpi.ini (see Appendix B). When a disk image variable changes, the new image is loaded at once.

p set

p set WIFISSID My Wifi Name

p set WIFIPWD MyWifiPass

p set OPENAIKEY sk-...

p set DriveB /home/pi/msxpi/disks/other.dsk

Note: Do not change DriveA unless you know what you are doing: it holds the MSX-DOS 1 boot disk, and a wrong value can lock you out of the DOS until you edit msxpi.ini by hand.

### p date

Sets the MSX-DOS date and time from the Pi. It takes no parameters. Put it in AUTOEXEC.BAT.

### p wifi, p wlanreset, p netreset

p wifi lists every network interface with its state and address, one line per address (40 columns). p wifi set configures the WiFi from the WIFISSID, WIFIPWD and WIFICOUNTRY variables; reboot the Pi afterwards (p reboot).

p wlanreset [secs] resets wlan0 without a reboot: it drops the lease, cycles the radio, asks NetworkManager, dhcpcd or dhclient (whichever owns the interface) to reconnect, and waits for a fresh IPv4 address (30 s by default, 5 to 90).

p netreset [secs] (alias p tcpip) rebuilds the whole TCP/IP setup for the MSX: it tears down the TAP device and the NAT rules, runs msxpi-tcpip-setup.sh again and reopens the link. Use it when the Pi had no default route at boot, so the MSX has no network. The optional argument is the time to wait for a default route (15 s by default, at most 60). Run it after p wlanreset if the uplink address changed.

### p play and p vol

Play audio on the Pi (Raspberry Pi only). A unique id is printed when a file starts; use it with pause, resume and stop.

p play play Aleste.mp3

1465

p play pause 1465

p play resume 1465

p play stop 1465

p play loop Aleste.mp3

p play getids

p play getlids

p vol 80%

### p reload, p reboot, p shut, p restart

p reload A: (or B:) re-opens the disk image after you replaced it on the Pi. p reboot reboots the Pi, p shut shuts it down cleanly, and p restart restarts only the msxpi-server.

### p chatgpt

Asks ChatGPT and prints the answer. It needs an OpenAI key (p set OPENAIKEY ...); the model comes from OPENAIMODEL (default gpt-4o-mini).

p chatgpt Write a short BASIC program that draws a circle in SCREEN 2

### p showpage

p showpage [/4|/6|/8] <url> renders a web page on the MSX screen. The page is rendered on the Pi and sent as an image; /4, /6 and /8 pick SCREEN 4, 6 or 8 (MSX2).

### p music

p music plays audio files on the Pi (Raspberry Pi only), like p play; p vol sets the volume.

### pchess

pchess.com is a chess game for any MSX2 (SCREEN 5, 64 KB VRAM is enough); pchess1.com is the MSX1 version. By default the MSXPi server validates every move with the optional Python package chess (pip install -r requirements-pchess.txt) and runs the Stockfish AI. Modes: two players on one MSX, against the AI, in a room (an HTTP relay on the local network, or an IRC channel with PCHESSROOMS=irc) and online over IRC (#msxpi). LINK in the ESC menu switches to a TCP/IP UNAPI stack instead (MSR I or RAMHELPR I, then INL I): the MSX then checks the rules itself and plays local, room and online games without the MSXPi server, configured by PCHESS.INI. See the PChess Users Manual, software/Client/src/PCHESS.md and documents/PCHESS-IRC.md.

## msxarch - the network ROM browser

msxarch lists ROMs from one or more repositories and starts the one you pick. It works under MSX-DOS 1, MSX-DOS 2 and Nextor and supports plain ROMs and MegaROMs (Konami, Konami SCC, ASCII8, ASCII16).

The repositories are read from MSXARCH.INI, one per line. Lines starting with ; or # are comments:

; msxarch.ini

rebootAfterRomLoad=yes

https://www.msxarchive.nl/pub/msx/games/roms/msx1

https://www.msxarchive.nl/pub/msx/games/roms/msx2

http://localhost:8000

/home/pi/msxpi/gameroms

An entry can be an http or https listing (a web server, or simple_http_server.py from software/Server/Python/src to publish a folder of your PC), or a folder on the Pi (or on the PC running openMSX). Pick a repository from the menu, then in the game list use N or cursor down for the next page, P or cursor up for the previous page, type a game number and press Enter to load it (Backspace edits the number), and Q to quit. The list shows the size of each file, and a progress display shows the loading. Archives are unpacked on the Pi. If a ROM cannot be loaded, the reason is shown and you return to the list.

rebootAfterRomLoad=yes resets the MSX after loading so that the game starts on a clean machine. msxarch needs free RAM (a MegaROM is held in mapped RAM segments), so run it from a clean boot.

## LOADROM

LOADROM.COM is a binary patch of the third-party LOADROM 1.97 (by Victor Martinez and Trunks) with MSXPi network loading added. Without /N it behaves exactly like the original and loads from disk; with /N the file name is resolved by the server:

LOADROM USAS.ROM /N

See software/Client/src/loadrom/README.md for how the patch works and why.

## at28c256 - writing the EEPROM

Writes a ROM file to the interface EEPROM (8, 16 or 32 KB) from MSX-DOS. See section 3.3 for the whole procedure.

at28c256 /i list identified ROMs and slots

at28c256 /s 2 msxpibios.rom write to the interface in slot 2

at28c256 /s 2 /r msxpibios.rom same, writing slowly

## Updating MSXPi

Updating over the network is risky: keep a keyboard and a monitor at hand, or SSH access to the Pi, in case an update fails.

1. MSX side: run msxpiupd.bat (needs a working network). It refreshes itself, sets the date, and copies every .COM, the BASIC programs and the disk images from the repository. On MSX-DOS 1 the ECHO lines print harmless errors. If you have a very old updater, replace it first: pcopy https://github.com/costarc/MSXPi/raw/master/software/target/msxpiupd.bat.
2. Server side: from the MSX, p run wget https://tinyurl.com/MSXPi-Setup, p run chmod 755 MSXPi-Setup, p run sudo ./MSXPi-Setup. The MSX prompt stays locked (up to five minutes) until the Pi reboots. Check with pver.
3. ROM: the updater downloads the new msxpibios.rom but never writes it. Write it with at28c256 (section 3.3).
4. CPLD: a new firmware (.pof) has to be programmed from a PC (section 3.2).

## TCP/IP with InterNestor Lite

With the Ethernet UNAPI in the ROM, no driver has to be installed. Make sure the Pi has a network (p wifi), then:

MSR I (MSX-DOS 1 only)

INL I

HOST GOOGLE.COM

TELNET some.host

- Do not run RAMHELPR I: it installs the UNAPI RAM helper on its own and MSR then finds a helper already present and aborts, leaving INL to fail with "No mapper support routines found". A cold boot clears it. Under Nextor or MSX-DOS 2 skip MSR entirely; the mapper routines are already there.
- ETHUNAPI refuses to install because the ROM already registers an ETHERNET implementation.
- If HOST says "8: DNS not found" the resolver is the problem, not the link. INL.CFG ships with 1.1.1.1; some networks block public resolvers. Use INL IP P <address> with the resolver the Pi reports (p netreset prints it).
- If the network never comes up, run p netreset. The utilities ETHTEST, ETHMODE, ETHBENCH and UCOUNT in software/UNAPI/bin test and measure the link.

## BASIC programs

Program | What it does
API.BAS | Template and examples for developers (section 6)
IRC.BAS | IRC client: nick and server from IRCNICK, IRCADDR, IRCPORT
WEATHER.BAS, DOLAR.BAS | Weather and exchange-rate clients (from Retropix Brazil)
STOCKS.BAS | Stock quotes; needs the API keys in msxpi.ini
TESTDIR.BAS | Directory listing test

When CALL MSXPIVER is not available (no ROM in the interface), the programs BLOAD"MSXPIEXT.BIN",R first. This loads the BASIC extension into page-1 RAM and adds CALL MSXPIVER and CALL MSXPI.

## Dealing with errors and instabilities

Because the interface, the Pi and the MSX are all involved, MSXPi may fail. Electrical noise and bus quality vary between MSX models; the interface is very stable on clones such as the Zemmix and on machines with recent SoC chips, and can be less stable on older machines. The transfer routines detect errors and retry on their own, but sometimes a transfer fails and the recovery mode starts.

### Recovery with CTRL+ESC

Hold CTRL and press ESC to abort an operation or to get the prompt back. ESC alone is passed to the program as an ordinary key. The server stops the transfer and returns to command mode; this takes up to five seconds, so wait before retrying. If the result is "Connection Error" again after a retry, the Pi needs inspection: log in over SSH or with a keyboard and monitor and run the server by hand (cd /home/pi/msxpi && python3 msxpi-server.py) to read its messages.

### Checking what is alive

1. pver (DOS) or CALL MSXPIVER (BASIC) - is the ROM present?
2. CALL MSXPI("1,C000,ver") or pver - does the server answer? A "Build ID" line and a "Server" line mean both ends work.
3. The interface LED on: the server is running.
4. A mismatch between the ROM, server and .COM versions is the most common cause of "Connection Error" after an update.

### Failed MSX-DOS 1 boot with a working MSXPi

If pver works but MSX-DOS 1 will not boot from the disk image, the image may be corrupt. Options, in order:

- Press the MSX RESET button if there is one: the Pi keeps running and the boot may succeed.
- Without a reset button, from BASIC: DEFUSR0=0 : A=USR(0).
- Test the DOS with FILES, then with POKE &HF346,1 and FILES, and finally POKE -1,170 and FILES.
- As a last resort switch the MSX off and on. Replace msxpiboot.dsk (the updater msxpiupd.bat does it when you boot from another interface).

### Failed boot with a failing MSXPi

Log in to the Pi over SSH and run the server by hand to read its messages. If the disk image was corrupted by repeated power cuts, copy a fresh one from a PC:

scp msxpiboot.dsk pi@raspberrypi:msxpi/disks/

The best prevention is p shut before every power-off.

### Older boards

Boards built for v0.8.2 and v1.0 have no /WAIT connection and run polled only; RPI_SHUTDOWN=none (no push-button) and, on the v0.8.2 board, GPIO_CS_SETUP_NS=1000 are required, and the EPROM /OE jumper must be on CS1, never CS12. All of it is in documents/Legacy Support.odt.

# Developers Guide

MSXPi programs have two halves: a client on the MSX (in BASIC, C or Assembly) and, when new functionality is needed, a Python function on the server. The block protocol of section 2.3 is hidden by the BIOS routines of each language, so a client is normally: send a command, receive and use the reply.

## The programming model

1. The client sends a command (a text of up to BLKSIZE bytes). The first word is the name of a Python function in msxpi-server.py; everything after it is the parameter string.
2. The server function does its work and answers with sendmultiblock(data). Large data is split into blocks automatically: the return code is RC_READY on all but the last block.
3. The client reads blocks until a return code other than RC_READY arrives. RC_SUCCESS means done; RC_FAILED means the block holds an error message; RC_TERMINATE ends the conversation.
4. For conversations (upload, paging, state) the client calls the same server function several times with sub-commands, as pcopy does.

## Adding a command to the server

The template in the server is the whole recipe. The first word of the command is looked up in the COMMANDS table at the top of msxpi-server.py, so the function name is the command name (in lower case) and a new function must be added to that table. A function that returns a str or bytes has its return value sent as the reply:

def template(parms = None):

# If your MSX command send parameters, we go read them:

if parms == None or parms == "":

rc = sendmultiblock("This command requires a parameter".encode())

return

response = f"Response from MSXPi: I received parameter '{parms}'"

rc = sendmultiblock(response.encode())

return

To create hello, copy the template, rename it hello, add hello to COMMANDS in msxpi-server.py, restart the server (p restart) and call it from any client: p hello world, CALL MSXPI("1,C000,hello world"), or a client of your own. Guidelines:

- Always reply, even on error - a client waits for the reply. Use sendmultiblock(msg.encode()); for a failure use sendmultiblock(msg.encode(), RC_FAILED).
- Keep the command name to letters; it is lower-cased. set is mapped to pset because set is a Linux command.
- Long-running functions may read more from the MSX (see how the pcopy and disk functions in msxpi_cmd_files.py and msxpi_cmd_disk.py receive blocks) and send further blocks; the MSX must do the mirror image.
- Read settings with getMSXPiVar("NAME") and store them with p set, so they survive in msxpi.ini.
- Anything that only makes sense on a Raspberry Pi should check hostType == "RaspberryPi" and answer "Command not supported by this platform" otherwise, as play does.

## Tools and build

- C clients are compiled with SDCC and the Fusion-C headers, linked against C-common/lib/msxpi-bios.lib, with a custom MSX-DOS start-up file.
- Assembly clients and the ROM are assembled with zmac / sjasmplus (see the header of software/build); the transfer routines in asm-common/transport/payload.z80 are generated for the different consumers by generate.py.
- `software/build` builds the client commands, the ROM, the LOADROM patch, the openMSX extension and the disk images, and bumps the BuildId of each component when asked.
- BASIC needs nothing but the ROM (or MSXPIEXT.BIN).

## Testing under openMSX

Develop and test with the MSXPi extension of openMSX: the emulated device implements the CPLD including /WAIT bursts (with fault injection for a low RPI_READY), the server runs on your PC, and its console shows every command received (-> dir /home/pi). What works there works on the hardware. Server unit tests are in software/Server/Python/tests; the UNAPI test harness (openMSX driven) is in software/UNAPI/harness.

# Developing in BASIC

BASIC programs talk to MSXPi with one statement, CALL MSXPI, provided by the ROM or by MSXPIEXT.BIN. (The old CALL MSXPISEND and CALL MSXPIRECV no longer exist; everything is done with commands and replies.) CALL MSXPIVER prints the BIOS version and is the way to test that the BIOS is present.

## CALL MSXPI

CALL MSXPI("<stdout>,<buffer>,<command> <parameters>")

Part | Meaning
stdout | 0: discard the reply. 1: print the reply on the screen. 2: store the reply in memory, do not print.
buffer | Four hex digits, for example C000. Where the reply is stored (mode 2), and where the return code is left.
command | Name of the server function, with its parameters, exactly as in p <command>.

CALL MSXPI("0,C000,set") ' run, ignore the reply

CALL MSXPI("1,C000,dir /home/pi/msxpi") ' print the listing

CALL MSXPI("2,D000,dir /etc") ' store the listing at D000

In mode 2 all blocks of the reply are stored one after the other after a three-byte header:

Address | Content
buffer + 0 | Return code of the last block (see Appendix A): &HE0 success, &HE7 failed, &HE8 connection error
buffer + 1, + 2 | Total size of the data, low byte then high byte
buffer + 3 ... | The data (a text reply is plain ASCII)

SIZE = PEEK(&HD001) + 256 * PEEK(&HD002)

RC = PEEK(&HD000)

FOR I = 0 TO SIZE - 1 : PRINT CHR$(PEEK(&HD003 + I)); : NEXT

Buffer safety: The buffer must hold the whole reply plus three bytes, and MSXPi does not check: a larger reply overwrites memory above the buffer. Lower the top of BASIC memory first, as API.BAS does with CLEAR 200,(PEEK(&HFC4A)+256*PEEK(&HFC4B))-520, and choose a buffer address inside the area you reserved. For replies of unknown size use mode 1, or read the reply block by block with the API routines below.

If the link fails, the return code in the buffer is &HE8 (connection error) and the size is zero, so a program can always test PEEK(buffer).

## The BASIC API: API.BAS

API.BAS wraps CALL MSXPI in two subroutines and shows four examples. Copy the file, keep lines 50 to 100 and 9999 onwards, and write your program from line 101. Lines 60 to 61 reserve 520 bytes at the top of memory for the buffer (BLKSIZE plus the header) and put the buffer address in BF. Lines 70 to 90 are shipped as comments: remove the leading apostrophes to load MSXPIEXT.BIN automatically when CALL MSXPIVER fails.

Routine | Line | Inputs | Result
SENDCOMMAND | 10000 | A = stdout (0, 1, 2) B = buffer address (&HC000) C$ = command D$ = parameters | RC = return code, -1 on error
PRINTSTDOUT | 11000 | A = 1 print, 0 return in C$ B = buffer address C = characters to return (A=0) | RC = &HE0 more data, &HED end

Example 1 - a DIR of the Pi printed directly (from API.BAS lines 110 to 153):

110 A=1 ' stdout: print to screen

120 B=&HC000 ' buffer address

130 C$="dir" ' command

140 D$="/home/pi/msxpi" ' parameters

150 PRINT:GOSUB 10000 ' SENDCOMMAND

153 PRINT:PRINT"finished:";HEX$(RC)

Example 2 - keep the reply in memory and print it with PRINTSTDOUT (lines 210 to 260):

210 A=2 ' stdout: save to buffer only

220 B=&HC000

230 C$="dir"

240 D$="/home/pi/msxpi"

250 PRINT:GOSUB 10000

253 IF RC=-1 THEN GOTO 260 ' connection error

255 A=1:GOSUB 11000 ' PRINTSTDOUT: print the buffer

Example 3 - read the reply into a string variable, 40 characters at a time (lines 310 to 365):

310 A=2:B=&HC000:C=40 ' C = characters per string

330 C$="dir":D$="/home/pi/msxpi"

350 PRINT:GOSUB 10000

353 IF RC=-1 THEN GOTO 365

355 A=0:GOSUB 11000 ' next 40 characters into C$

360 PRINT(C$);:IF RC<>&HED AND RC<>&HE7 THEN GOTO 355

365 PRINT:PRINT"finished:";HEX$(RC)

Example 4 - a custom server command, template, with parameters (lines 410 to 495) - the same server function shown in section 5.2:

410 A=1:B=&HC000

430 C$="template":D$="par1 par2 par3"

450 PRINT:GOSUB 10000

SENDCOMMAND itself is only a call to the ROM. This is the whole routine (lines 10002 to 10010):

10002 IFA=0THENCALLMSXPI("0,"+HEX$(B)+","+C$+" "+D$):GOTO 10010

10003 IFA=1THENCALLMSXPI("1,"+HEX$(B)+","+C$+" "+D$):GOTO 10010

10004 CALLMSXPI("2,"+HEX$(B)+","+C$+" "+D$)

10010 RC=PEEK(B):RETURN

Note that HEX$(B) builds the four-digit buffer address, and that the return code of the whole exchange is the first byte of the buffer.

Obsolete: The routines MSXPISEND (line 12000), MSXPIRECV (13000) and STORESTR (14000) in API.BAS are marked discontinued and refer to CALL commands that no longer exist. Do not use them.

## Tips for BASIC programs

- Test for the BIOS first: ON ERROR GOTO 90 : CALL MSXPIVER : GOTO 100, and at line 90 BLOAD"MSXPIEXT.BIN",R, as API.BAS does.
- Always test RC before using the data. RC &HE8 is a communication problem; RC &HE7 means the buffer holds an error text.
- Programs that must also run under openMSX should not assume 40 columns; the bundled programs default to 80 (var WIDTH=80).
- IRC.BAS shows a program that keeps state on the server across many CALL MSXPI calls instead of holding the server for a single long command.

# Developing in C

C is the language of the p commands themselves: p.com, pcopy.com, pver.com and msxarch.com are C programs. The C BIOS wraps the transport routines in a small API, declared in software/C-common/header/msxpi.h and implemented in software/C-common/lib/msxpi-bios.c (compiled to msxpi-bios.lib). Programs are built with SDCC and the Fusion-C headers for MSX-DOS; the library is linked with a custom MSX-DOS start-up file (--no-std-crt0).

## A minimal program

Client/src/templatc.c is the template for a new C command. It sends the command template with the DOS command-line parameters appended, and prints the reply:

#include <stdint.h>

#include <stdbool.h>

#include <stddef.h>

#include "../../../../../MSX/MSX-C/WorkingFolder/fusion-c/header/msx_fusion.h"

#include "../../C-common/header/msxpi.h"

int main(void)

{

uint8_t rc = SendCommandToMSXPi("template", true);

if (rc == RC_SUCCESS || rc == RC_FAILED) {

uint8_t* buffer = (uint8_t*)(get_buffer_ptr() + 100);

printstdout(buffer, MAXBUFSIZE);

}

return 0;

}

That is the pattern for the vast majority of commands: send the command, then print the reply. template A B sends "template A B", the server function template("A B") runs, and its reply is printed.

## API reference

Function | Purpose
uint8_t SendCommandToMSXPi(const char* cmd, bool appendDOSParameters) | Builds "cmd" (plus the DOS command line when the flag is true; a leading space is inserted) in the transfer buffer and sends it as a block. Returns RC_SUCCESS, or an error code. With an empty cmd it sends only the DOS command line, which is how p.com works: p dir / sends "dir /".
uint8_t printstdout(uint8_t* buffer, uint16_t maxbufsize) | Receives every block of the reply and prints it as text, until the final block. Does the handshake itself. Returns the final return code.
uint8_t PerformHandshake(uint16_t msx_blocksize) | The READY / READY_ACK handshake plus the announcement of the largest block the MSX accepts. Call it before RECVDATA_ONEBLOCK.
uint8_t RECVDATA_ONEBLOCK(uint8_t* dest, uint16_t* size, uint16_t msx_blocksize) | Receives exactly one block into dest, with checksum verification and retries; size receives the payload length. Returns RC_READY (more blocks follow), RC_SUCCESS (last block) or an error.
uint8_t RECVDATA(uint8_t* dest, uint16_t* size, uint16_t* maxbufsize) | Receives a complete multi-block reply into dest (handshake included). size receives the total length.
uint8_t SENDDATA2(uint8_t* src, uint16_t size, uint16_t* maxbufsize) | Sends one block (handshake, header, payload, checksum, retries). Used by SendCommandToMSXPi and for uploads.
uint8_t parseConnError(uint8_t rc) | Prints a message for a transport error code ("Checksum mismatch", "Error connecting to MSXPi server", ...) and returns the code.
char* GetCmdLineParameters(void) | The DOS command line, trimmed of leading spaces.
uint8_t* get_buffer_ptr(void), uint16_t get_max_buffer_size(void) | Start of free RAM after the program (the heap top) and how much is left before the stack.
void msxpi_link_claim(void), void msxpi_link_release(void) | Hold the MSXPi link for the whole of an exchange (below).
uint8_t msxpi_exchange(cmd, appendTail, buffer, maxbufsize) | Claim, send cmd, print the reply, release - in one call, with a single exit so the link cannot be left claimed.
uint8_t PIREADBYTE(uint8_t*), PIWRITEBYTE(uint8_t), CHKPIRDY(void) | Byte-level primitives on the ports. Normally not needed.
pprintf(text, value), pprints(text, text), FastPrint(text) | Small print helpers that avoid the weight of printf.

The constants in msxpi.h: ports CONTROL_PORT1 0x56, CONTROL_PORT2 0x57, DATA_PORT1 0x5A; BLKSIZE 512; MAXBUFSIZE 8192; BUFADDRESS 0xC000; GLOBALRETRIES 1 and MAX_BLOCK_RETRIES 3; the READY/ACK bytes; and the RC_ return codes of Appendix A.

## Example: pver.c - talk to the hardware and the server

pver reads the CPLD build ID directly from port $57, probes for /WAIT mode, then asks the server for its version with the same request p ver makes. It holds the link while it does so:

int main(void)

{

uint8_t raw, rc;

raw = InPort(CONTROL_PORT2);

Print("Port $57: "); PrintHexByte(raw); Print("\r\n");

if (raw >= 0xFE) {

/* No MSXPi CPLD answered: nothing to ask the server through. */

Print("Board : no MSXPi found\r\n");

return 0;

}

print_board(raw);

msxpi_link_claim();

rc = SendCommandToMSXPi("ver", false);

if (parseConnError(rc) == RC_SUCCESS || rc == RC_FAILED || rc == RC_BUFOVFLW) {

printstdout((uint8_t *)(get_buffer_ptr() + 100), MAXBUFSIZE);

} else {

Print("Server : connection error\r\n");

}

msxpi_link_release();

return 0;

}

print_board() shows how /WAIT support is detected: switch the mode on, see whether the port changes, switch it off again:

OutPort(CONTROL_PORT2, 0x01); /* try /WAIT mode on */

probe = InPort(CONTROL_PORT2);

OutPort(CONTROL_PORT2, 0x00); /* and off again */

Print(probe != (raw & 0x7F) ? "yes (burst)" : "no (polled)");

## Example: pcopy.c - a conversation with several blocks

pcopy shows the second common shape: the client calls one server function with sub-commands (pcopy init, pcopy readblock, pcopy putclose, ...) and receives one block per request, writing it to disk between requests. The receive loop of a Pi-to-MSX copy:

while (1) {

/* Request next block from server */

rc = SendCommandToMSXPi("pcopy readblock", false);

if (rc != RC_SUCCESS) {

Print("\r\nConnection error during read.\r\n");

fcb_close(&file);

return parseConnError(rc);

}

rc = PerformHandshake(maxbufsize);

if (rc != RC_SUCCESS) { /* handshake error, close, return */ }

Print(".");

rc = RECVDATA_ONEBLOCK(buffer, &block_size, maxbufsize);

/* A failed receive can leave block_size and the buffer partly filled:

never commit that data to disk. */

if (rc != RC_SUCCESS && rc != RC_READY) {

Print("\r\nTransfer aborted by server.\r\n");

fcb_close(&file);

return rc;

}

if (block_size > 0 && fcb_write(&file, buffer, block_size) != 0) { /* disk error */ }

if (rc == RC_SUCCESS) break; /* final block received */

}

The pattern to remember: send a request, `PerformHandshake`, `RECVDATA_ONEBLOCK`, act on the return code - RC_READY means come back for more, RC_SUCCESS means that was the last one, anything else is an error. Uploading (MSX to Pi) uses SENDDATA2 in the same way.

## Example: msxarch.c - reading structured data

When the reply is binary rather than text, read it with RECVDATA into your own buffer and pick it apart. msxarch does this for the 16-byte ROM header the server sends before every ROM (Figure 6):

uint8_t readRomHeader(RomHeader* hdr, char* reason, uint16_t reasonBufSize) {

uint8_t buf[ROM_MSG_MAX];

uint16_t replySize = 0;

uint16_t maxbuf = ROM_MSG_MAX;

uint8_t rc = RECVDATA(buf, &replySize, &maxbuf);

if ((rc != RC_SUCCESS && rc != RC_TERMINATE) ||

replySize < ROM_HEADER_SIZE || buf[0] != ROM_HEADER_MAGIC)

return RC_FAILED;

hdr->mapperType = buf[2];

hdr->bankSizeKB = buf[3];

hdr->bankCount = (uint16_t)buf[4] | ((uint16_t)buf[5] << 8);

## The shared link and the Ethernet UNAPI

When the Ethernet UNAPI is installed, an interrupt routine polls the Pi for incoming frames. If it transmitted in the middle of a command exchange, both streams would be corrupted. A program that talks to MSXPi for a long time, or that mixes several transport calls, should bracket the exchange with msxpi_link_claim() and msxpi_link_release(), or use msxpi_exchange(), which does so with one entry and one exit. Both are no-ops when no Ethernet UNAPI is installed.

## Memory and buffers

- The transfer buffer is char buffer[MAXBUFSIZE] pinned at BUFADDRESS ($C000) in SendCommandToMSXPi. It is the largest consumer of data memory; programs that switch mapper segments into page 2 (msxarch) relocate it deliberately.
- Replies are normally received into memory obtained from get_buffer_ptr() (the top of the program's heap); get_max_buffer_size() tells how much room there is before the stack. p /m shows these numbers for p.com.
- A reply larger than maxbufsize returns RC_BUFOVFLW; the part that fits has been received. Pass a buffer size that fits your program.

## Error handling

- Transport failures (after the retries) surface as return codes: RC_CHKSUM_ERR, RC_HANDSHAKEERR, RC_CONNERR, RC_BUFOVFLW. parseConnError() prints a message for them.
- RC_FAILED is not a transport failure: the server ran your function and reported an error in the reply text - print it with printstdout().
- CTRL+ESC pressed by the user is detected inside the transport and returns an error code; do not retry immediately, the server needs about five seconds to resynchronise.

# Developing in Assembly

The assembly BIOS is software/asm-common/include/msxpi_bios.asm, together with include.asm (constants and return codes) and a putchar_*.asm file that supplies PUTCHAR for the environment (MSX-DOS or BASIC). The same code is linked into the ROM, the disk driver, the BASIC extension and the .COM programs, so what is described here is exactly what the rest of MSXPi uses.

## Skeleton of a .COM program

Client/src/template.com.asm is the full template. It is an MSX-DOS program (origin $0100) that copies the DOS command line after the command name, sends it, and prints the reply:

org $0100

MAIN:

call resetMSXPI ; clear the transfer state

; Append the DOS command-line parameters (at $80) to the command text

ld hl,0x80

ld a,(hl)

or a

jr z,sendCmd

ld c,a

ld b,0

inc hl

ld de,parms

ldir

xor a

ld (de),a

sendCmd:

ld de,command

call SendCommandToMSXPi

jr c,PRINTPIERR

ld de,buf

ld bc,BLKSIZE

call CLEARBUF

ld de,buf

ld bc,BLKSIZE

call PRINTPISTDOUT

call PRINTNLINE

ret

PRINTPIERR:

ld hl,PICOMMERR

jp PRINT

PICOMMERR: db "Communication Error",13,10,0

; Core MSXPi APIs / BIOS routines

INCLUDE "include.asm"

INCLUDE "putchar_clients.asm"

INCLUDE "msxpi_bios.asm"

command: db "template "

parms: db 0

ds 255

buf: equ $

ds BLKSIZE

db 0

The command string must be terminated with zero. It is sent as a block, so its length is limited only by the transfer buffer; the server splits it at the first space. A .COM program has to define which scratch area the BIOS may use for its receive state: linked into a plain .COM it needs MSXPI_RAM_STASH equ 1 before the include (the disk driver defines MSXPI_DRIVER, and neither symbol defined is a build error - a wrong choice fails silently at run time).

## BIOS routines

All routines preserve the registers not listed. "C" and "NC" are the carry flag on return.

Routine | In | Out | Description
resetMSXPI | - | - | OUT ($56),$FF: reset the CPLD transfer state (and /WAIT mode). Call at the start of a program. Not assembled into the ROM.
CHKPIRDY | - | C: CTRL+ESC pressed; NC: ready | Waits until the Pi is ready (port $56 = 0), sampling CTRL+ESC from the key matrix.
PIWRITEBYTE | A = byte | C on CTRL+ESC | Waits for ready and writes A to port $5A.
PIREADBYTE | - | A = byte; C on CTRL+ESC | Starts a transfer, waits for it and reads port $5A.
SendCommandToMSXPi | DE = zero-terminated command | NC ok; C error; DE advanced | Sends the command as one block (a wrapper on SENDDATA). An empty string returns C.
SENDDATA | DE = source, BC = size (at most MAXBUFSIZE) | NC ok, DE = source + size; C error | One block: handshake, header, payload, checksum, up to GLOBALRETRIES retries.
PerformHandshake | A = block index, DE = destination, BC = block size the MSX accepts | NC ok; C error; A unchanged | READY / READY_ACK, then announces BC. Required before RECVDATA_ONEBLOCK. Reports its own carry (v1.6 fix).
RECVDATA_ONEBLOCK | A = expected block index, DE = destination, BC = block size | A = header return code, BC = payload length, DE = destination + length; C on error | Receives one block with checksum check and retries. The payload is written to memory only (no header); use the returned code to decide whether another block follows (RC_READY).
PRINTPISTDOUT | DE = buffer, BC = its size | A = last return code; C on error | Handshake, then receives every block and prints it as text. Terminates the text with zero.
STDOUTTONULL | DE = buffer, BC = its size | A, C as above | Same, but discards the reply.
PRINT | HL = zero-terminated text | - | Prints through PUTCHAR.
PRINTNLINE | - | - | Prints CR LF.
PRINTNUMBER | see source | - | Prints a number.
STRTOHEX, ATOHEX | see source | - | ASCII hexadecimal digits to binary.
CLEARBUF | DE = buffer, BC = size | - | Fills a buffer with zeroes.
STORE_BYTE | A = byte, DE = address | - | Stores A at (DE) correctly even when DE is in page 1 (banked ROM).

Register and stack usage matters in a few places: RECVDATA_ONEBLOCK uses IX and IY internally and the alternate register set (EXX) in its payload loop, and interrupts are managed by the routine (the payload loops run with them disabled). Do not call it from an interrupt handler.

## Example: receiving a reply block by block

PRINTPISTDOUT is itself a loop over RECVDATA_ONEBLOCK, and it is the model for any program that needs the data rather than printing it. This is the core of the routine (msxpi_bios.asm):

PRINTPISTDOUT:

call PerformHandshake ; required before RECVDATA_ONEBLOCK

xor a ; block number = 0

PRINTPISTDOUT0:

push af ; save block number

push bc ; maxbufsize expected

push de ; save buffer address

call RECVDATA_ONEBLOCK ; read one block

ld l,a ; save return code

ld a,TEXTTERMINATOR

ld (de),a ; terminate the text

call PRINT

cp RC_READY ; another block?

ret nz ; no: return

... ; restore, next block number

inc a

jr PRINTPISTDOUT0

To collect a reply in memory instead, copy this loop and move DE forward by BC after each block. The BASIC handler (msxpi_call.asm, CALL_MSXPISAVEDATA) does that: it accumulates the block lengths in HL and writes the header at the start of the buffer when done.

## Example: the BASIC CALL handler

The CALL MSXPI statement of the ROM and of MSXPIEXT.BIN is one shared source, asm-common/include/msxpi_call.asm. It is a good example of a routine that uses the BIOS from inside a ROM: it evaluates the BASIC string, splits it into stdout mode, buffer and command, sends the command and dispatches on the mode:

_MSXPI:

CALL EVALTXTPARAM ; evaluate the text parameter

PUSH HL ; save for BASIC

CALL GETSTRPNT ; address of the parameters

EX DE,HL

CALL PARSE_CALL_PARAMETERS

JP C,CALL_SYNTAX_ERROR

; A = stdout mode, DE = command, HL = buffer address

CALL SendCommandToMSXPi

JR NC,CALL_SUCCESS

... ; connection error: [0]=RC_CONNERR, size 0

CALL_SUCCESS:

cp '0'

jr z,CALL_DiscardResponse ; STDOUTTONULL

CP '2'

JR Z,CALL_MSXPISAVEDATA ; store in the buffer

ld bc,MAXBUFSIZE ; mode 1: print

xor a

call PRINTPISTDOUT

## Example: the disk driver

The MSX-DOS 1 disk driver (built for Nextor coexistence too) in ROM/src/MSX-DOS/msxpi-driver.mac is the most demanding user of the BIOS: DSKIO sends dskior or dskiow with the sector number and count, then moves 512-byte payloads. It uses MSXPI_DRIVER, keeps its receive state in the driver work area obtained with GETWRK, transfers straight to the caller's buffer when it is outside page 1 (and through the kernel XFER routine when it is not), and asks for /WAIT bursts (INIR) only after wait mode has been proved to work. It is the reference for anything that needs speed.

## Other useful sources

- Client/src/at28c256.com.asm - a complete tool: slot detection, page switching and reading the EEPROM from MSX-DOS.
- asm-common/transport/payload.z80 and generate.py - the burst and polled payload loops, generated for each consumer.
- UNAPI/src - the Ethernet UNAPI driver (ethcore.asm, ethops.asm, ethtrans.asm) and test clients.

# Appendices

## Appendix A: Return codes and protocol constants

Value | Name | Meaning
$A0 | READY_ACK | Handshake acknowledgement from the receiver
$A1 | SENDNEXT | Request the next chunk
$A2 | ENDTRANSFER | End of transfer
$AA | READY | Handshake: I am ready
$AD | RC_CHKSUM_ERR | Checksum still wrong after all retries
$AE | BUSY / WAIT | Busy marker
$E0 | RC_SUCCESS | Success; last block
$E1 | RC_INVALIDCOMMAND | Invalid or missing command or parameters
$E2 | RC_ESCPRESSED | CTRL+ESC pressed
$E3 | RC_BUFOVFLW | Reply larger than the buffer
$E4 | RC_INVALIDDATASIZE | Invalid data size
$E5 | RC_HANDSHAKEERR | Handshake failed
$E6 | RC_FILENOTFOUND | File not found on the Pi
$E7 | RC_FAILED | Server function failed; the block holds an error text
$E8 | RC_CONNERR | Connection error (set by the MSX)
$E9 | RC_WAIT | Wait
$EA | RC_READY | Success; more blocks follow
$EB | RC_SUCCNOSTD | Success, no standard output
$EC | RC_FAILNOSTD | Failure, no standard output
$ED | RC_TERMINATE | The server ends the conversation; nothing follows
$EE | RC_UNEXPECTEDDATA | Unexpected data received
$EF | RC_UNDEFINED | Undefined

Sizes: BLKSIZE = 512 bytes per block; MAXBUFSIZE = 8192 bytes; retries per block MAX_BLOCK_RETRIES = 3. Bit 15 of the length (or of the block size the MSX announces) is the /WAIT burst flag.

## Appendix B: msxpi.ini variables

The file is a list of var NAME=value lines (comments start with #) in the MSXPi home directory. p set NAME value changes a value and saves the file.

Variable | Default / example | Purpose
PATH | /home/pi/msxpi | Current path for p dir / pcopy
DriveA, DriveB | disks/msxpiboot.dsk, disks/tools.dsk | Disk images for drives A: and B:
DriveM, DriveR1, DriveR2 | ftp://192.168.1.100, msxarchive.nl MSX1 / MSX2 | The m:, r1: and r2: virtual drives
WIDTH | 80 | Screen width for the bundled programs
WIFISSID, WIFIPWD, WIFICOUNTRY | -, -, GB | Used by p wifi set
DSKTMPL | disks/blank.dsk | Template for new disk images
IRCNICK, IRCADDR, IRCPORT | msxpi, chat.freenode.net, 6667 | IRC client
OPENAIKEY, OPENAIMODEL | -, gpt-4o-mini | ChatGPT (p chatgpt)
RAPIDAPIKEY, RAPIDAPIHOST, FINNHUBKEY, TWELVEDATAKEY, ALPHAVANTAGEKEY | placeholders | Stock quote providers (STOCKS.BAS). No key ships with MSXPi.
SPI_HW | False | Use the Pi hardware SPI instead of GPIO bit-banging
SPI_CS, SPI_SCLK, SPI_MOSI, SPI_MISO, RPI_READY | 21, 20, 16, 12, 25 | GPIO numbers of the link (Appendix C)
RPI_SHUTDOWN | 26 (unset), or none | GPIO of the shutdown/reboot button; none disables it (boards without the button)
GPIO_CS_SETUP_NS | 0 (unset) | Settling time between CS low and the first clock edge; 1000 on the v0.8.2 board
ROMDB | URL or path | Optional ROM database used by msxarch to name and classify ROMs

Environment: MSXPI_NATIVE_GPIO=1 (on by default in msxpi-monitor and the systemd units) enables the native GPIO engine; MSXPI_GPIO_CS_SETUP_NS overrides GPIO_CS_SETUP_NS.

## Appendix C: GPIO pin assignments

The default wiring between the interface and the Raspberry Pi. To connect an MSXPi to a Raspberry Pi 2/3/4 by wires, use the same pins; a wired connection can be unstable.

MSXPi signal | Raspberry Pi GPIO | Optional GPIO (PCB v1.1 Rev.0 jumpers) | Header pin (primary / optional)
CS | 21 | 8 | 40 / 24
CLK | 20 | 11 | 38 / 23
MOSI | 16 | 10 | 36 / 19
MISO | 12 | 9 | 32 / 21
SPI_READY (RPI_READY) | 25 | 24 | 22 / 18
Shutdown button | 26 | - | 37
GND | GND | GND | 6, 9, 14, 20, 25, 30, 34, 39

The optional pins, when used, must also be set in msxpi.ini. Pin numbering of the Raspberry Pi header:

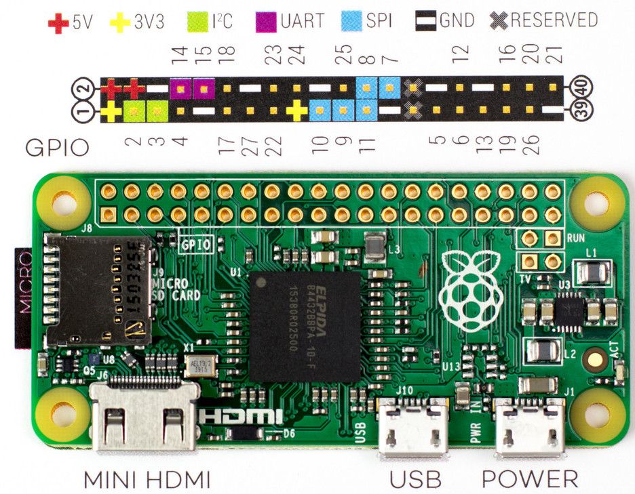
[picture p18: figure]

Figure 11: GPIO numbering, models B+, 2, 3 and Zero

## Appendix D: The MSXPi device for openMSX and the CPLD

The openMSX device (software/openMSX/src/MSXPiDevice.cc) is the software counterpart of the VHDL design in hardware/CPLD_Project. Both implement the same ports, protocol and control flow, so the same ROM and the same server work with either; they differ in execution model.

Aspect | CPLD (VHDL) | openMSX device
Timing | Bit-level, on the rising edge of SPI_SCLK | Byte-level over a TCP socket; asynchronous and buffered
Concurrency | Parallel signals reacting to clock edges | A reader thread and queues
Bus direction | Drives BUSDIR_n, tristates the data bus | Simulates reads and writes; no electrical contention
SPI signals | Drives SPI_MOSI, MISO, CS directly | Emulated through the TCP protocol
/WAIT | WAIT_n held while a byte is in flight (v1.6) | Emulated stall of about 20 us per byte, with fault injection for a low RPI_READY
Server link | GPIO, 5 wires | TCP, default port 5000 (msxpiserver_port), TCP_NODELAY, back-pressure instead of discarding bytes
Firmware ID | Read from port $57 | Reports $0E, a v1.6 /WAIT build

This equivalence lets developers test and debug MSXPi software under openMSX before running it on hardware, and extend the protocol in either domain with confidence. The extension is loaded with -ext MSXPi; MSXPi.xml places the device on ports $56, $57 and $5A and the 16 KB BIOS ROM at $4000. A variant without the ROM (MSXPiNoROM) exists for testing MSXPIEXT.BIN.

## Appendix E: Files in software/target

File | What it is
msxpibios.rom | The ROM for the EEPROM (16 KB): BIOS, disk driver, Ethernet UNAPI
msxpiext.bin | MSXPIEXT.BIN: the BASIC extension for interfaces without an EEPROM
p.com, pcopy.com, pver.com, msxarch.com, msxarch.ini, LOADROM.COM, at28c256.com | The client commands
template.com, templatc.com | Assembly and C templates for new commands (server function template)
INL.CFG, Telnet.com, Telnetf.com, STELNET.COM, CP437.COM | TCP/IP configuration and clients
skmsx.com | Utility
API.BAS, IRC.BAS, WEATHER.BAS, DOLAR.BAS, RASTRO.BAS, STOCKS.BAS, TESTDIR.BAS | BASIC programs
msxpiupd.bat, msxpirfh.bat | The updater
disks/msxpiboot.dsk, tools.dsk, MSXDOS.SYS, COMMAND.COM | Disk images for the MSX-DOS 1 boot mode and the kernel files

MSXPi v1.6 - User's and Developers Guide

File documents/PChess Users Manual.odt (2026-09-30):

PChess

User's Manual

Chess for MSX2 with the MSXPi interface

Version 1.1 — September 2026

# 1. Introduction

PChess is a chess program for MSX2 computers. Normally it works with an MSXPi interface: the MSX draws the board and reads the keyboard or joystick, and the MSXPi server on the Raspberry Pi (or PC) checks every move against the full rules of chess, runs the computer opponent and handles network play. PChess can also run without the MSXPi server, on an MSX with a TCP/IP network stack; the MSX then checks the rules itself (section 10).

You can play in four ways:

- Local: two people take turns at the same MSX.
- AI: you play white against the computer (Stockfish, with eight strength levels).
- Room: two players join the same named room, through a small relay on the local network or through an IRC channel (section 8).
- Online: players meet in the #msxpi channel on an IRC network (Libera.Chat by default), find each other, send an invitation and play by private messages.

The rules are all included: check, checkmate, stalemate, castling, en passant, promotion (also to a knight, bishop or rook) and claimable draws, which are accepted automatically.

## 1.1 Requirements

- An MSX2 or later (V9938 VDP). 64 KB of VRAM is enough. On an MSX1, PChess says PCHESS NEEDS AN MSX2; use PCHESS1 instead (section 9).
- An MSXPi interface and a running MSXPi server, version 1.6 or later; or, for the TCP/IP link, a TCP/IP UNAPI network stack such as InterNestor Lite (section 10).
- On the server, the Python package chess (from requirements-pchess.txt) and, for a strong computer opponent, Stockfish. The MSXPi setup script installs both.
- For Room or Online play, a network connection on the server.

# 2. Installation

## 2.1 Server

The MSXPi setup script installs everything. To install by hand on a Raspberry Pi:

sudo apt install stockfish

pip install -r /home/pi/msxpi/requirements-pchess.txt

Without Stockfish, PChess falls back to a much weaker built-in engine. Restart the MSXPi server after you install anything.

## 2.2 MSX

Copy PCHESS.COM to any MSX-DOS disk. The file is in software/target in the MSXPi repository, and it can be built from software with make.bat pchess.

# 3. Starting PChess

Boot MSX-DOS, go to the drive that holds PCHESS.COM and type PCHESS:

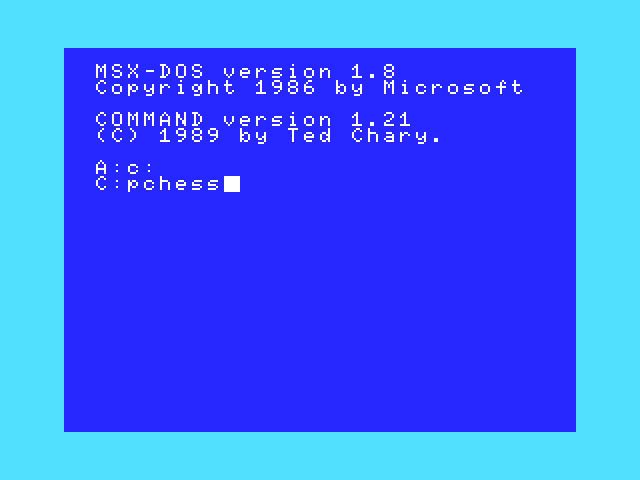
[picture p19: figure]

Figure 1: Starting PChess from the MSX-DOS prompt

After a few seconds the board appears. The status line at the bottom shows 1 LOCAL 2 AI, and no game is running yet. Choose a mode with the number keys listed in the right-hand panel.

Figure 2: The PChess screen after start-up

## 3.1 The screen

- The board: files A–H are shown above it and ranks 1–8 to its left. A yellow frame marks the cursor.
- Top of the panel: PCHESS before a game; AS WHITE or AS BLACK once you are matched. Below it, the side to move (WHITE/BLACK) and TURN, or GAMEOVER when the game has ended.
- MOVES: the most recent moves of the game.
- Key list: 1 LOCAL, 2 AI, 3 ROOM, 4 ONLINE, 5 SEEK, 6 ASK, 7 ACCEPT, 8 PLAYER.
- Entry field: under the key list, labelled MOVE, ROOM or PEER for what you are typing.
- Status line at the bottom: messages such as WHITE TURN, WAIT ACK, INVITE SENT, DRAW AGREED.

## 3.2 Keys at a glance

Key | Action
1 | New local two-player game
2 | New game against the computer (you play white)
3 | Room mode: type a room name and press Return
4 | Online: connect to IRC and join #msxpi
5 | SEEK: announce in #msxpi that you want a game (at most once a minute)
6 | ASK: type a player's nickname and press Return to invite them
7 | ACCEPT the invitation shown on the status line
8 | PLAYERS: list the players who are seeking or have invited you
Arrows / joystick | Move the cursor
Space / Return / fire A | Select a piece, then its destination square
Letters and digits | Type a move (e2e4, Nf3, O-O, a7a8n), then Return
Backspace | Correct the move being typed
ESC | Menu: AI level, rooms, link, offer draw, resign, rotate board, credits, exit

# 4. Playing against the computer (AI)

## 4.1 Starting a game

Press 2. A new game starts with you as white (AS WHITE), and the status line reads WHITE TURN.

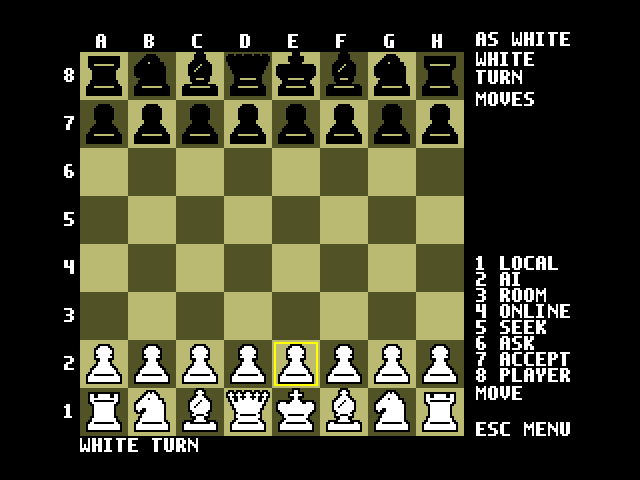
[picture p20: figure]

Figure 3: A new game against the AI

## 4.2 Choosing the AI level

1. Press ESC to open the menu. The first row, AI LEVEL, shows the current level.
2. With AI LEVEL highlighted (= marks the chosen row), press Right to make the AI stronger or Left to make it weaker.
3. Press Return to save the level. The status line confirms it, e.g. AI LEVEL 4 ELO 1350.
4. Press ESC to return to the game.

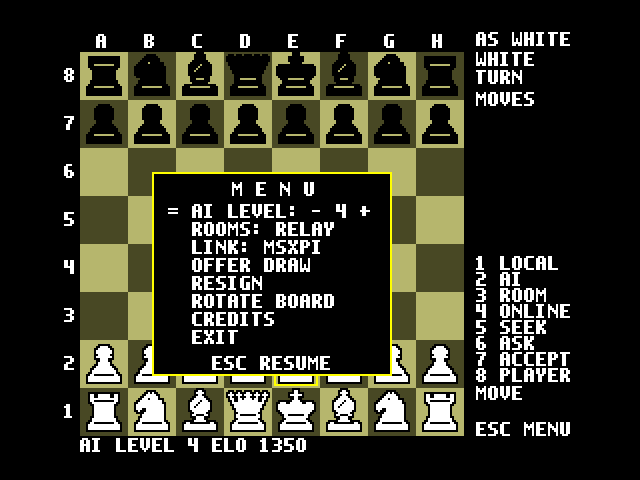
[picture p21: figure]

Menu open, level 2 | Level 4 saved

Figure 4: Changing the AI level

The level is saved on the server (PCHESSELO in msxpi.ini), so it stays set for later games. Levels and their approximate ratings:

Level | Approximate strength (Elo)
1 / 2 / 3 | 600 / 800 (default) / 1000
4 / 5 / 6 | 1350 / 1600 / 1900
7 / 8 | 2200 / 2500

Stockfish cannot play below about 1320. For levels 1–3, PChess uses its weakest setting with a shallow search, so those ratings are rough. The AI thinks for PCHESSMOVETIME seconds per move (default 1).

# 5. Moving pieces

There are two ways to enter a move, and you can use either one at any time.

## 5.1 With the cursor (keyboard or joystick)

1. Move the yellow cursor onto one of your pieces with the arrow keys (or joystick port 1).
2. Press Space, Return or fire button A. The piece's square turns green.
3. Move the cursor to the destination square.
4. Press Space/Return/A again. The piece moves and the move is added to the MOVES list.

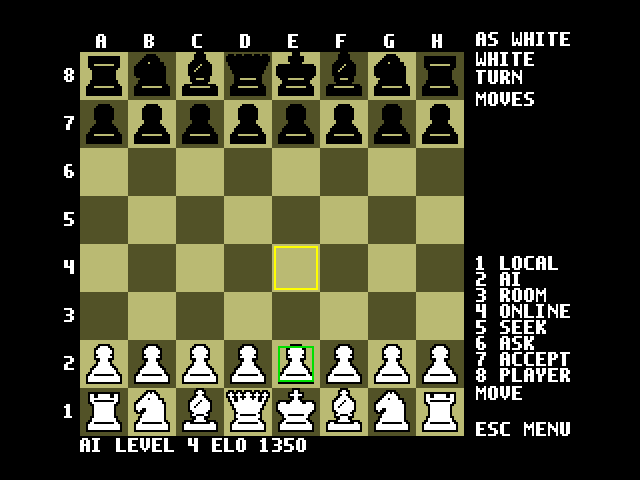
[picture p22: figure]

Step 2: pawn on e2 selected (green) | Step 3: cursor on e4

Figure 5: Moving with the cursor

To pick a different piece, select it instead of choosing a destination. A pawn promoted with the cursor always becomes a queen; to under-promote, type the move (a7a8n).

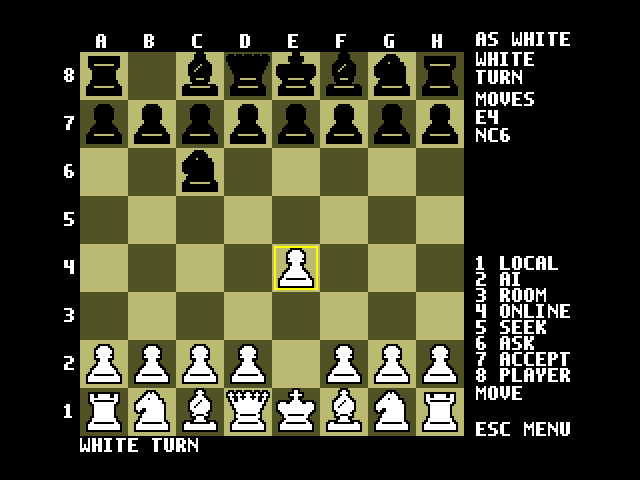
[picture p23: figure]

Figure 6: After 1. e4 the AI replied Nc6

## 5.2 By typing the move

Type the move and press Return. PChess accepts two notations:

- UCI (from-square, to-square): e2e4, g1f3, promotion a7a8q or a7a8n.
- SAN (standard algebraic): e4, Nf3, Bxc6, O-O, O-O-O.

What you type appears next to MOVE in the panel. Use Backspace to correct it. An illegal move is rejected and the position does not change.

Typing Nf3 | After Return; the AI answered e6

Figure 7: Entering a move by typing

# 6. Offering a draw and resigning

## 6.1 Offering a draw

1. Press ESC, move down to OFFER DRAW and press Return.
2. The status line asks OFFER DRAW? Y/N. Press Y to confirm; any other key cancels (GAME GOES ON).

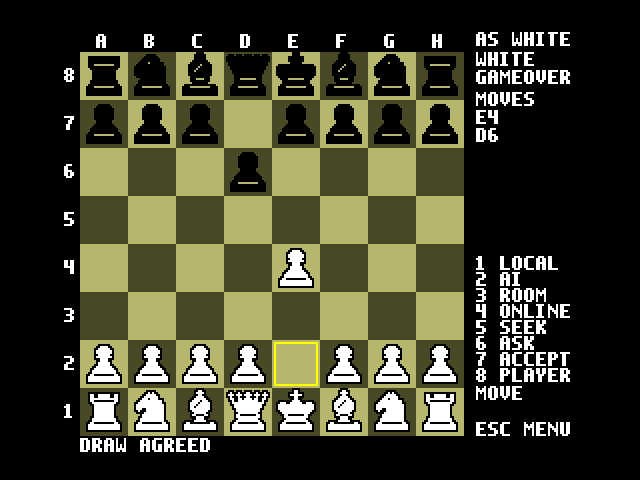
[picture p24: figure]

Confirming the offer | The AI accepted: DRAW AGREED

Figure 8: Offering a draw to the AI

How the offer is answered depends on the mode:

- Local: the game is drawn at once.
- AI: the computer accepts unless it is more than half a pawn ahead. Otherwise the status line reads AI DECLINES THE DRAW and play continues.
- Room/Online: you can only offer on your own move. The opponent sees OPPONENT OFFERS DRAW - ESC MENU and accepts by choosing OFFER DRAW too, or declines by making a move (section 7.6).

## 6.2 Resigning

1. Press ESC, move down to RESIGN and press Return.
2. The status line asks RESIGN? Y/N. Press Y to resign.

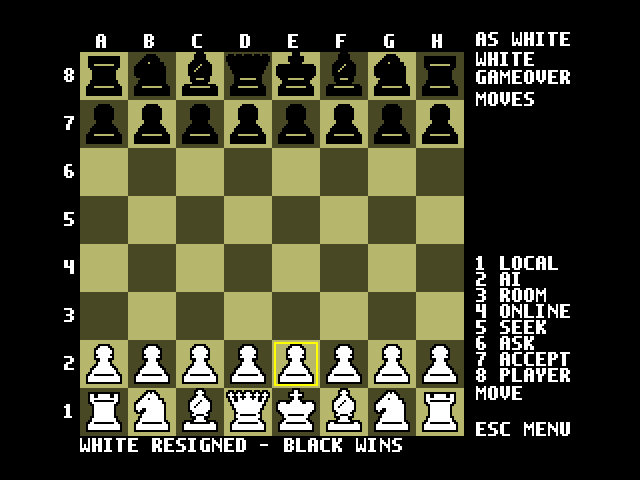
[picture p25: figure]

RESIGN? Y/N | WHITE RESIGNED - BLACK WINS

Figure 9: Resigning

In a local game, the side to move resigns. If no game is running, the status line reads START A GAME FIRST. The PSG plays a rising tune when you win and a falling one when you lose.

# 7. Playing online (IRC)

In Online mode, PChess connects to an IRC network from the MSXPi server and joins the public channel #msxpi. The channel is only used to say you are available (SEEK). Invitations, moves, draw offers and resignations go by private message between the two players, and ordinary channel chat is ignored.

## 7.1 Server configuration

Online play works without an account. Both players must use the same IRC network. In msxpi.ini:

var IRCADDR=irc.libera.chat

var PCHESSIRCPORT=6697

var IRCNICK=yournick

Pick a unique nickname: a letter, then letters, digits, _ or -, up to 16 characters (many IRC networks allow only 9). TLS is used by default on port 6697. If the network asks for an account (status LOBBY ACCOUNT LOGIN REQUIRED (477), e.g. during spam waves), register a free Libera.Chat account and add IRCACCOUNT and IRCPASSWORD. Restart the server after editing msxpi.ini. All the options are described in documents/PCHESS-IRC.md.

The example below shows two players, alice (left screens) and bob (right screens).

## 7.2 Step 1: go online

Press 4. After a few seconds the status line shows LOBBY <your nick>. Wait for this before seeking or inviting. If the connection fails, the error is shown on the status line.

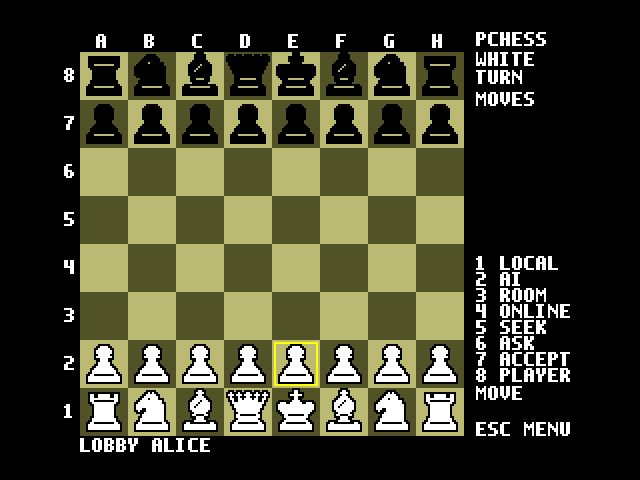
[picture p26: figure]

alice | bob

Figure 10: Both players are in the lobby

## 7.3 Step 2: seek a match

To tell everyone in #msxpi that you want a game, press 5. The status line reads SEEK SENT. You can seek once a minute; pressing 5 again sooner is refused.

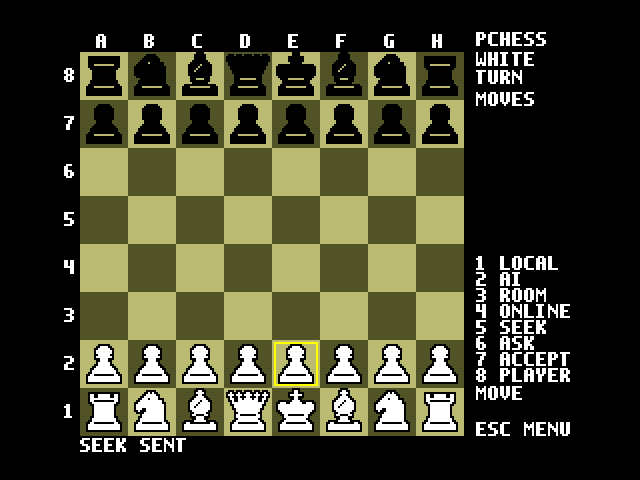
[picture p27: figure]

Figure 11: bob announces a wish to play (key 5)

## 7.4 Step 3: find out who is seeking

Press 8 to open the PLAYERS list. It shows up to seven players who sent SEEK or invited you in the last ten minutes, newest first, and the status line shows the count (e.g. 1 PLAYER). The list is kept by your own server, so opening it sends nothing to IRC.

- Up/Down chooses a player (= marks the selection).
- Return invites the selected player (the same as key 6).
- ESC closes the list.

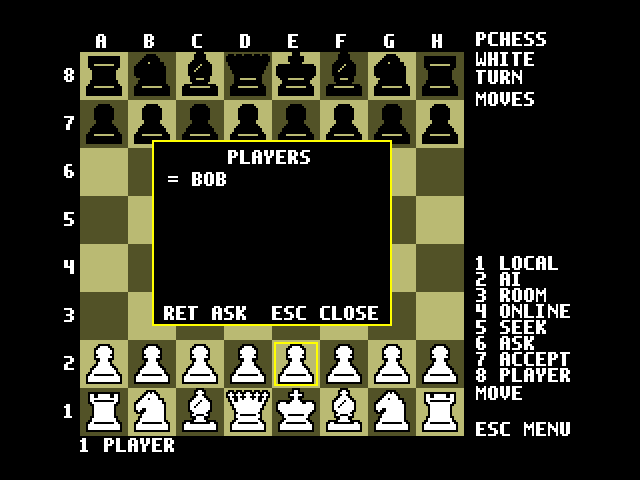
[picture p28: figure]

Figure 12: alice opens the player list (key 8) and sees bob

## 7.5 Step 4: ask for a match

There are two ways to invite a player:

- From the PLAYERS list: select the player and press Return, or
- Press 6 (ENTER PEER NICK AND RETURN), type the player's nickname next to PEER and press Return. Use this when you already know the nickname, e.g. a friend who has not sent SEEK.

The status line then reads INVITE SENT.

Key 6: enter the nickname | alice typed next to PEER

Figure 13: Inviting a player by nickname

## 7.6 Step 5: accept a match

The invited player's status line reads INVITE <nick> PRESS 7. Press 7 to accept. The game starts when both sides have confirmed (WAIT READY is shown briefly). The player who sent the invitation plays white; the player who accepted plays black.

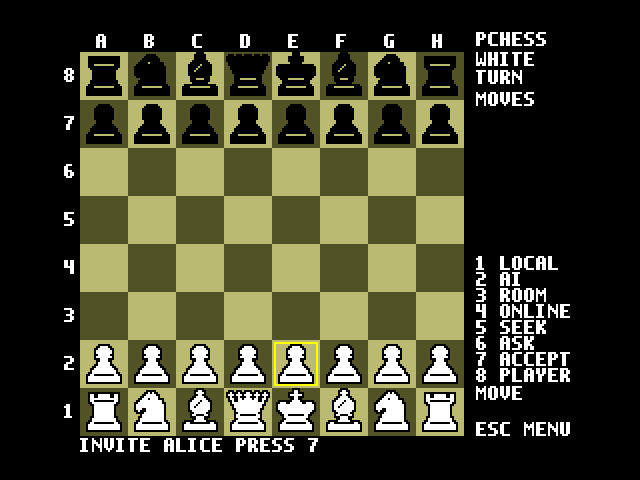
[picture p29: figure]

alice: INVITE SENT | bob: INVITE ALICE PRESS 7

Figure 14: The invitation arrives

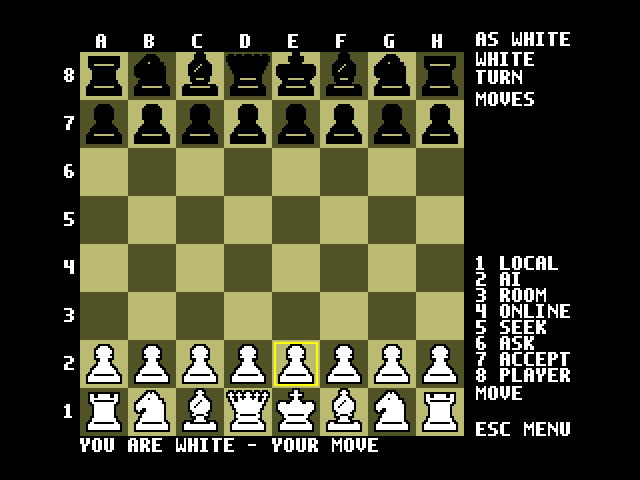
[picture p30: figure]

alice: YOU ARE WHITE - YOUR MOVE | bob: AS BLACK, board rotated

Figure 15: Matched: each player sees their own pieces at the bottom

Black sees the board rotated so that its pieces are at the bottom. The cursor moves as shown on screen, and typed moves are the same either way. The panel shows AS WHITE or AS BLACK, and the status line shows whose move it is, e.g. YOU ARE BLACK - BOB MOVES.

## 7.7 Step 6: play

Move pieces as in section 5. After your move the status line reads WAIT ACK until the opponent's MSXPi confirms it has received the move (a lost message is resent automatically). The opponent's move then shows up within a couple of seconds.

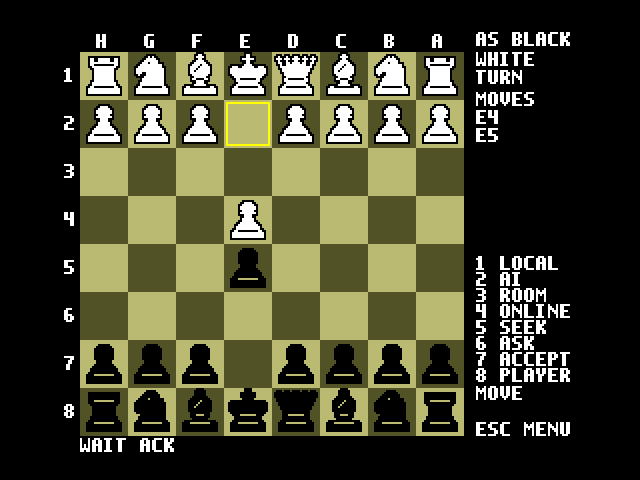
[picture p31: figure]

alice played e4 (WAIT ACK) | bob answered e5

Figure 16: Moves travel by private message

## 7.8 Offering and accepting a draw online

1. On your move, press ESC, choose OFFER DRAW, Return, then Y. The status line reads DRAW OFFERED.
2. The opponent sees OPPONENT OFFERS DRAW - ESC MENU and hears two beeps.
3. To accept, the opponent chooses OFFER DRAW in the ESC menu and presses Y. Both screens show DRAW AGREED.
4. To decline, the opponent just makes a move. The offer ends when the player it was made to moves.

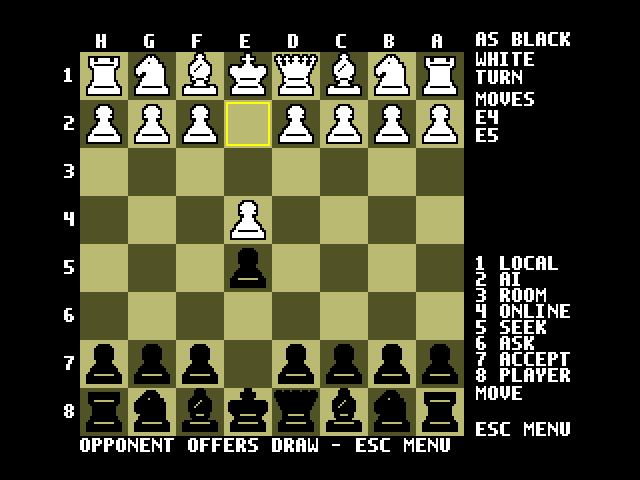
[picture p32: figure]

alice: DRAW OFFERED | bob: OPPONENT OFFERS DRAW

Figure 17: A draw offer

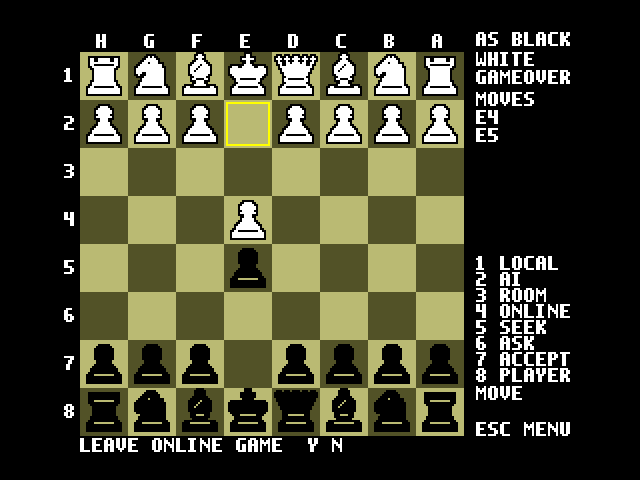
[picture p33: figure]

bob accepts through OFFER DRAW | DRAW AGREED

Figure 18: Accepting the draw

## 7.9 Resigning online

Choose RESIGN in the ESC menu and press Y. Both screens show the result, for example BLACK RESIGNED - WHITE WINS.

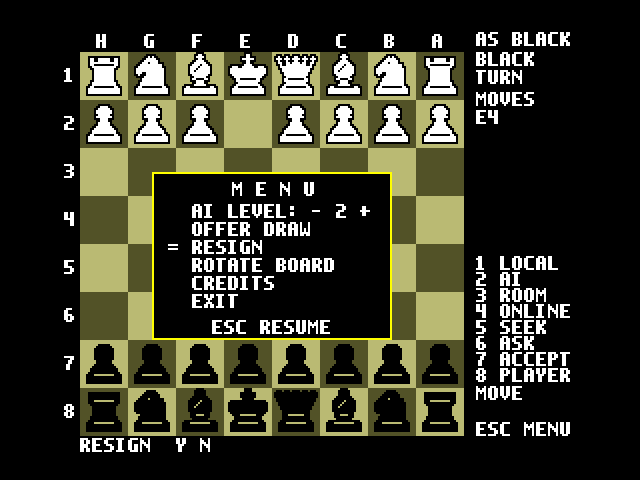
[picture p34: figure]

alice (black) resigns | bob sees the result

Figure 19: Resigning an online game

## 7.10 Playing another game

When a game is over you can start the next one straight away: press 6 to invite a player (the same opponent or someone else), 7 to accept an invitation, or 5 to seek. The final position stays on the board until the new game starts. There is no need to go back to the lobby first.

To leave online play, press one of the keys 1–4. Because you are online, they first ask LEAVE ONLINE GAME? Y/N. Y goes ahead, and any other key keeps the current game (STILL ONLINE). This stops you from dropping a game in progress by pressing the wrong key.

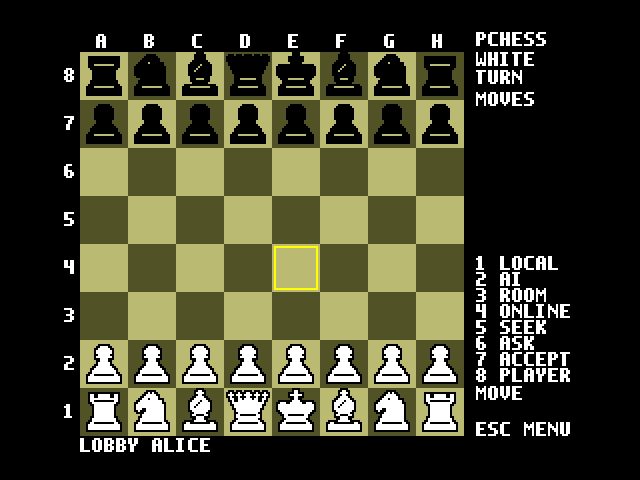
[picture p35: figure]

Key 4: LEAVE ONLINE GAME? Y/N | Y: back in the LOBBY

Figure 20: Leaving online play

# 8. Playing in a room

In Room mode two players meet by typing the same room name. A room is either a small HTTP relay on the local network (the default, sections 8.1 and 8.2) or an IRC channel (section 8.3); the ROOMS row in the ESC menu chooses which. On the relay, the first player to join plays white.

## 8.1 Relay configuration

One MSXPi server hosts the relay. On the host, leave PCHESSRELAY empty. The relay listens on PCHESSLISTEN:PCHESSPORT (default 0.0.0.0:5080) while that player is in Room mode:

# host (e.g. IP 192.168.1.20)

var PCHESSRELAY=

var PCHESSLISTEN=0.0.0.0

var PCHESSPORT=5080

# the other player

var PCHESSRELAY=http://192.168.1.20:5080

As an alternative, a stand-alone relay can run on any third machine. Point PCHESSRELAY on both MSXPi servers at it:

python msxpi_pchess.py --listen 0.0.0.0 --port 5080

The relay uses plain HTTP, so only use it on networks you trust.

## 8.2 Joining a room

1. Press 3. The status line reads ENTER ROOM AND RETURN.
2. Type the room name you agreed with your opponent (shown next to ROOM) and press Return.
3. The first player sees WAIT PLAYER until the second joins. The second player plays black and sees YOU ARE BLACK - OPPONENT MOVES.

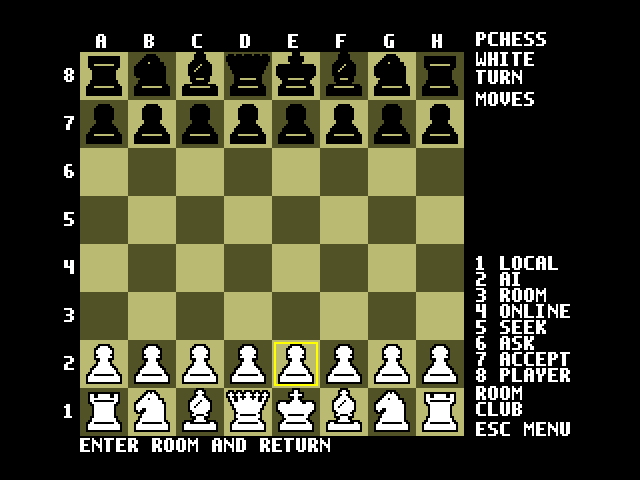
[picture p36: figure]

Key 3 | Room name "club" typed

Figure 21: Entering a room

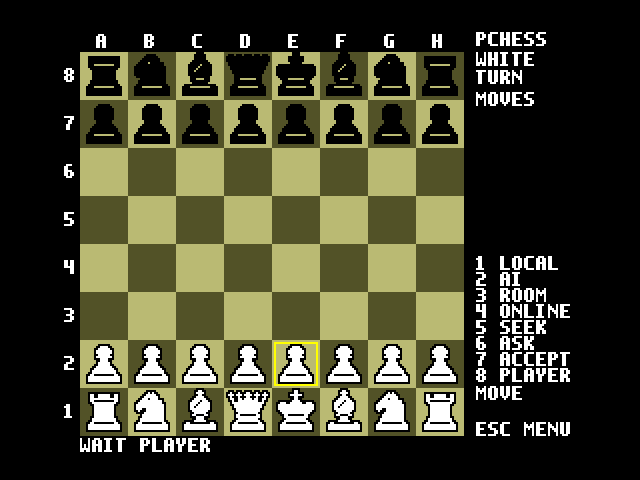
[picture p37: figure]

First player: WAIT PLAYER | Second player joins as black

Figure 22: Joining the room

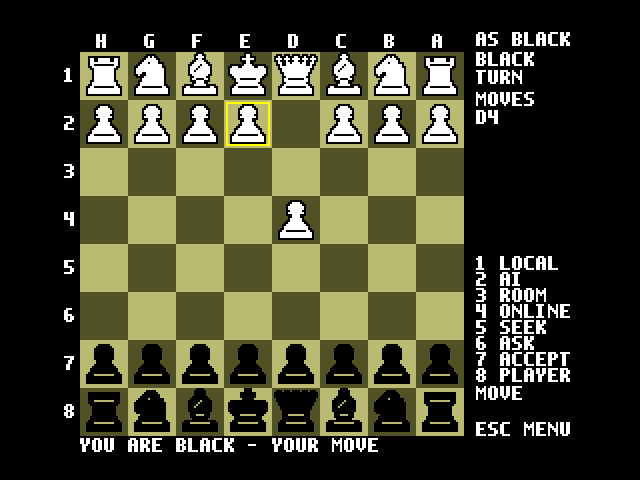
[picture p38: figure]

White: YOU ARE WHITE - YOUR MOVE | Black sees 1. d4

Figure 23: The room game starts

Moving, offering a draw and resigning work exactly as in Online mode (sections 7.7–7.9), and so does the LEAVE ONLINE GAME? Y/N question.

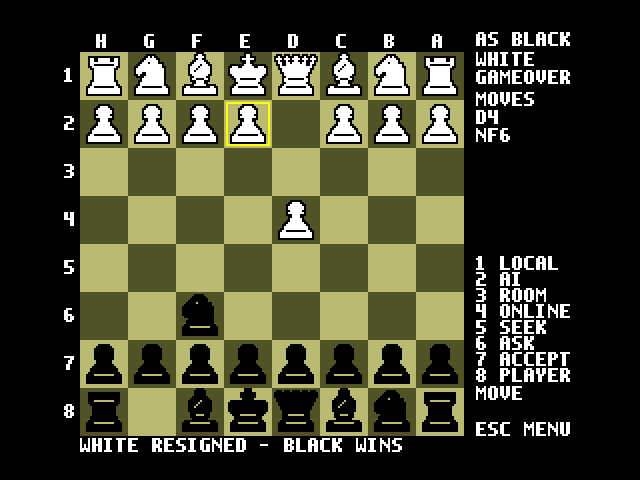
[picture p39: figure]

White resigns | WHITE RESIGNED - BLACK WINS

Figure 24: Resigning in a room

## 8.3 Rooms on IRC

Choose ROOMS in the ESC menu, press Right or Left until it reads ROOMS: IRC, and press Return. The setting is saved on the server (PCHESSROOMS in msxpi.ini):

var PCHESSROOMS=irc

Room names then become IRC channels on the lobby's network (the settings of section 7.1): room club is the channel #pchess-club. IRC rooms need no relay, work across the internet, and are shared by MSXPi players and players on the TCP/IP link (section 10).

- Both players press 3, type the same room name (1-16 letters or digits) and press Return.
- The player whose nickname comes first in alphabetical order plays white. The game starts by itself; there is no invitation to accept.
- A third player who enters the room sees ROOM BUSY - GAME IN PROGRESS.
- After a game, entering the same room name again starts a rematch.

Figure 25: ROOMS: IRC selected in the ESC menu

Moving, offering a draw, resigning and leaving work as in an Online game (sections 7.7-7.10).

# 9. Other features

## 9.1 Local two-player game

Press 1. Two people share the keyboard, and each moves the side whose turn is shown in the panel. A draw offer ends the game at once, and RESIGN resigns for the side to move.

## 9.2 Rotating the board

Choose ROTATE BOARD in the ESC menu to turn the board over at any time, in any mode. The file and rank labels turn with it.

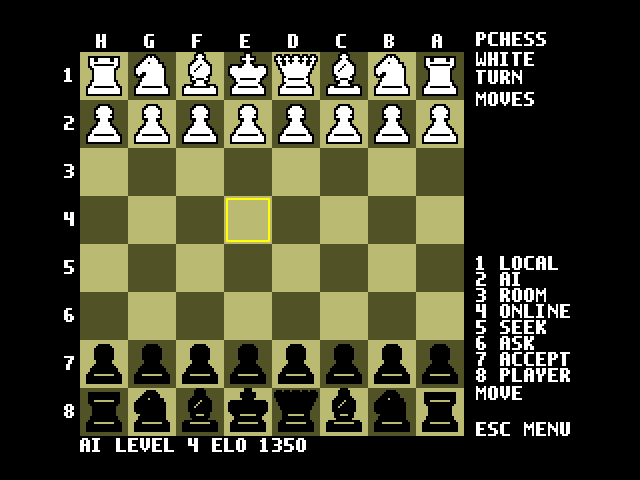
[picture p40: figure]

Figure 26: The board rotated (black at the bottom)

## 9.3 Credits and exit

CREDITS in the ESC menu shows the program credits; press any key to close them. EXIT returns to MSX-DOS. Press ESC in the menu to go back to the game.

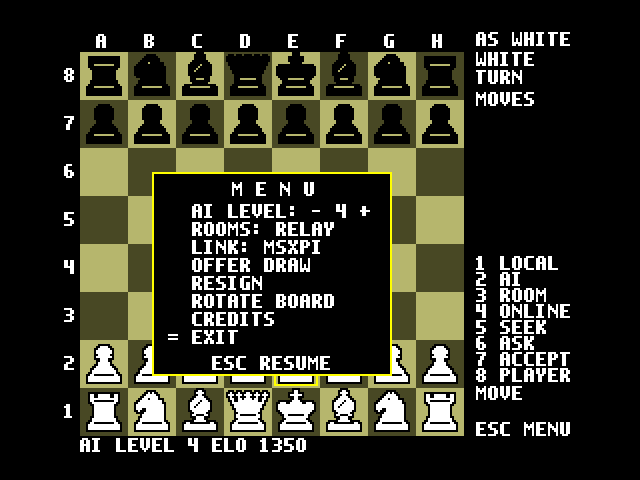
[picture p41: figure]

Figure 27: EXIT selected in the ESC menu

## 9.4 Sound

The PSG beeps twice when the opponent offers a draw. It plays a rising tune when you win and a falling one when you lose (in a local game, any win plays the rising tune).

## 9.5 PCHESS1 for MSX1

PCHESS1.COM is the MSX1 (TMS9918, 16 KB VRAM) version. It has the same modes, keys and network protocol, so an MSX1 can play against an MSX2. Its pieces have no outline, the cursor is red and the selection is green, and the panel shows YOU ARE WHITE and VS <nick>. It also has the ROOMS and LINK rows of the ESC menu, so it can play over TCP/IP as well (section 10); on an MSX1 the TCP/IP stack needs a memory mapper.

# 10. Playing over TCP/IP (without the MSXPi server)

PChess can also use the network directly, through a TCP/IP UNAPI implementation: InterNestor Lite running over the MSXPi Ethernet driver, or a network cartridge such as GR8NET, ObsoNET or DenYoNet. The MSX then checks the rules of chess itself, and Room and Online games go straight to IRC with the same messages the MSXPi server uses, so players on either link play each other.

## 10.1 Installing the TCP/IP stack

Load the stack in MSX-DOS before starting PChess:

MSX-DOS 1 with a memory mapper: MSR I then INL I

Nextor / MSX-DOS 2: RAMHELPR I then INL I

INL.CFG, next to INL.COM, holds the network addresses; INL S shows them. With the MSXPi Ethernet driver the Pi side is set up as described in the MSXPi Users and Developers Guide. On an MSX1 the stack needs a memory mapper.

On Nextor, RAMHELPR I reloads the command interpreter, which can leave you on drive A:. Change back to the drive that holds INL.COM before typing INL I.

## 10.2 Switching the link

- Press ESC and move down to LINK.
- Press Right or Left: the row reads LINK: TCPIP, and ROOMS shows IRC.
- Press Return (or ESC). The status line reads LINK TCPIP.

LINK: TCPIP selected | LINK TCPIP

Figure 28: Switching to the TCP/IP link

Every start of PChess uses LINK: MSXPI. Switching ends any game in progress. If no TCP/IP stack is loaded, the status line reads NO TCP/IP UNAPI - RUN INL I and the link stays MSXPI. Choose LINK: MSXPI the same way to go back.

## 10.3 Settings: PCHESS.INI

There is no msxpi.ini on this link. PChess reads PCHESS.INI from the current directory when the link is switched:

IRCADDR=irc.libera.chat

IRCPORT=6667

IRCNICK=yournick

All three lines are optional, and the values shown are the defaults, except the nickname: without IRCNICK it is pch and four random hex digits, a new one each time the link is switched to TCPIP. The IRC server must accept plain connections on that port, because the Z80 cannot use TLS; for the same reason IRC account login is not available on this link. After editing the file, switch LINK again (or restart PChess).

## 10.4 What works on the TCP/IP link

- 1 LOCAL: the MSX checks every move, including check, mate, stalemate, castling, en passant, promotion and the draws by repetition, the fifty-move rule and insufficient material.
- 3 ROOM: always an IRC room (section 8.3); the ROOMS row is fixed at IRC.
- 4 ONLINE, 5 SEEK, 6 ASK, 7 ACCEPT, 8 PLAYERS: as in section 7, in #msxpi on the IRC network set in PCHESS.INI.
- 2 AI needs the MSXPi server: the status line reads AI NEEDS MSXPI - ESC MENU LINK.

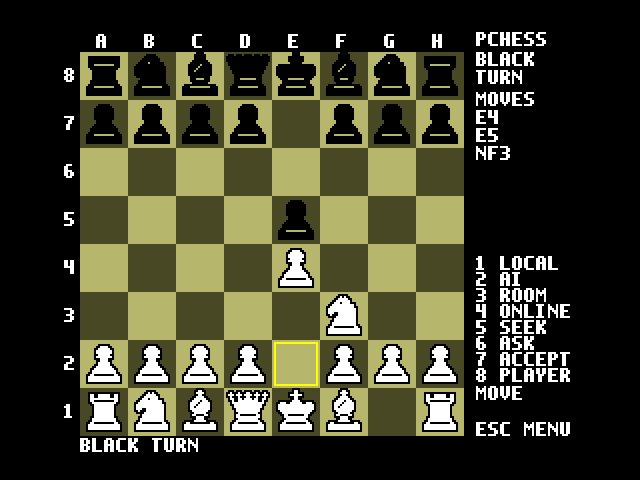
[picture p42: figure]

Figure 29: A local game on the TCP/IP link

Each move carries a check of the position that the MSX computes, which takes about half a second, and the connection is read once a second, so a move reaches the other player within a couple of seconds.

## 10.5 Quick start: an online game over TCP/IP

- 1. Put PCHESS.INI with your IRC server and nickname in the directory you will start PChess from (section 10.3).
- 2. In MSX-DOS, load the stack: MSR I (MSX-DOS 1) or RAMHELPR I (Nextor), then INL I.
- 3. Type PCHESS. Press ESC, go down to LINK, press Right, then Return: the status line reads LINK TCPIP.
- 4. Press 4. After a few seconds the status line reads LOBBY <your nick>.
- 5. Find an opponent as in section 7: 5 to seek, 8 to list players, 6 and a nickname to invite, 7 to accept. Or press 3 and a room name to meet in an IRC room (section 8.3).
- 6. Play, offer a draw or resign exactly as in sections 7.7-7.9.

# 11. Troubleshooting

Message | Meaning / what to do
LINK ERROR - RETRY | The MSX could not reach the MSXPi server. Check the server is running and try the key again.
PCHESS NEEDS AN MSX2 | Use PCHESS1.COM on MSX1 computers.
START A GAME FIRST | A move, draw or resign with no game running. Press 1, 2, 3 or 4.
Wait before announcing again | SEEK can only be sent once per minute.
Cannot challenge now | A game or an invitation is still in progress, or you tried to invite yourself. Finish or resign the current game first; after a game ends you can invite at once.
No invitation | Key 7 was pressed but nobody has invited you.
LOBBY ACCOUNT LOGIN REQUIRED (477) | The IRC network requires a registered account. Set IRCACCOUNT/IRCPASSWORD.
WAIT ACK stays on | The opponent's MSXPi has not confirmed the move. It is resent up to three times; check both network connections.
AI DECLINES THE DRAW | The computer thinks it is ahead. Play on.
Go online first (4) | SEEK, ASK, ACCEPT or PLAYERS before going online. Press 4 and wait for LOBBY <nick>.
CANCELLED | ESC was pressed while typing a room name or nickname.
In a room; no lobby | SEEK and PLAYERS belong to the #msxpi lobby, not to an IRC room. Press 4 for the lobby.
ROOM BUSY - GAME IN PROGRESS | Two players are already playing in that IRC room. Wait, or use another room name.
Lobby nickname in use | Someone on the IRC network has your nickname. Change IRCNICK (msxpi.ini or PCHESS.INI) and press 4 again.
NO TCP/IP UNAPI - RUN INL I | LINK: TCPIP was chosen with no TCP/IP stack loaded. Exit, run MSR I or RAMHELPR I, then INL I (section 10.1).
LOW MEMORY: TPA xxxx END xxxx | Too little free memory for the TCP/IP link, usually because of many drives or resident programs. Please report both numbers.
AI NEEDS MSXPI - ESC MENU LINK | Key 2 on the TCP/IP link. Switch LINK back to MSXPI to play the computer.
TCPIP ROOMS ARE IRC | ROOMS cannot be changed on the TCP/IP link.
DNS ERROR, CONNECTION FAILED, NO NETWORK | TCP/IP link: the IRC server cannot be reached. Check the stack (INL S), IRCADDR and IRCPORT.

Limitations: games are kept in memory only (on the server, or on the MSX on the TCP/IP link). There are no chess clocks, and a game cannot be resumed after a disconnect.

PChess User's Manual for MSXPi — page 10

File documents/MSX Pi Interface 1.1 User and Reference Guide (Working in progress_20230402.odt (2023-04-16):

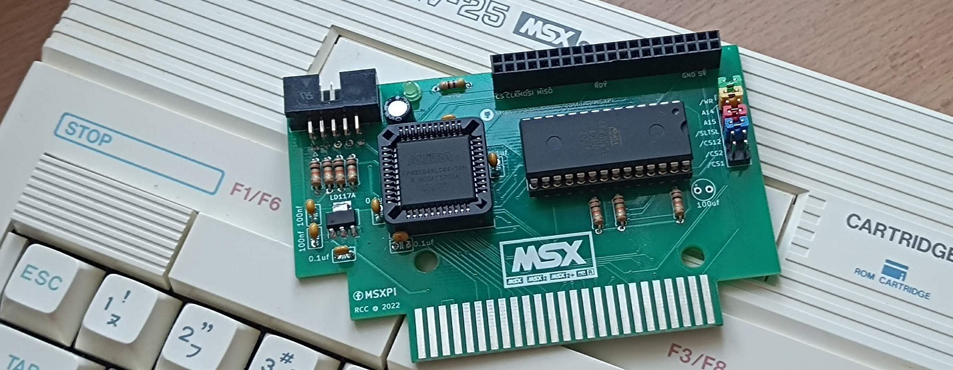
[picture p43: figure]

MSXPi Interface Version 1.1

Users & Developers Guide

MSXPi Interface v1.0 is a design crearted and implemented by Ronivon Costa, 2016 – 2020.

# MSXPi Overview

MSXPi is a hardware and software solution to allow MSX computers user Raspberry Pi devices as generic peripherals. I say “solution” because the hardware needs a paired Client/Server software in addition to the interface, to provide any useful functionality.

MSXPi hardware is composed of a MSX compatible interface to connect to the slot cartridge of any MSX 1,2,2+ and Turbo R. Due to some specific hardware implementation of some MSX models, the interface may not work on all MSX models. Also, the integrated MSX-DOS only works on 64K machines.

MSXPi software is composed of different components running on MSX and on Raspberry Pi. On the Raspberry Pi side, there is the msxpi-server component which listen for GPIO events, decode serial data using a few pins and transform that data into control commands and parameters. On the MSX side, there are different software components depending on how the user wants to use MSXPi.

- MSX-DOS is stored in the MSXPi EPROM. This is the MSX-DOS v1.0 customized with the MSXPi low level drivers to allow boot from MSX standard disk images stored on Raspberry Pi. The EPROM also contain a set of CALL commands to use from BASIC.
- MSX-DOS commands - these are “.com” commands that implement a series of functionalities on MSX-DOS allowing greater experience with MSXPi. This is the current approach to develop software for MSXPi, since it covers most of the users abse and allows for greater flexibility.
- MSXPIEXT.BIN with CALL commands to extend BASIC to access MSXPi without the need of the EPROM. This program adds a set of CALL commands in the RAM area in $4000, allowing new commands to be installed from DISK runnning “msxpiext.bin”. It actually installs the MSXPi BIOS into a simulated ROM cartridge installed in RAM.

In the next sections we will discuss the resources currently available for MSXPi, and how to use them.

## What's new in version 1.1

This version is a major overhaul of the MSXPi. It was added support to the Z80 /wait signal, allowing a change to the low level drivers to be simpler, more straighforward and easy to support and add software. To support this major change, existing interfaces will need a small simple hardware mod, and to use the new software versions available.

Changes on Version 1.1

- PCB redesigned for software erasable EEPROM AT28C256. With this change the ROM can be re-written directly form the MSX-DOS using the included programmer. Jumpers modified to support the new features.
- Transfer routines changed again, for simplicity and stability. Uodated all clients and MSX-DOS driver.
- Pcopy command improved to detect when copies are done to the disk images, and copy the files directly to the image without the need to send to MSX, which in turn would send it back to the image.
- All “p” commands return a header: Return Code (1byte), Block size (2 bytes), Data (BLKSIZE). This is an optional parameter in the transfer function, which can be disabled for custom developed commands
- Added mapping of network & internet locations configurable by user using pset command: R1: (defaults to msx1 roms in msxarchive.nl), R2: (defaults to msx2 roms in msxarchive.nl), M: (defaults to local ftp server ftp://192.168.1.100). This work with commands pcd and pcopy, for example: pcopy /z R1:frogger.zip
- Added supported to automatically decompress archive files during the transfer with “pcopy /z”
- Added improved recover logic to stop MSXPi from staying in sync error loop.
- Lots of other bug fixes and improvements

Changes on Version 1.0

- PCB redesigned with support for /wait signal, use of by-pass capacitors for greater stability, and external pull-up resistors on all RPi GPIOs used by the interface.
- Requires a Mod to the existing interfaces v0.7: remove the BUSDIR jumper. Wire the CPLD pin 11 to the MSX /wait signal (requires a simple soldering skills).
- CPLD logic redesigned to implement the /wait signal, although at this version it will be set to tristate at all times.
- Server architecture completed re-written to be simple, more modular, easier to extend and maintain.
- All client applications re-engineered to support the new interface architecture.
- MSX-DOS ROM was recompiled to support the new interface architecture.
- Added CRC16 error correction on all download transfers (RPi to MSX)
- Server-side configurable number of transfers retry upon errors

Changes from Version 0.8.2

- A more complete set of CALL commands
  Starting at ROM build 20171230.00077, MSXPi contain a new set of CALL commands in ROM allowing it to be used in BASIC and from within BASIC programs.
  Not all MSXPi commands are be compatible, but some are (such as PRUN, PSET, PDIR) and allow exchange of data with Pi in BASIC.
- The new CALL commands also available as a BASIC extension (msxpiext.bin) for MSXPi that interfaces with older ROMs.
- New server in Python
  The msxpi-server has been ported to Python. This improves development time, at the same time allowing same level of transfer rate since the transfer of blocks of data are still using the C function.
- IRC client and WhatsUp client
  Two messaging clients are available, in BASIC, for these messaging platforms. They use the new CALL commands, and are compatible with either the new ROM or the msxpiext.bin extension.

# Users Guide

This release comes with an EEPROM containing MSX-DOS 1.03. This is an unmodified MSX-DOS OS with drivers to support the MSXPi booting from a DSK disk image stored in the Raspberry Pi filesystem.

Note that there are structural changes to the server and client components. Because of that, the EPROM software (BIOS) and P commands must match the Raspberry Pi server component, or some commands will fail. Do not try to boot using old versions of the EEPROM or use old P commands with this release – they will not work.

MSXPi boots into MSX-DOS on MSXPi drive A: which is mapped to the disk image in /home/pi/msxpi/disks/msxpiboot.dsk. The MSX can also boot from MSX-DOS2 in another interface, and still have access to MSXPi files on the Raspberry Pi using P commands.

Drive B: is mapped to /home/pi/msxpi/disks/msxpitools.dsk which contains all currently available DOS commands to use with MSXPi and some other tools.

There are other three virtual devices mapped to be used by commands PCD, PDIR and PCOPY:

M: Mapped to ftp://192.168.100

R1: Mapped to http://www.msxarchive.nl/pub/msx/games/roms/msx1

R2: Mapped to http://www.msxarchive.nl/pub/msx/games/roms/msx2

All these mappings can be changed by the user to point to any other remote locaiton using PSET command.

When booting from MSXPi, you can also have a second disk drive interface attached (such as ATA-IDE or MegaFlashRom SD). These drives will be accessible from MSX-DOS1 and you can exchange files between MSXPi disk images and those drives (* Note: this is not currently working with Zemmix).

The MSXPi tools and how to use them is covered in a later section.

## MSXPi BIOS

The EEPROM contain the MSX-DOS 1.03, allowing MSX to boot into MSX-DOS directly from the interface. It contains also the BIOS (CALL commands) available to the user from BASIC:

- CALL MSXPIVER
  Display the ROM version and available commands
- CALL MSXPI
  Run MSXPi commands on RPi. Can optionally use a buffer to store data returned by Raspberry Pi.
- CALL MSXPISEND
  Send any data to Raspberry Pi, which can be a command, data, or both.
- CALL MSXPIRECV
  Receive data from Raspberry Pi.

See the description and usage of these commands in 2.3 below.

## MSXPIEXT.BIN & MSX-DOS ROM

MSXPIEXT.BIN is an extension for BASIC, that can be used by older MSXPi which ROM was not updated to latest releases. It can also be used without the need to have an EEPROM enabled in the MSXPi, which is the case if you only want to use MSXPi resources along with your MSX-DOS 2 or Nextor booting from other interface. This command should be loaded and executed to add new CALL commands to MSX-BASIC, and will only work on 64KB computers because it install itself as a ROM cartridge in RAM area starting at address #4000.

To install the extension, run the following command from BASIC:

bload”msxpiext.bin”,r

A short help is displayed with the available commands.

## MSXPi CALL Commands

These commands use a buffer to exchange data with RPi. The buffer has a fixed length of 256 bytes (it’s defined in the source code (include files) in the BLKSIZE constant. T

CALL MSXPi(“<stdout>,<buffer address>,<command>”)

Executes a command defined in the “msxpi-server.py”, receives the reply data and process it according to the option specified in the “stdout” parameter.

Possible values for stdout parameters

stdout | Description
0 | Ignore the date returned by RPi
1 | Print tall received data o screen. If the data is 1 block only, full data is also available in the buffer. If it is larger than one block, only last block is available in the buffer
2 | Store all received data in the buffer area. Note that if the data received is larger that the area reserved for buffer, there will memory corruption and possible crash

Buffer_Address: This is a string composed of four hexadecimal digits for a memory area to receive data from RPi – for example, “C000”. It must have at least 256 bytes (BLKSIZE) available from this address.

Command: Any command defined in the “msxpi-server.py” program. Each command is created as a function in the server, as for example “pdir”, “pcd”, “prun” or any other command created by the developer.

_MSXPi uses a buffer of size BLKSIZE (256 bytes) to receive data from RPi. The first block received will contain a header, as shown in this table:

Address | Buf+0 | Buf+1 | Buf+2 | Buf+3 up to Buf+3+Size
Content | Return code | # Data Size (lsb) | # Data Size (msb) | Data (this area size=lsb+256*msb)

All blocks will always have the same size – the first block will contain 3 bytes less available for data, because the first three bytes are used for header. All remaining blocks will have only data (no headers).

A transfer occurs BLKSIZE bytes at a time, and it may have one or more blocks. If the total data to transfer is larger than the BLKSIZE, then more than one block transfer will be required - the CALL MSXPi command takes care of these, making sure all data is available for the user. However, if you implement your own commands in the server to be called by CALL MSXPi, then you must assure that the server contains the correct logic to send the blocks sequentially as described. Refer to one of the MSXPi server commands to understand how it can be done.

lsb and msb bytes contain the data size for the data in this block. This is required because even tough the transfers occur in blocks of fixed size (BLKSIZE), the actual user data might be less that a block – all remaining data in the block is always padded with zeros. It’s also needed in cases where the data is larger than one block – the header contain the size for the whole data across all blocks. The client program must control how much data is read from RPi based on this header.

The size for the useful data in the block can be calculated in BASIC as follows (assuming it was passed “C000” in the CALL MSXPi command):

SIZE=PEEK(&HC001)+256*PEEK(&HC002)

If the returned data is larger than 509 bytes, then it must be transferred using two blocks or more (first block = 3 bytes header + 509 bytes of data, next blocks = 512 bytes of data).

Note that this buffer structure is hard-coded in the MSXPi Bios commands, and needs to be fulfilled by the respective MSXPi Server commands running in the Raspberry pi. This structure is only required to be set at the server side by specific commands developed to interface with this CALL command (typically, “output” parameter set to “2” – see description of CALL MSXPi below).

The return codes in the first block can be one of:

RC_TXERROR | Connection error or checksum error after all retries. This error is generated by the MAX client software because the transfer failed
RC_SUCCESS | Operation successful – This code is returned by the RPi. if any data is expected, it is available in the data area of the buffer.
RC_FAILED | Operation failed – this code is returned by RPi. The data area in the buffer should contain the error message from RPi operation.

Other return codes are available for use in development – consult the include.asm file reference.

When the command is called, the following scenarios may develop:

1. Connection error: RPi did not receive the command or it failed the checksum. The return code will be RC_TXERROR (set by the MAX due to lack of communication with RPi)

2. RPi received the command, processed it but it failed: The return code will be set by RPi to RC_FAILED and there will be an error message in the buffer - some server-side programs might set to a different error code, it’s up to the developer to define which error code they want to use.

3. RPi received the command, processed and it succeed. The return code is RC_SUCCESS, and there will be data available in the buffer.

CALL MSXPISEND(“buffer_address”)

“buffer_address” is a four digit hexadecimal number.

Send contents of buffer to RPi (it uses the SENDDATA function from msxpi_bios.asm). This command uses the buffer format as specified previously. The First byte should be left unused, and the next two bytes should contain the size of the data to transfer.

CALL MSXPIRECV(“buffer_address”)

“buffer_address” is a four digit hexadecimal number.

Read data from RPi and store in the buffer (it uses the RECVDATA function from msxpi_bios.asm). After completing the transfer, the first byte will contain the return code and the next two bytes will contain the number of bytes received.

## Examples using CALL Commands

2.3.1 CALL MSXPI

call msxpi(“pdir”)

call msxpi(“0,pdir”)

call msxpi(“1,pdir”)

call msxpi(“2,D000,pdir”)

Note: in the last example, since we passed flag “2”, the output of the command is saved in the buffer starting at address #D000.

2.3.2 CALL MSXPISEND

In this example, we will send data (a simple “TST” command) to RPi and verify the return code received.

10 gosub 100 ' Send a command to RPi

20 rc=peek(&hD000): ? hex$(rc) ' Get Return Code

50 end

99 ' Send data to RPi – a text command in this case

100 POKE &HD000,0 ' This is the area reserved for the return code

110 POKE &HD001,3:POKE &HD002,0 ' This is the buffer size (LSB,MSB)

120 POKE &HD003,ASC('T')

130 POKE &HD004,ASC('S')

140 POKE &HD005,ASC('T')

150 CALL MSXPISEND(“D000”) ' Send command TST to Rpi

160 RETURN

2.3.3 CALL MSXPIRECV

This example receive data from RPi and print on screen. For this reason, is is convenient that the data is ascii in a valid range so it will be correcly displayed on screen. This same routine also works with any binary data.

10 gosub 100 ' Receive data from RPi

20 rc=peek(&hD000): ? hex$(rc) ' Get Return Code

30 if rc=&hE0 then gosub 200 ' If RC=RC_SUCCESS then print data

50 end

99 ' Receive some data from RPi

100 POKE &HD000,0 ' This is the area reserved for the return code

110 POKE &HD001,0:POKE &HD002,0 ' This is the area reserved for buffer size

120 CALL MSXPIRECV(“D000”) ' Received data from RPi

130 RETURN

200 S=PEEK(&HD001)+256*PEEK(&HD002) ' Get size of buffer

210 FOR M = 0 TO S-1 ' Will read all bytes in the buffer

220 PRINT CHR$(PEEK(&HD003)+M); ' and print on screen.

230 NEXT M:RETURN

# MSXPi Architecture and Behavioral Description

Picture 1 show the MSXPi architecture.

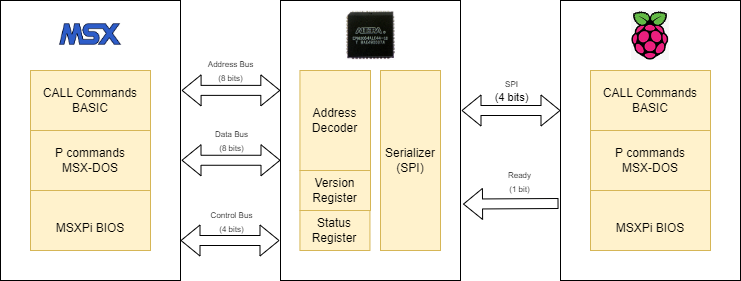
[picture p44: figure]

Figure 1: Architecture

The interface works in polling mode - each transfer must be always initiated by the MSX, and uses serial transfer between CPLD and Raspberry Pi. Because of this technical feature, it is not ideal for some applications that require high throughput, such as graphics applications specially because the server component is implemented in a slow, interpreted language (Python). Currently the benchmark transfer rate is approximately 5KB per second (Kilo Bytes / s).

The interface between MSX and RPi is made using a CPLD tolerant to 5 volts, the EPM3064 from Altera. In this CPLD it is implemented the logic to decode the I/O ports and other MSX bus signals (/wr, /rd, /iorq) and transfer a byte between MSX and Raspberry Pi using a simple shift register clocked by the Raspberry Pi once the MSX writes or read to the MSXPi port. Due to the fact that the clock for the transfer is generated by the RPi, the speed is mandated by that device, which will be impacted by background applications running along with the msxpi-server.py component.

The client application s (.com commands) was developed in the Assembly Z80 language, and the server application developed in Python. Performance could be improved by developing components in C language at the server-side, however is’t a lot more difficult and timing consuming.

On the Raspberry side, the application runs on the Raspbian, and is automatically initialized every time the Pi is connected by the systemd service.

By using a standard linux system, the solution allows a wide range of applications to be easily developed through the use of existing tools in Raspberry, both for programming and for accessing Pi GPIOs.

# Connecting MSXPi to the Raspberry Pi

The interface is compatible with any model of Raspberry Pi, although it was developed for the "Zero" model, so that it is fully incorporated into the cartridge. The only exposed parts will be SD, USB and LED card slots.

The GPIO pins (see Appendix 1) of the Pi used by the interface are:

GPIO | Purpose | Direction | Enabled | CPLD Pin
21 | /CS (SPI Chip Select) | Input | 0 | 28
20 | SCLK (SPI Clock) | Output | N/A | 34
16 | MOSI (Interface out) | Input | N/A | 5
12 | MISO (Interface in) | Output | N/A | 41
25 | PI_Ready | Output | 1 | 12
| GND (Pin 4) | N/A | N/A
| VCC (Pin 6) | N/A | N/A

When using RPi Zero, power is supplied by MSX.
When using RPi 1,2 or 3, RPi must be connected to an external power supply.

To attach Raspberry Pi Zero to the interface, use the photo in illustration 2 as a reference. As for software version 1.0, only 7 Pins are used on Raspberry Pi Zero as indicated with the red arrows. Soldering is only required in the signaled pins.

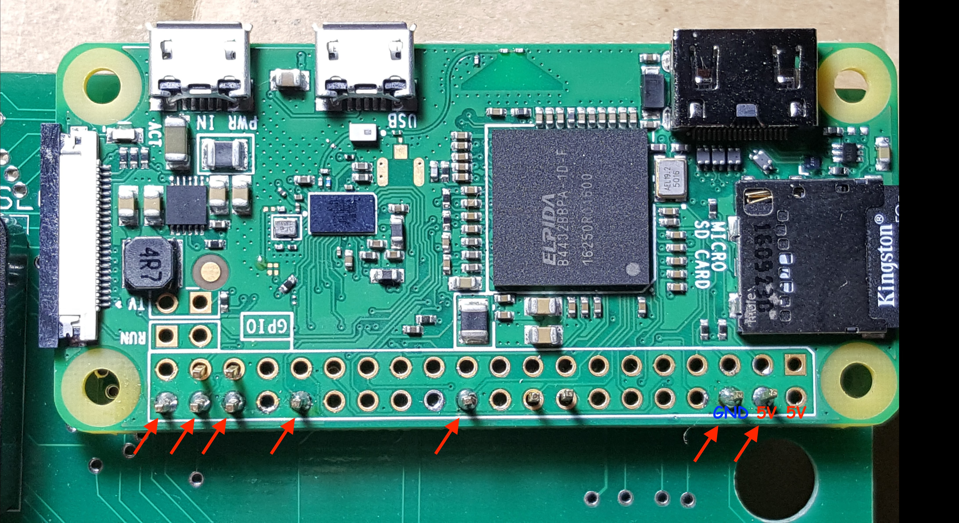
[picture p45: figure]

Figure 2: Attaching Raspberry Pi Zero to the interface

To attach a Raspberry Pi model B +, 2 and 3 to the interface, use the picture in illustration 3 as a reference.

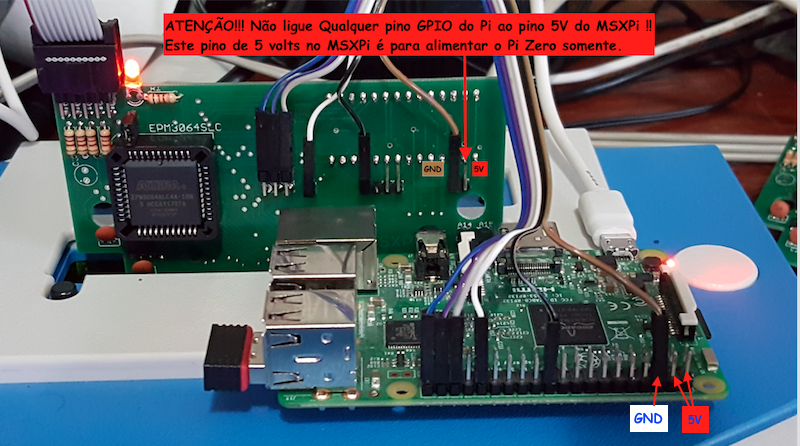
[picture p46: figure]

Figure 3: Connection of the B +, 2 and 3 models

Note: It is essential that the MSXPi GND (brown wire) is connected to the Raspberry Pi. Without this connection, the signals on the interface pins will not be transmitted correctly.

# MSXPi Programmer's Reference

This section describes the MSXPi specific IO library. This library is hardware-dependent and should be always be used instead of trying to access the hardware directly. This will allow for greater compatibility with future releases of the hardware.

The MSXPi software library consist of a set of Z80 assembly routines on the MSX side, and a C and Python framework on the Raspberry Pi side. In this section we focus on the MSX-side library.

The MSXPi project has the following structure:

/asm-common/include/include.asm → contain constant definitions and MSX BIOS labels

/asm-common/include/basic_stdio.asm → contain the PUTCHAR call for programs in BASIC environment and cartridge programs (such as MSX-DOS driver)

/asm-common/include/msxdos_stdio.asm → contain the PUTCHAR call for MSX-DOS programs, and also a MSX-DOS wrapper for the SENDPICMD bios routine.

/asm-common/include/msxpi_bios.asm → Contain all data transfer and other bios functions (hardware-independent) used by MSXPi programs.

/asm-common/include/msxpi_io.asm → This file contain the hardware-dependent I/O functions for MSXPi. All functions in this library access MSXPi hardware ports, and are called by functions in the libraries mentioned previously.

/asm-common/include/msxpi_api.asm → contain extra-routines that might be useful.

Next section will describe the bios functions only.

## MSXPi BIOS (MSXPI_BIOS.ASM)

CHKPIRDY

Label : CHKPIRDY

Purpose : Read the MSXPi Interface status register (port 0x56)to determine the

status of the Interface and Pi Server App. This function should

return zero when Pi is responding, and 1 when not listening for commands.

Input : None

Output : Flag C: Set when Pi not responding.

Registers : AF is modified

Usage notes: Pi is determined as responding when I/O control port 56h returns zero. This routine loop 65535 times before it will return with error (zero not detected on that port).

PIEXCHANGEBYTE

Label : PIEXCHANGEBYTE

Purpose : Send a byte to Pi (write to data port 5AH) and read a byte back. Usually,

the byte read at this cycle is meaningless because Pi send whatever is available

on its internal register during any transfer. If you send a byte expecting to

receive a valid response, than you must call this function a second time (this is

because Pi needs time to process your byte and execute whatever command it

need to produce the expected answer).

Input : Register A: byte to send.

Output : Flag C: Set if there was an error

Register A: byte received

Registers : AF is modified

PIREADBYTE

Label : PIREADBYTE

Purpose : Read a byte from the MSXInterface. This command send value 0 to control port

56h, then call CHKPIRDY to know when a byte is available to be read. In the

sequence, the routine read data port 5Ah and return the byte in register A.

Input : None.

Output : Flag C: Set if there was an error

Register A: byte received

Registers : AF is modified

PIWRITEBYTE

Label : PIWRITEBYTE

Purpose : Send a byte to Pi. This function call CHKPIRDY to know when Pi is available to

receive data, and in the sequence write the data to the data port 5Ah.

Input : Register A: byte to send to Pi

Output : None

Registers : No registers are modified

SENDIFCMD

Label : SENDIFCMD

Purpose : Send a single-byte command to the MSXInterface (port 56h).

Input : Register A: Byte/Command to send.

Output : None.

Registers : None.

Usage notes: Current implemented commands are:

- Reset (0FFH) – Sending 0FF will force a RESET of the MSXPi interface internal state.
- Status (00h) – Reading this port will report the MSXPi state, being 0 = available.

SENDPICMD

Label: SENDPICMD

Purpose: Send a command to Raspberry Pi

Input:

DE = should contain the command string

BC = number of bytes in the command string

Output:

Flag C set if there was a communication error

Modifies: AF, BC, DE, HL

RECVDATA

Label: RECVDATA

Purpose: Receive a block of data from PI. Calculate CRC using simple XOR of bytes received, and exchange with Pi at the end of the transfer.

Input:

DE = memory address to write the received data

Output:

Flag C set if error

A = error code

DE = Original address if routine finished in error,

DE = Next current address to read if finished successfully

Modifies: AF, BC, DE, HL

SENDDATA

Label: SENDDATA

Purpose: Send a number of bytes to Pi. Calculate CRC using simple XOR of bytes received, and exchange with Pi at the end of the transfer.

Input:

BC = number of bytes to send

DE = memory to start reading data

Output:

Flag C set if error

A = error code

DE = Original address if routine finished in error,

DE = Next current address to read if finished successfully

Modifies: AF, BC, DE, HL

Note: There are more useful routines available as part of the MSXPI BIOS. Read the msxpi_bios.asm source code for details. Useful routines are:

- LOADBINPROG
- PRINT
- PRINTDIGIT
- PRINTNUMBER
- PRINTPISTDOUT
- NOSTDOUT
- STRTOHEX
- CHECK_ESC

## BIOS Functions Address Table in ROM

This table show the actual addresses for the MSXPi bios functions in the ROM. To use these functions, the slot where MSXPi is connected must be first identified, and then an interslot call can be made to the required address.

Note that the functions are not aware of slot switching and ram banks, which means that any buffer provided to the function must be directly accessible by the function.

Note:Address valid for ROM build 20171230.00077.

Address | Function
75CC | MSXPIVER
75D2 | MSXPISTATUS
75FA | MSXPILOAD
79D8 | RECVDATABLOCK
7A0B | SENDDATABLOCK
7A44 | SECRECVDATA
7A74 | SECSENDDATA
7AA0 | READDATASIZE
7AAD | SENDDATASIZE
7D50 | CHKPIRDY
7D61 | PIREADBYTE
7D6F | PIWRITEBYTE
7D77 | PIEXCHANGEBYTE
7D4D | SENDIFCMD
79D4 | SENDPICMD
7B6C | CHECKBUSY
7B86 | PRINT
7BA4 | PRINTNLINE
7BAF | PRINTNUMBER
7BC4 | PRINTDIGIT
7BD3 | PRINTPISTDOUT
7858 | 79AA
7AB6 | DOWNLOADDATA
7BB6 | UPLOADDATA
7703 | MSXPISEND
772B | MSXPIRECV
7642 | MSXPI

To identify the MSXPi slot, you need a search routine (not currently provided). Different methods can be used to find where MSXPi is connected, but you can use the following addresses and string patterns:

Address | String
780A | MSXPi Hardware Interface v0.7
782B | MSXPi ROM v0.8.2
7849 | <14 characters in this position contain the build id>

## MSXPi Server

Soon.

# SPI Implementation in the MSXPi Interface

Communication between MSX and Raspberry Pi is facilitated by the MSXPi Interface, which implements a serial protocol using CPLD technology. The protocol uses five GPIO pins and full duplex transfers.

The GPIO pins implements the signals:

- CS (Enable signal from MSX, tells Pi that transfer should start)
- SCLK (Clock signal from Pi, tells MSX when to drive GPIO signals)
- MOSI (Data from MSX to Pi)
- MISO (Data from Pi to MSX)
- SPI_RDY (Ready signal, tells MSX when Pi is read to start a byte transfer)

When Pi is ready to process a transfer, it drive the SPI_RDY signal high.

When MSX wants to start a byte transfer, it checks SPI_RDY. If it is high, MSX drive CS low.

When CS toggle states, Pi jumps to an interrupt function to process the transfer if the signal went low. In this case, it also drive SPI_RDY low to tell MSX that it cannot send another byte.

PI starting generating the clock signal SCLK to synchronize the transfer, and send the 8 bits to MSX. MSX will receive each bit and use bit shift to store in a buffer.

When 8 bits are transferred, PI bring SPI_RDY high again to tell MSX that it can receive more data. The MSXInterface will keep the byte in its buffer. MSX can now send a read command to port 0x5A to get the byte.

In a higher level, data is transferd in blocks of pre-defined sizes, with a sequence illustrated in the sequence diagram in picture 2. This sequence is implemented in both P commands and BASIC call commands.

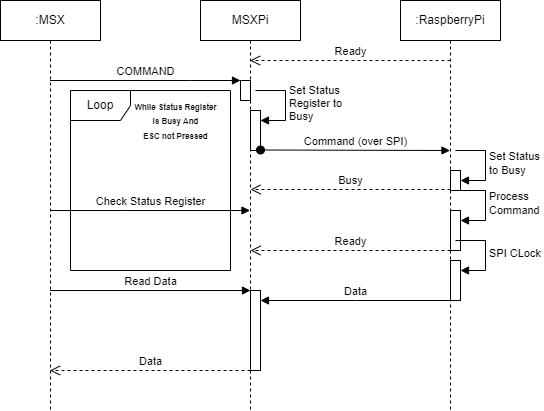
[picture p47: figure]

Illustration 2: Diagram Sequence for the Interface

# Appendix

## Development Tutorial

This appendix will be expanded (hopefully some day) with some useful contents.

As for now, please refer to the Documents/DevTemplate directory in the git repository for a template to use for development.

Also refer to the source codes available, specially under Client directory, for examples of implementation.

### For ROM-less MSXPi

MSXPi BIOS can be used by loading the msxpiext.bin from BASIC. This extension will load itself as a cartridge and implement all the BIOS routines and CALL commands found in the EEPROM.
This extension needs a MSX with 64K of RAM.

## Appendix 2: Pi - GPIO Pin Numbering


Illustration 4: GPIO models B +, 2, 3 and Zero.

The GPIO numbering of illustration 4 is valid for B +, 2, 3 and Zero models.


Illustration 5: GPIO models B +, 2, 3 and Zero.

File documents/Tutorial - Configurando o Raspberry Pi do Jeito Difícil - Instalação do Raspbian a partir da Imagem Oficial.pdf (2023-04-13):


* Esta é uma Contribuição do Desenvolvedor MSXPi Retropix Brazil * Esse tutorial irá ajudá-lo de forma simples, direta e didática a preparar e instalar todo o software necessário no cartão Micro SD para utilização de seu MSXPi.

## Baixando o software de instalação para o Raspberry Pi OS

1º. Acesse o link https://www.raspberrypi.com/software para baixar e executar o software que irá instalar o Raspberry Pi OS em seu cartão micro SD.

2º. Baixe o instalador para a plataforma que melhor lhe agradar. As opções são para Windows, macOS e Ubuntu.
Nesse tutorial faremos a instalação utilizando o Windows 10.
3º. Após baixar o arquivo imager_1.7.4.exe (última versão até o momento) em sua área de download. Clique nele para executar.


4º. Clique em Install e aguarde a instalação do aplicativo que vai te ajudar a criar o cartão SD com o Raspberry Pi OS.

5º. Clique em Finish para finalizar a instalação e executar o programa de criação de imagem no Cartão SD.

## Instalando corretamente o Sistema Raspberry Pi OS

1º. Insira o cartão Micro SD que você deseja utilizar no seu Computador.

2º. Com o aplicativo aberto e o cartão Micro SD já inserido, clique primeiramente em CHOOSE OS.


3º. Escolha a opção Raspberry Pi OS (Other) para escolher a versão que utilizamos no MSXPi.


4º. Escolha a opção Raspberry Pi OS Lite (32-bit)

5º. Agora clique no botão CHOOSE STORAGE para escolher o seu cartão Micro SD e instalar o Raspberry Pi OS


6º. Clique no botão de Engrenagem para configuramos as opções para acesso remoto no Raspberry Pi OS via computador

7º. Marque Set hostname

8º. Marque também a opção Enable SSH


9º. Coloque o usuário e senha para acesso ao sistema (sugestão: usuário: pi e senha: raspberry)

10º. Configure também sua rede WIFI, colocando o SSID (nome da sua rede) e a Senha

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

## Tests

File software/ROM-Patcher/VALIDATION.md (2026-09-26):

# Validation record

## Timeout update

The current payload increases PAYLOAD_WAIT to 18 passes of 65,535 polls,
preserving BC and DE and returning carry on exhaustion. Its executable/state
portion is now 1858 bytes. The asset and profile were rebuilt with sjasmplus
1.24.0, without errors or warnings. The hashes and live emulator results below
describe the previous release, not hardware validation of this timeout change.
The updated build passes all 13 patcher checks, including original-ROM and
server mapper scanner checks. Physical Raspberry Pi validation remains pending.

Build date: 2026-09-25.

Input Goonies ROM (32768 bytes):
`2ba602b1a17e4797da1588afe6e65640331c15746bf5959f4778b404be929dde`

Default output, ASCII16 (65536 bytes):
`208c20cf2876bfc8a81003a625df9f8c8e1279df650ac9b13d0c62593e8fbcdd`

Preassembled resident asset (8192 bytes; executable/state portion 1851 bytes):
`68612d72a71f2651512eb467c6220ba3afd8b121fd1da76d3f672a74eb4e8617`

## Completed checks

- Assembly: sjasmplus 1.24.0, zero errors and warnings.
- Python: 13 checks passed, including original-ROM validation and a regression
  against the actual server mapper scanner. Covered size/hash/expected bytes,
  output preservation, overlapping regions, asset containment/checksums,
  duplicate JSON keys, filename capacity, multiple mappings/modes, native-only
  mappings, double-NUL lists, and scanner-safe filename storage.
- Windows Python 3.11 and Linux Python 3.12 generated identical default ROMs.
- Z80 execution in openMSX, Canon V-25, speed 100: valid PID parsing, play then
  loop, stopping the previous PID before switching, deduplication, grace period,
  sustained-silence stop, and selective native PSG volume filtering.
- Failure execution: actual transport with no MSXPi attached latches fallback
  after the first exchange; subsequent frames do not retry. A reply with a
  numeric prefix followed by invalid text also falls back and discards the
  partial PID. Native music volume and effects remain available.
- Filename regression: `x2ab.mp3` is corrupted by an unprotected server scan;
  the protected list survives the same scanner and the Z80 code emits exactly
  `music play x2ab.mp3` after decoding.
- Live transport: Canon V-25 + MSXPi + ram4mb, Archive option 5, fresh profile ROM
  loaded using the corrected existing msxarch and boot disk at speed 100.
  The real server returned decimal IDs to `music loop`. Ctrl+Shift+F5 sent
  `music stop` for the currently owned ID, consumed its reply, cleared the
  active bootstrap header, and returned to DOS without another game entry.
  `music getids` afterward did not include the stopped test ID.
- Active gameplay was separately confirmed visually in Scene 01-01, with
  native state `5,1`, player flag set, and melodic IDs `9B` on the channels.
  The same external loop PID survived the transition into play and was stopped
  only by the exit shortcut. The test uses two Space presses to leave the
  attract sequence and start the game; F1 is not the start control.

The ROM served from cache, the ROM in gameroms, and the generated output have
the same hash. The existing audited ROM, original ROM, server source, loader,
and boot disk were not changed by this framework implementation.

## Scope and limits

Live tests used the Windows MSXPi server and openMSX; they are not a physical
Raspberry Pi / MSX hardware certification. Audio control was verified through
commands, replies, PID ownership, and native PSG register output.

The initial profile intentionally retains one default MP3 for the recognized
melodic range. Individual song/event naming remains separate analysis work;
the configuration and runtime already support different filenames and modes
for those IDs. There is no simultaneous external playback.

The current loader is a runtime prerequisite. No new loader changes were
needed, so this implementation did not require modifying or retesting the
VAMPIRE mapper cache code. The earlier loader regression test remains separate.

An external emulator close/reset bypasses the exit shortcut. An unreachable
server cannot be told to stop an already-running player; this is distinct
from the verified native-audio fallback behavior.

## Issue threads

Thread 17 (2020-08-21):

Commands that output to stdout finished with CRCERROR

costarc, 2020-08-21:
The recvdatablock was changed to calculate CRC16, but the PRINTPISTDOUT and NOSTDOU was not. It needs the same change to stop showing the CRC error.

costarc, 2020-09-03:
This was fixed adding crc16 checks also to the printstdout routines.

Closed 2020-09-03.

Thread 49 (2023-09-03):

MSX-DOS 1.03 Cold boot sometimes hang after MSXDOS.SYS

costarc, 2023-09-03:
This happens in my Zemmix, not sure happens to other users & computers.
Because the Zemmix has a reboot button, a simple reboot and it will boot ok in the second time.

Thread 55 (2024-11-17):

MSXPi power supply leaking to MSX

costarc, 2024-11-17:
If the RaspberryPi is powered by an external power supply (usb), the MSX will also be powered up.
A dione could be added to the circuitry to block current flowing from RPi to MSX.

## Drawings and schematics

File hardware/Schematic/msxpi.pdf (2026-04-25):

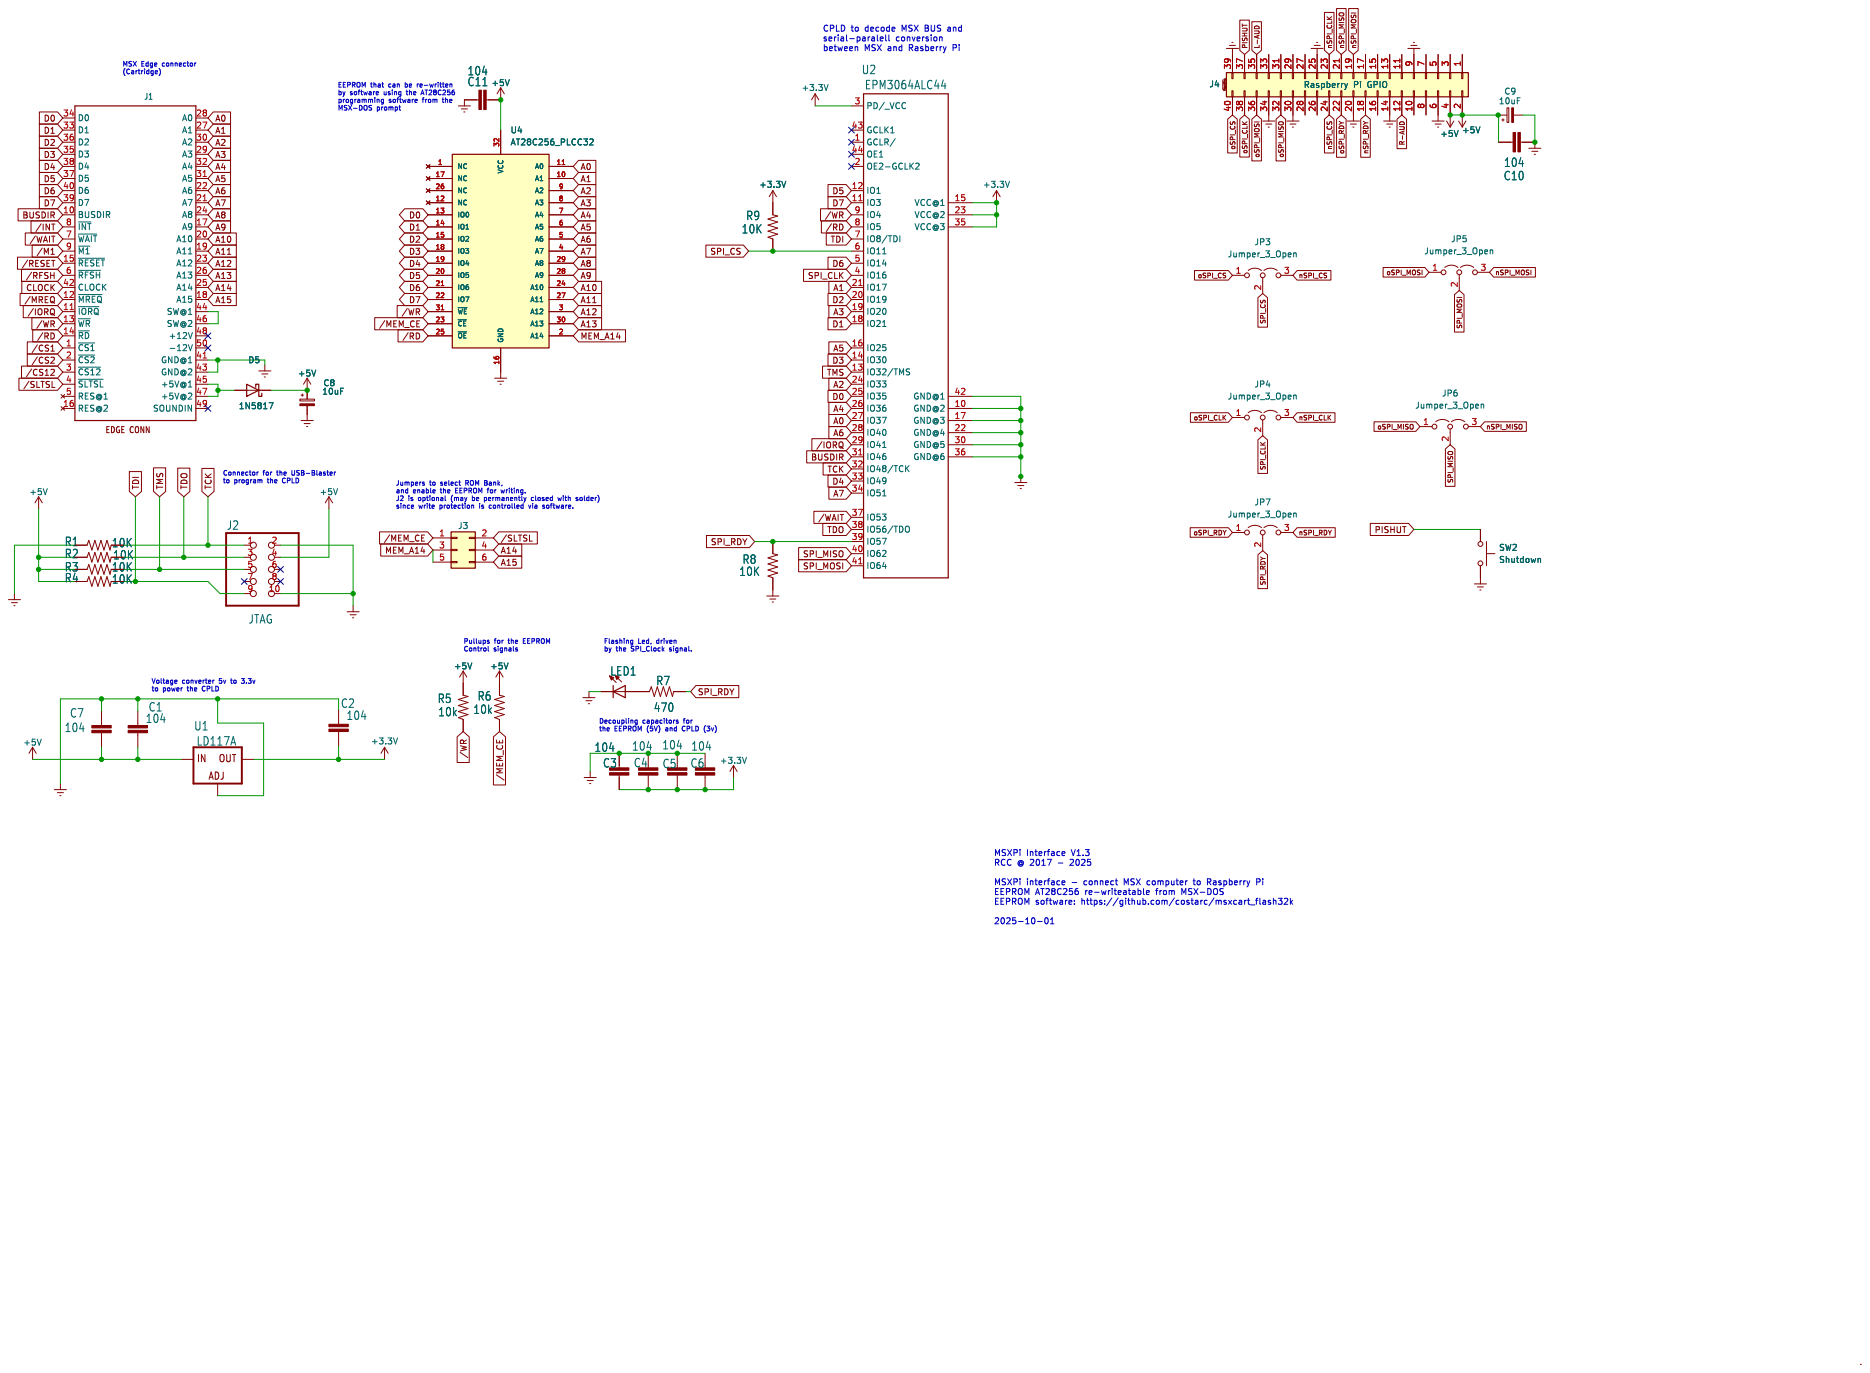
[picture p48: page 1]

CPLD to decode MSX BUS and
between MSX and Rasberry Pi
EPM3064ALC44

-12V 50 GND@1 41 GND@2 43 +5V@1 45 +5V@2 47 SOUNDIN 49 D0 34 D1 33 D2 36 D3 35 D4 38 D5 37 D6 40 D7 39 BUSDIR 10 ~{INT} 8 ~{WAIT} 7 ~{M1} 9 ~{RESET} 15 ~{RFSH} 6 CLOCK 42 ~{MREQ} 12 ~{IORQ} 11 ~{WR} 13 ~{RD} 14 ~{CS1} 1 ~{CS2} 2 ~{CS12} 3 ~{SLTSL} 4 RES@1 5 RES@2 16

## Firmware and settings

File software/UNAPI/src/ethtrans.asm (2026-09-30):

; MSXPi Interface
; Version 1.6.1
; ------------------------------------------------------------------------------
; MIT License
;
; Copyright (c) 2015-2026 Ronivon Costa
;
; Permission is hereby granted, free of charge, to any person obtaining a copy
; of this software and associated documentation files (the "Software"), to deal
; in the Software without restriction, including without limitation the rights
; to use, copy, modify, merge, publish, distribute, sublicense, and/or sell
; copies of the Software, and to permit persons to whom the Software is
; furnished to do so, subject to the following conditions:
;
; The above copyright notice and this permission notice shall be included in all
; copies or substantial portions of the Software.
;
; THE SOFTWARE IS PROVIDED "AS IS", WITHOUT WARRANTY OF ANY KIND, EXPRESS OR
; IMPLIED, INCLUDING BUT NOT LIMITED TO THE WARRANTIES OF MERCHANTABILITY,
; FITNESS FOR A PARTICULAR PURPOSE AND NONINFRINGEMENT. IN NO EVENT SHALL THE
; AUTHORS OR COPYRIGHT HOLDERS BE LIABLE FOR ANY CLAIM, DAMAGES OR OTHER
; LIABILITY, WHETHER IN AN ACTION OF CONTRACT, TORT OR OTHERWISE, ARISING FROM,
; OUT OF OR IN CONNECTION WITH THE SOFTWARE OR THE USE OR OTHER DEALINGS IN THE
; SOFTWARE.
; ------------------------------------------------------------------------------

; =============================================================================
; MSXPi Ethernet UNAPI - ISR-safe transport core
; =============================================================================
; Everything here may be entered from InterNestor Lite's 50/60 Hz timer
; interrupt handler.  That imposes four hard rules, and every one of them is a
; deliberate departure from the stock msxpi_bios.asm primitives:
;
;   1. NO KEYBOARD ACCESS.  CHKPIRDY does `ld a,7 / out ($AA),a / in a,($A9)`
;      once per call and is called twice per byte.  Port $AA is the PPI
;      keyboard row-select register; writing it 60 times a second from inside
;      the interrupt corrupts the BIOS keyboard scan, which is exactly what a
;      telnet client depends on.
;
;   2. BOUNDED SPINS.  CHKPIRDY_POLL loops forever if the Pi never answers.
;      Inside an ISR that is a dead machine.  Every wait here is counted, and
;      a timeout latches ETH_DEAD so that subsequent calls fail immediately
;      instead of spending the whole interrupt slot spinning again.
;
;   3. RE-ENTRANCY.  A client calling ETH_SEND_FRAME from the foreground can be
;      interrupted by INL calling ETH_IN_STATUS.  ETH_LOCK is a DI-protected
;      test-and-set; the loser returns "nothing to do" rather than interleaving
;      bytes into the middle of someone else's transaction.
;
;   4. WAIT MODE IS PER-TRANSACTION.  It is turned on inside the lock and
;      always turned off before returning, so the rest of the system always
;      finds the device in legacy mode.
;
; -----------------------------------------------------------------------------
; Two backends
; -----------------------------------------------------------------------------
; ETH_MODE selects how a byte moves.  The installer detects it and patches it
; here before the hook goes live.
;
;   ETH_MODE = 1  WAIT   real MSXPi v1.6+ with hardware /WAIT.
;                        `out ($5A),a` and `in a,($5A)` each start a transfer
;                        AND stall the Z80 until it completes, so OTIR/INIR
;                        work and cost 21 T-states per byte.
;
;   ETH_MODE = 0  POLLED MSXPi before v1.6, or /WAIT not usable.
;                        A read must be requested by writing $56, then the
;                        status port polled, then $5A read.
;
; openMSX emulates the CPLD at port level, so both paths run there unchanged.
; =============================================================================

CTRL1:      equ     56h             ; status / read-request / reset
CTRL2:      equ     57h             ; version + wait-mode register
DATA1:      equ     5Ah             ; data

WAITMODE_ON:  equ   01h

; $57 read value with wait mode on ($0E with it off).
VER_WAIT_ON:  equ   8Eh

; Polled-mode spin limit, in iterations of an ~30 T-state loop.  2048 is about
; 17 ms at 3.58 MHz: comfortably longer than the Pi's worst observed per-byte
; latency, and short enough that a single failure does not eat several
; interrupt slots.  It only ever runs to completion when something is broken.
;
; The live value is (ix+o_ETH_TMO), counted in units of 256 iterations, and
; NOT because anyone wanted it adjustable: the very first transaction after a
; cold boot is much slower than every later one, because the other end builds
; its Ethernet shuttle lazily - importing the module and opening the TAP
; device - when the first opcode arrives.  With a fixed 17 ms budget that
; first transaction times out, and then the reply lands in a queue nobody is
; reading: every later transaction reads the previous one's answer.  That is
; not a lost call, it is permanent desync, and it is what made ETHTEST report
; the probe's "ETH" signature as the MAC address.
;
; So the work area starts at zero, which this loop reads as the LONGEST
; budget (65536 iterations, about half a second), and ETH_DETECT drops it to
; the normal value once the link has answered once.
ETH_TIMEOUT:  equ   2048

; ETH_MODE values.
MODE_POLL_HW:   equ   0     ; polled ($56 = 0 when done)
MODE_WAIT:      equ   1     ; hardware /WAIT, INIR/OTIR

; =============================================================================
; State
; =============================================================================
; Every mutable byte lives in the work area IX points at - see
; asm-common/include/unapi_wrk.inc for the offsets and for why.  The ROM build
; cannot write to itself, and keeping a separate ROM copy of this file was not
; an option, so BOTH builds reach their state through IX.
;
; MODE_UNKNOWN is what the ROM build starts with.  The transport cannot be
; probed at INIENV time, because on real hardware the Pi is usually still
; booting then and a probe would fail and lock us into the slow backend for
; the rest of the session; detection is deferred to the first UNAPI call.
MODE_UNKNOWN:   equ   0FFh

; How many consecutive failures before declaring the link dead.
;
; Latching on the FIRST failure was wrong.  On real hardware a transaction
; fails roughly once every 1400-2000 calls, and latching immediately turned
; that single glitch into permanent loss of networking: ETHBENCH reported 2032
; of 2048, meaning it worked 2032 times and then every remaining call was
; refused.  For InterNestor Lite, polling ETH_IN_STATUS sixty times a second,
; that would mean the network dies within the first minute and never returns.
;
; A transient deserves a retry; a genuinely absent Pi still gets given up on
; quickly, since eight consecutive timeouts cost well under a second.
ETH_MAXFAIL:  equ   8
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

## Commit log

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2020-08-29 Revert "Merge pull request #24 from costarc/feat/pcb_v1.0_Rev2"
    This reverts commit 94b89420ef207e7a6e2cb686c7e3e51cf4cb4e11, reversing
    changes made to d312857454f621d34b7fa6901ed79bdff1352086.
    [MSXPi1.kicad_pcb, MSXPi1.sch]
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2020-08-29 Revert "Fix/pcb v11 rev1"
    [msxpi.brd, msxpi.sch]
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2020-09-03 Significant changes to cpld logic, saving cells and adding capacity to handle longer bus sizes; reengineering of bios to support new transfer protocol; crc16 error check more robust
    [msxpi.brd, msxpi.sch]
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2022-11-02 Reversed master branch to Interface v0.7 Rev7 and software v0.8.2
    [MSX_Interface.smp_dump.txt, msxpi.brd, msxpi.kicad_pcb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]
2022-11-15 Replaced 27c256 by at28c256
    [msxpi.kicad_pcb, msxpi.kicad_sch]
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2022-12-13 v1.0.1 Rev 1 - Added some silk that was missing
    [bom-msxpi.csv, msxpi.kicad_pcb, msxpi.kicad_sch]
2022-12-13 Fixed silk text; Deleted old directories; v1.0.1 Rev 1
    [bom-msxpi.csv, msxpi.brd, msxpi.kicad_pcb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]
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2022-12-17 Changed CPLD pinout in QSF file to the new layout for this schematic. Not compatible with previous VHDL design due to pin changes
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2023-04-15 fixed erro in plcc44 footprint
    [msxpi.kicad_pcb]
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2023-05-06 Removed silk for RESET signal, because it does not work and may be unsafe on most computers
    [msxpi.kicad_pcb, msxpi.kicad_sch]
2023-05-06 Added 1uf capacitor to RESET line
    [msxpi.kicad_pcb, msxpi.kicad_sch]
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2024-06-16 fixed schematic corrupted
    [msxpi.kicad_sch]
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2025-09-07 Revised schematic to 1.2 with pullups/down do SPI CS & MOSI. Capacitors also replaced
    [msxpi.kicad_pcb, msxpi.kicad_sch]
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2025-09-12 Added shtudown via push button and interrupt in the msxpi-server; removed defintely the reset circuit
    [msxpi.kicad_pcb, msxpi.kicad_sch]
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2025-10-01 Fixed trace under golden fingers
    [msxpi.kicad_pcb]
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2025-10-17 Fixes to BASIC program to run in openMSX; Updates to PCB silk
    [msxpi.kicad_pcb, msxpi.kicad_sch]
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2026-08-05 Add EXECROM /W option: load MegaROM games over MSXPi network into MegaRAM
    EXECROM v1.3 can now fetch a MegaROM directly from the MSXPi server
    (execrom /W <file>, resolved against the current "p cd" path) instead of
    disk, reusing the existing MegaRAM bank-switching/page-setup loop unchanged.
    Supports Konami, ASCII8 and ASCII16 mappers, with a signature-based guessr
    detection (megatbl/konatab lookup) that mirrors the disk path's own
    MegaROM-to-MegaRAM bank-switch-opcode conversion so network-loaded games
    get the same patching disk-loaded ones do.
    Server side: msxpi-server.py gains an execrom() command for direct
    by-filename fetch, and detect_mapper() no longer rejects Konami SCC ROMs
    (reporte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
2026-08-06 Fix checksum-mismatch retry asymmetry in the MSXPi block-transfer protocol
    msxpi-server.py's senddata_oneblock/recvdata2/recvdata2_oneblock all retry
    (resend the identical block) on a checksum mismatch, but msxpi_bios.asm's
    SENDDATA and RECVDATA_ONEBLOCK both aborted on the first mismatch instead
    of resending/waiting - desyncing the wire protocol for whatever ran next
    (a disk read, another command). This is shared by every MSXPi client
    (EXECROM.MAC, msxpi-driver.mac's disk boot path, etc), so it wasn't
    specific to any one of them.
    Both routines now retry up to GLOBALRETRIES times, matching the server.
    Since msxpi_bios.asm is sometimes linked straight into ROM (msxpidos.rom),
    the retry state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
2026-08-07 Checkpoint: per-block ploadr protocol redesign (has known bug)
    Restructures ploadr's body transfer from one handshake covering the
    whole ROM to one fresh "ploadr <file> <index> <blocksize>" command per
    block, matching how dskiords/dskiosct already work - intended to close
    the window where a monolithic multi-block command left the server's
    single-threaded dispatch loop unable to correctly handle any other
    request arriving mid-transfer.
    Known bug at this checkpoint: readpatch_net2 passes the ROM-level
    netblkidx as RECVDATA_ONEBLOCK's expected-index parameter, but that
    parameter is session-relative (sendmultiblock's own block_index always
    starts at 0 for a fresh call) - causes a validation mis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
2026-08-07 Fix readpatch_net2 passing ROM-level index to RECVDATA_ONEBLOCK
    RECVDATA_ONEBLOCK's expected_block_index parameter is session-relative
    (sendmultiblock's own block_index counter always starts at 0 for a
    fresh call - confirmed by both searchpatch_first's own header fetch and,
    independently, by two already-proven, unrelated call sites: p.c's
    SetDateTime() and msxpi-driver.mac's DSKIO_READ_LOOP, both of which
    already pass a hardcoded 0/xor a for exactly this reason).
    readpatch_net2 was instead passing the ROM-level netblkidx (0, 1, 2...).
    This coincidentally matched on block 0, then mismatched on every block
    after, failing RECVDATA_ONEBLOCK's own index validation before the
    payload loop starts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
2026-08-07 Add ploadr.com/LOADRP97.COM network ROM loading, retire ExecRom
    Adds MSXPi network loading for plain and MegaROM (Konami/SCC, ASCII8,
    ASCII16) images: a per-block ploadr server command with checksum-retry
    transport, ploadr.com as a standalone loader, and a binary patch of the
    third-party LOADROM.COM (both v1.0 and v1.97) that redirects its file
    I/O to the network while leaving all of LOADROM's own mapper/bank-switch
    logic untouched. The v1.97-based patch (LOADRP97.COM, rebranded "loadrom
    2.0P") supersedes v1.0-based LOADRPI.COM on hardware where v1.0's own
    handoff bugs got fixed upstream.
    Moves the loadrom patch sources from Client/src/ExecRom/loadrom_patch_src
    to Client/src/loadrom (bringi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
    [emul_start_config.txt]
2026-08-07 Bump MSXPi version to v1.5, rebuild driver ROM
    - MSXPi Driver banner (ROM/src/MSX-DOS/msx-dos.mac, msxpi-driver.mac)
    bumped from v1.4 to v1.5, matching the BIOS files (msxpibios.asm/
    msxpiext.asm), which already said v1.5.
    - Adds a "MSXPi v1.5 Release Notes" section to the root README.md,
    summarizing this release's actual changes (network MegaROM loading via
    ploadr/loadrom, ExecRom retirement, transport/path-resolution fixes) -
    existing v1.4/v1.3/... sections are left as historical record, not
    renamed.
    - Rebuilds target/msxpidos.rom from the updated source (msx-dos.mac,
    which includes msxpi-driver.mac) and redeploys it to the openMSX
    systemroms copy and both msxpiboot.dsk ima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
2026-08-08 Fix CALL MSXPI mode 2 reliability and IRC client issues
    CALL MSXPI("2,...") save-to-buffer mode was unreliable on failure and
    on some successful transfers:
    - RECV_ERROR never wrote a header on failure, leaving stale buffer
    data that callers misread as a valid response
    - RECV_LOOP's terminal-code check was stricter than mode 1's,
    discarding valid responses that didn't match one exact code
    - header_rc and length were corrupted across RECVDATA_ONEBLOCK's
    register-bank dance during long network waits; both are now stashed
    in the driver's GETWRK workarea instead of trusted registers
    IRC.BAS: added memory-safe CLEAR to protect BASIC's own program space,
    fixed a blank line printed on every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
    [emul_start_config.txt]
2026-08-08 Fix build script version-bump not persisting, update README
    The build script's UpdateBuildId/UpdateBuildIdASM functions matched
    the sed replacement pattern by reconstructing and escaping the
    existing BuildId line, which could silently fail to match without any
    visible error - the script would print "New BuildId..." every run
    while the file never actually changed. Replaced with a simpler pattern
    that matches the line by its anchor alone and replaces it whole, plus
    a verification check so a failed write is reported instead of silently
    claimed successful.
    Also updates README.md's v1.5 release notes wording, and includes the
    BuildId bump + rebuilt artifacts from a successful ./build run.
    Co-Au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
2026-08-15 Restore historical msxpidos.rom build (sha1 c429077a...)
    Restores the openMSX extension ROM as it existed in commit d79b730d
    ("MSXPi improvements to recover from interruptions", Sep 25 2025 -
    tracked there as msxpibios.rom, the deployed filename at that point in
    project history, later renamed to msxpidos.rom). Saved alongside the
    current ROM with the checksum in the filename so it doesn't collide
    with or overwrite the latest build.
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2026-08-30 MSXPi v1.6: CPLD hardware /WAIT flow control, SPI engine rewrite, server profiling
    CPLD (hardware/CPLD_Project) - validated on real hardware in legacy mode:
    142 KB transferred error-free via "p run cat msxpi-server.py".
    - Rebuild the SPI engine around a sentinel shift register, replacing the
    three-state FSM, the 3-bit bitcount and its adder. The sentinel is loaded at
    bit 0 and MISO shifts in beneath it, so it is always the highest set bit and
    both phase tests need no counter. 14 storage elements become 10; the edge map
    msxpi-server.py sees is unchanged.
    - Add hardware /WAIT flow control per WAIT_STATE_SPEC.md, default OFF. With the
    mode enabled a plain IN ($5A) both starts the tr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
2026-08-30 openMSX: split the launcher config per extension
    emul_start_config.txt hardcoded the MSXPi extension, so testing against a
    different cartridge meant editing it in place. Replace it with one config per
    extension and a launcher for each:
    - emul_start_config_MSXPi.txt / startOpenMSX.bat
    - emul_start_config_MFRSCCSD.txt / startOpenMSX_MFRSCCSD.bat
    Both target machine Canon_V-25. The MSXPi config keeps ext Ram2Mb.
    [emul_start_config.txt, emul_start_config_MFRSCCSD.txt, emul_start_config_MSXPi.txt]
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2026-08-31 Fix an ETH_RESET reply-length desync, and add ETHBENCH to measure /WAIT
    ETH_RESET read one byte of its reply where the Pi sends two. Every fast op
    answers with a result code followed by its payload, and OP_RESET's payload is
    one byte, so reading only the result code left a byte on the wire and every
    later transaction read shifted data - a silent desync rather than a clean
    failure. ETHTEST never called ETH_RESET, which is why nothing caught it until
    now. Audited every other fast op against msxpi_eth.py's FAST_REPLY_LEN; this
    was the only mismatch.
    ETHBENCH.COM times the same loop under each transport backend on one machine
    with nothing printed inside the timed section, to establish what hard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
2026-08-31 Make a dead link distinguishable in ETH_GET_HWADD
    The segment's MACADDR cache was seeded with 02:4D:53:58:50:69 - byte for byte
    what msxpi_eth.BaseLink sends. ETH_GET_HWADD falls back to that cache when the
    transaction fails, so a diagnostic printed the same "correct" MAC whether the
    wire worked or was completely dead. On real hardware that briefly looked like
    proof the round trip worked while ETH_GET_NETSTAT and ETHBENCH were both saying
    nothing was getting through.
    Seed it with zeros instead: a non-zero address now proves a real fetch. INL
    would get zeros if it asked while the link was down, which is honest - the dead
    link is the actual problem in that case.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
2026-08-31 Drop DI from ETH_LOCK: `ld a,i` was leaving interrupts off permanently
    Every ETHBENCH timing on real hardware came back as 0000 jiffies while the
    transfers themselves worked perfectly - poll-hw reported 2048 of 2048
    transactions succeeding. The transfers were never the problem: JIFFY had
    stopped being updated, because interrupts were disabled.
    ETH_LOCK captured IFF2 with `ld a,i`, disabled interrupts around the
    test-and-set, and re-enabled them only if P/V said they had been on. `ld a,i`
    CLEARS P/V if an interrupt arrives while it executes - the documented Z80
    erratum - so the restore concluded "they were off", skipped the EI, and they
    stayed off for the rest of the program. Over 6144 trans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
    [ethtrans.asm]
2026-08-31 ETHBENCH: re-enable interrupts inside the timed loop
    Every pass reported zero jiffies while the control delay loop, run moments
    earlier in the same program, reported 37 - so the clock was running at start
    and stopped once UNAPI calls began. The driver no longer touches interrupts at
    all, which leaves the UNAPI RAM helper: CALL_MAP must disable them while it
    swaps the mapper segment, and if it restores IFF2 with `ld a,i` it hits the
    erratum that clears P/V when an interrupt arrives mid-instruction. After the
    first occurrence interrupts stay off. INL never notices because it calls from
    the timer interrupt, where leaving them off is correct; a foreground loop
    making thousands of calls does noti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
2026-08-31 Verify the transport works before committing to it, instead of trusting $57
    The installer selected hardware /WAIT because port $57 reported the CPLD
    implements the mode register. It does - and wait mode is intermittent anyway,
    because the Pi drops RPI_READY between bytes and an IN ($5A) landing in that
    gap neither stalls nor transfers. So the shipped driver selected a backend that
    does not work: on real hardware ETHTEST reported MAC 000000000000 and Net 00,
    while ETHBENCH forcing polled mode on the same machine passed 2048 of 2048
    transactions in 141 jiffies, reproducible across five runs.
    ETH_VERIFY now runs one OP_PROBE and requires the 'E','T','H' signature back.
    A stale or floating bus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
2026-08-31 Fix the hardware /WAIT race: wait for the Pi before starting a burst
    Wait mode measured as intermittent on real hardware - 2028 of 2048 calls on one
    run, 589 on the next, 369 on the third. The cause is a race at the burst
    boundary, not in the burst itself.
    The CPLD only starts a transfer, and so only asserts /WAIT, while SPI_RDY is
    high, and the Pi raises RPI_READY only once it is inside a transfer routine.
    After receiving our opcode byte it DROPS RDY, runs the Python dispatch
    (recvdata2 -> eth_handle_opcode -> shuttle -> _write_many), and only then does
    SPI_BurstOut raise RDY again for the reply. An INIR issued the instant the
    opcode OUT completes races that dispatch: with RDY still low th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
    [ethtrans.asm]
2026-08-31 ETHBENCH: measure two payload sizes, to separate fixed cost from per-byte cost
    The hardware /WAIT race fix worked - wait mode now returns 2048 of 2048 with
    identical timing across three runs, and the driver selects it and works out of
    the box. But it came out only 7.6% faster than polled (130 vs 141 jiffies),
    against a predicted 8x, and a single payload size cannot explain why.
    A transaction costs fixed + n*b. At n=3 bytes and ~1100 us per transaction,
    roughly 1 ms of that is fixed: the recvdata2 loop, eth_handle_opcode, the
    shuttle dispatch and SPI_BurstOut setup - Python on the Pi, not transport.
    /WAIT only removes per-byte Z80 polling, so with three bytes there is almost
    nothing for it t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
2026-08-31 Resynchronise after a failed transaction, so faults stop cascading
    A wait-mode transaction fails roughly once in 1500 on real hardware, and that
    single fault was killing the link: ETHBENCH reported ok=07F0, meaning 2032
    successes followed by nothing. Raising the tolerance to eight consecutive
    failures did not help, because the failures were never independent - whatever
    bytes of a reply the MSX did not collect stayed queued, so the next transaction
    read them instead of its own and failed in turn.
    ETH_RESYNC writes $FF to $56 - the existing MSXPi reset, what resetMSXPI does
    at the start of every command - clearing the CPLD transfer state and any byte
    waiting to be read. ETH_FAIL now calls it,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
    [ethtrans.asm]
2026-08-31 Bound the burst CS spin so an abandoned burst cannot wedge the Pi
    SPI_BurstOut spun on chip-select with no bound. SPI_ByteTransfer does the same
    deliberately - that one is the server idling for the next command - but a burst
    is different: the MSX has committed to reading N bytes, and if it stops early
    nobody is left to assert CS.
    The driver stops early by design. ETH_RESYNC, added to stop a failed
    transaction poisoning the next one, writes $FF to $56 and abandons the rest of
    the reply. The Pi was then left spinning at 100% CPU indefinitely, which on a
    single-core Pi starves everything else - the symptom being sshd dropping the
    session with "Connection reset by peer" during a benchmark run.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
2026-08-31 Document why every UNAPI call returns with interrupts disabled
    Chased as a suspected bug in this driver, then in RAMHELPR, then as the Z80
    `ld a,i` P/V erratum. It is none of those: the RAM helper reaches a
    segment-resident implementation through BIOS CALSLT, and CALSLT - like RDSLT
    and WRSLT - disables interrupts and does not re-enable them. Every call into a
    RAM-segment UNAPI implementation therefore returns with interrupts off, on every
    MSX, for every implementation including Konamiman's own. Re-enabling is the
    caller's job.
    The driver needs no change and gets none: every spin is bounded, there are no
    timers, and ETH_LOCK no longer uses di. It behaves identically either way.
    Recorded be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
2026-08-31 Get InterNestor Lite running on the driver: build MSR, and fix two INL bugs
    Phase 6's first milestone - a real third-party TCP/IP stack discovering and
    accepting this driver:
    Searching Ethernet UNAPI implementation... OK
    Found MSXPi Ethernet UNAPI v0.1 at slot 2, segment 126
    InterNestor Lite has been installed. Have fun! (^^)/
    Three things were needed.
    MSR.COM. INL 2.1+ requires MSX-DOS 2 compatible mapper support routines, which
    MSX-DOS 1 does not have, and MSR.COM is not distributed as a binary. It builds
    from Konamiman's ramhelpr.asm with INSTALL_MSR=1; the only obstacle was three
    N80-only directives, replaced by a plain equ. Verified rather than assumed:
    building the same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
2026-08-31 Pi-side network setup for a WiFi host, plus UCOUNT diagnostic
    Everything so far has run against MockLink, which answers every opcode
    correctly and carries no traffic at all. This is what puts a real network
    behind the driver.
    Bridging the TAP to the uplink - PiSCSI's approach on wired hosts - cannot work
    here. An access point will not forward frames whose source MAC is not the
    associated station's, so a bridged MSX transmits fine and never receives a
    reply. That is 802.11 association, not something to configure around; PiSCSI
    carries a separate proxyarp mode for the same reason. So the MSX gets its own
    subnet on msxpi0 and the Pi NATs it out through whichever interface holds the
    default rou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
    [INL.CFG]
2026-08-31 Correct the link test: INL has no outgoing ping
    The setup notes told the user to run "ping" on the MSX. INL.COM has no such
    command - it only has a switch controlling whether it REPLIES to incoming
    pings, which is on by default. Test from the Pi instead:
    ping 192.168.99.2
    which covers the whole path - TAP, server, opcode protocol, driver, InterNestor
    Lite - with nothing to type on the MSX, and is a better test for it. Also
    points at HOST.COM and TCPCON.COM as ways to isolate DNS and TCP before
    involving telnet's UI.
2026-08-31 Never enable /WAIT until a bounded polled transaction has succeeded
    ETHUNAPI hung the MSX outright when msxpi-server was not running, on real
    hardware. The CPLD has no /WAIT timeout - wait_assert is held for exactly as
    long as the Pi holds RPI_READY - and RPI_READY is a GPIO that KEEPS ITS LAST
    LEVEL when the server exits. Left high with nothing clocking, a single
    IN ($5A) in wait mode stalls the Z80 for ever: dead machine until a power
    cycle. This is the SR-1 hazard the CPLD spec warned about, arriving by the one
    route the spec did not consider - not the Pi being slow, but the Pi being gone
    while its ready line stayed asserted.
    The installer's mistake was trusting the $57 probe. That prove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
2026-08-31 Add "ETHUNAPI P" to force the polled transport
    Hardware /WAIT is 2.7x faster per byte but it is the only mode that can hang
    the machine: the CPLD holds /WAIT for exactly as long as the Pi holds
    RPI_READY, with no timeout, so a Pi that stops clocking mid-transfer stalls the
    Z80 for ever. The installer now proves the link before enabling it, but that
    only covers the moment of installation - any later caller can still meet a Pi
    that has gone away, and InterNestor Lite hanging the MSX during INL I is
    exactly that.
    Polled is bounded everywhere and cannot hang, so this gives a way to bring new
    software up without that risk and to tell "the driver is wrong" apart from "the
    Pi stopped clocking". De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
2026-09-06 Drain the server's queue on resync; make a dead link recoverable
    Two faults seen on real hardware after quitting a network program, both
    with the Ethernet side still perfectly healthy.
    1. ETH_RESYNC now drains the other end.
    Writing $FF to $56 resets the CPLD but says nothing to msxpi-server.py,
    which is a separate process with its own state machine: a reply it has
    already produced stays queued, and the next command reads that instead
    of its own answer. The disk shares this link, so what the user sees is
    MSX-DOS demanding "Insert a DOS disk in the default drive" moments after
    leaving telnet. ETH_RESYNC's own comment has predicted this since it
    was written, and named the fix.
    There is no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
    [ethtrans.asm]
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2026-09-07 Build scripts, openMSX device, docs and remaining artifacts
    Completes the working tree.
    software/build gains the sjasm step for the UNAPI sources, an exit check
    on zmac - previously the only thing that said whether the ROM was good -
    and a skip for empty files, after a zero-byte binary corrupted the disk
    image midway through and everything written after it was lost. It also
    calls UNAPI/build.sh so the UNAPI tools stay on the boot image, which
    build regenerates from target/ and would otherwise drop.
    .gitattributes pins shell scripts to LF and .CFG files to CRLF. Writing
    these from Windows had repeatedly flipped line endings under them, and
    for INL.CFG that is not cosmetic: with LF only, I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
    [emul_start_config_MFRSCCSD.txt, emul_start_config_MSXPi.txt]
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2026-09-13 MSXPi v1.6: openMSX emulates the CPLD - drop the emulator path
    openMSX now emulates the MSXPi CPLD v1.6 at port level (MSXPiDevice in the
    openMSX fork): $57 reads $0E/$8E, $56 reads 0/1, the write latch, READY and
    /WAIT behave as in MSXPi.vhd. MSX software therefore no longer needs to tell
    emulation from hardware, and every such branch is removed.
    Server (msxpi-server.py)
    - openMSX link speaks "virtual SPI" over TCP: the server offers bytes the way
    the Pi raises READY (01/02 frames), openMSX returns the byte the CPLD
    clocked; hello handshake on accept, cancel for abandoned bursts. An openMSX
    without CPLD emulation still gets the old raw byte link.
    - SPI_ReadPayload/SPI_WritePayload se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
    [ethtrans.asm]
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2026-09-22 Quick Start guide update; fix to msxpi-setup.sh default ini
    [emul_start_config.txt]
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
